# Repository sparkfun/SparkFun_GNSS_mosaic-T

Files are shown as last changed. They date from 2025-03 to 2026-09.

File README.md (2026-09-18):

SparkFun Timing GNSS Breakout - mosaic-T
========================================

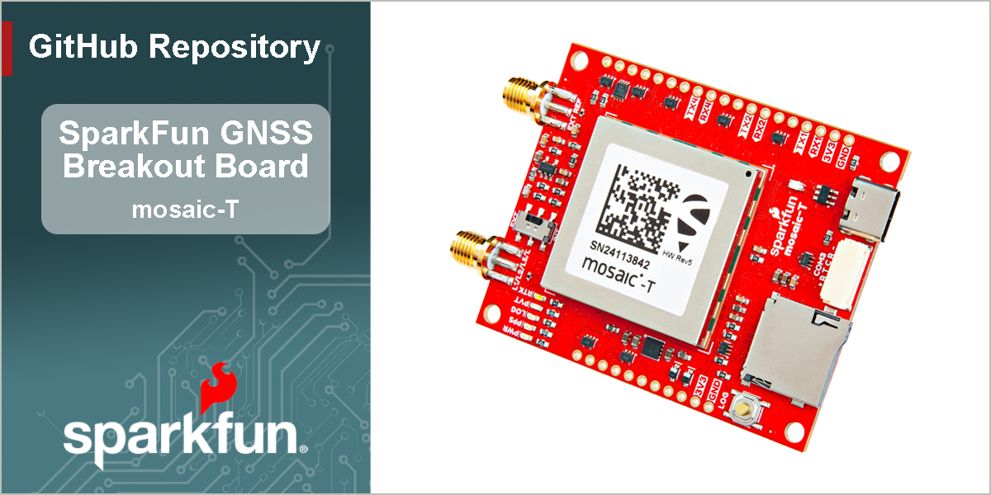
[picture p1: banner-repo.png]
SparkFun Timing GNSS Breakout - mosaic-T


[*SparkFun Timing GNSS Breakout - mosaic-T (GPS-28731)*](https://www.sparkfun.com/sparkfun-timing-gnss-breakout-mosaic-t.html)

At the heart of our Timing GNSS Breakout is [Septentrio](https://www.septentrio.com/en)'s mosaic-T, a compact, ultra-low power, multi-band, multi-constellation, high-precision GNSS timing receiver. It can acheive a timing precision of 5ns (5 billionths of a second), or better than 1ns with an optional subscription to the Fugro AtomiChron® L-band timing service. Event accuracy is better than 20ns. It also features Septentrio's unique [AIM+ technology](https://www.septentrio.com/en/learn-more/advanced-positioning-technology/aim-jamming-protection) for interference mitigation and anti-spoofing, ensuring best-in-class reliability and accuracy.

This board provides easy access to the mosaic-T's reference clock. Want to create your own disciplined oscillator? With this board you can. You can use the `RxClkBias` from the mosaic-T `PVTCartesian` or `PVTGeodetic` SBF messages to discipline your own 10MHz oscillator. The *EXT REF* connector accepts 50 Ohm 10MHz signals in the range -14dBm (min) to +14dBm (max). The *INT EXT* slide switch selects the internal or external oscillator.

The mosaic-T is a sophisticated timing receiver running an internal web server that can be accessed through the USB interface with a standard browser using a Linux/Windows computer. Septentrio also provides dozens of [video tutorials](https://www.youtube.com/@SeptentrioGNSS/videos) to guide users through the configuration settings of their GNSS receivers utilizing the web interface.

Beyond the capabilities of the mosaic-T module, this board is seamless to operate with no programming skills required. Gone are the times when a microcontroller was required to interface with the GNSS receiver and log data to an SD card and when users had to carry around an SD card reader to extract the data from the SD card. The Timing GNSS Breakout - mosaic-T  can start/stop logging data or mount/unmount the SD card, without a single line of code, just utilizing a simple button. For the users who prefer a command-line interface, Septentrio has you covered. Users can still control and configure the mosaic-T module through a CLI, which is useful for scenarios such as production line testing *(in fact, that is how we tested this board)*.

This breakout board is a perfect middle ground for users who would like to integrate the mosaic-T module into a project/enclosure with access to a majority of the module's available pins, similar to Septentrio's developer kit, but in the smaller form factor of their evaluation kit. Or maybe... you just needed a very accurate PPS output at a 3.3V logic level. *Please, check out our [hookup guide](https://docs.sparkfun.com/SparkFun_GNSS_mosaic-T) for more details on the capabilities of this board (that we couldn't fit in this product description).*

> [!CAUTION]
>
> RTK Not Supported
> --------------
> The mosaic-T is a superb GNSS module designed for highly accurate timing applications. **But it does not support RTK. It can not be configured as a RTK Rover or Base. RTCM output is not supported.**

Documentation
-------------

- **[Hookup Guide (mkdocs)](http://docs.sparkfun.com/SparkFun_GNSS_mosaic-T/)** - A hookup guide for the SparkFun mosaic-T Timing GNSS breakout board hosted by GitHub pages.<br>
   

Repository Contents
-------------------

- **[/docs](/docs/)** - Online documentation files
  - [/assets](/docs/assets/) - Assets files
    - [/3d_model](/docs/assets/3d_model/) - 3D models for the board
    - [/board_files](/docs/assets/board_files/) - Design files for the board
      - [KiCad Design Files](/docs/assets/board_files/kicad_files.zip) (.zip)
      - [Schematic](/docs/assets/board_files/schematic.pdf) (.pdf)
      - [Dimensions](/docs/assets/board_files/dimensions.pdf) (.pdf)
    - [/component_documentation](/docs/assets/component_documentation/) - Datasheets for hardware components
    - [/img/hookup_guide](/docs/assets/img/hookup_guide/) - Images for hookup guide documentation - Hookup guide images for the board
    - /Hardware - Hardware design files (.brd, .sch)
      - /Production - Production files

Product Variants
----------------

- mosaic-T:
  - [GPS-28731](https://www.sparkfun.com/sparkfun-timing-gnss-breakout-mosaic-t.html) - mosaic-T Timing GNSS Breakout
  - [SXT](https://www.sparkpnt.com/products/sxt-gnssdo) - GNSS Disciplined Oscillator
- mosaic-X5:
  - [GPS-23088](https://www.sparkfun.com/sparkfun-triband-gnss-rtk-breakout-mosaic-x5.html) - Triband GNSS RTK Breakout - mosaic-X5
  - [SXM-E](https://www.sparkpnt.com/products/sparkpnt-sxm-e-cors) - RTK mosaic-X5
  - [GPS-24903](https://www.sparkfun.com/sparkpnt-rtk-facet-mosaic-l-band.html) - SparkPNT RTK Facet mosaic L-Band
  - Flex Modules:
    - [GPS-28138](https://www.sparkfun.com/sparkpnt-gnss-flex-module-mosaic-x5.html) - GNSS Flex module - mosaic-X5
    - [GPS-29457](https://www.sparkfun.com/sparkpnt-gnss-flex-module-mosaic-x5-im19-imu.html) - GNSS Flex module - mosaic-X5 & IM19
    - [GPS-28766](https://www.sparkfun.com/sparkfun-gnss-flex-phat-mosaic-x5.html) - GNSS Flex pHAT w/ the mosaic-X5 GNSS Flex module
    - [GPS-29889](https://www.sparkfun.com/sparkfun-gnss-flex-phat-mosaic-x5-im19-imu.html) - GNSS Flex pHAT w/ the mosaic-X5 & IM19 GNSS Flex module
- mosaic-G5 P3:
  - [GPS-29208]( - GNSS RTK Breakout - mosaic-G5 P3
  - Flex Modules:
    - [GPS-29209](https://www.sparkfun.com/sparkpnt-gnss-flex-module-mosaic-g5-p3.html) - GNSS Flex module - mosaic-G5 P3
    - [GPS-29363](https://www.sparkfun.com/sparkpnt-gnss-flex-module-mosaic-g5-p3-im19-imu.html) - GNSS Flex module - mosaic-G5 P3 & IM19
    - [GPS-](https://www.sparkfun.com/sparkfun-gnss-flex-phat-mosaic-g5-p3.html) - GNSS Flex pHAT w/ the mosaic-G5 P3 GNSS Flex module
    - [GPS-](https://www.sparkfun.com/sparkfun-gnss-flex-phat-mosaic-g5-p3-im19-imu.html) - GNSS Flex pHAT w/ the mosaic-G5 P3 & IM19 GNSS Flex module

Version History
---------------

- [v10](https://github.com/sparkfun/SparkFun_GNSS_mosaic-T/releases/tag/v10) - Initial Release

License Information
-------------------

This product is ***open source***!

Please review the [`LICENSE.md`](./LICENSE.md) file for license information.

If you have any questions or concerns about licensing, please contact technical support on our [SparkFun forums](https://community.sparkfun.com/).

Distributed as-is; no warranty is given.

- Your friends at SparkFun.

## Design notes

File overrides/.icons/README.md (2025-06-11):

.icons directory
====================
This folder should contain branding logos for the product documentation

## General Images
- `sfe.svg` - SparkFun flame logo
- `kicad-primary.svg` - Full KiCad logo

## Directory
- `logo` - Other available logos

## SVG Optimizer
- [Remove meta data from svg](https://jakearchibald.github.io/svgomg/)

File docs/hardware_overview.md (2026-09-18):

!!! danger "Important: Read Before Use!"
	!!! warning "ESD Sensitivity"
		The mosaic-T module is sensitive to [ESD](https://en.wikipedia.org/wiki/Electrostatic_discharge "Electrostatic Discharge"). Use a proper grounding system to make sure that the working surface and the components are at the same electric potential.

		??? info "ESD Precaution"
			As recommended by the manufacturer, we highly recommend that users take the necessary ESD precautions to avoid damaging their module.

			<div class="grid cards" markdown>

			<div markdown>

			<article class="video-500px" style="text-align: center; margin: auto;" markdown>
			<iframe src="https://www.youtube.com/embed/hrL5J6Q5gX8?si=jOPBat8rzMnL7Uz4&amp;start=26;&amp;end=35;" title="Septentrio: Getting Started Video (playback starts at ESD warning)" frameborder="0" allow="accelerometer; autoplay; clipboard-write; encrypted-media; gyroscope; picture-in-picture" allowfullscreen></iframe>
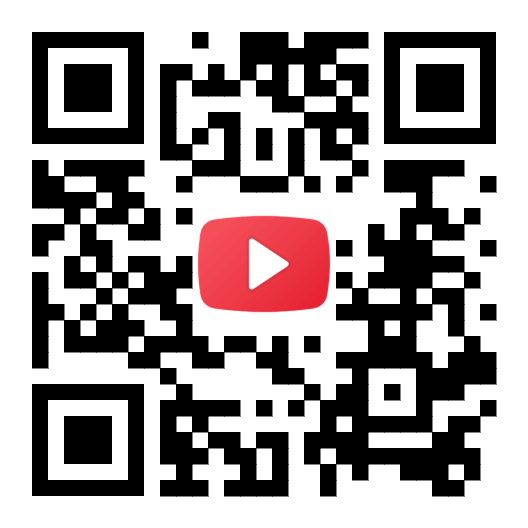
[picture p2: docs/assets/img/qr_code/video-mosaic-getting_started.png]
QR code to play video
			
			</article>

			</div>

			-   <a href="https://www.sparkfun.com/ifixit-anti-static-wrist-strap.html">
				<figure markdown>
				Product Thumbnail
				</figure>

				---

				**iFixit Anti-Static Wrist Strap**<br>
				TOL-25572</a>

			</div>

	!!! warning "Active Antenna"
		Never inject an external DC voltage into the SMA connector for the GNSS antenna, as it may damage the mosaic-T module. For instance, when using a splitter to distribute the antenna signal to several GNSS receivers, make sure that no more than one output of the splitter passes DC. Use [DC-blocks](https://en.wikipedia.org/wiki/DC_block) otherwise.

	!!! warning "External Reference Clock"
		If the switch for an external reference clock is enabled, users must provide a 10MHz input signal. Otherwise, the mosaic-T module will cease to operate, without a clock signal.

## :material-folder-cog: Design Files

<!-- Import the component -->
<script type="module" src="https://ajax.googleapis.com/ajax/libs/model-viewer/3.5.0/model-viewer.min.js"></script>

<div class="grid cards desc" markdown>

-   :kicad-primary:{ .enlarge-logo } Design Files

	---

	- :fontawesome-solid-file-pdf: [Schematic](./assets/board_files/schematic.pdf)
	- :material-folder-zip: [KiCad Files](./assets/board_files/kicad_files.zip)
	- :material-rotate-3d: [STEP File](./assets/3d_model/cad_model.step)
	- :fontawesome-solid-file-pdf: [Board Dimensions](./assets/board_files/dimensions.pdf):
		- 2.50" x 2.00" (635mm x 508mm)

-   <!-- Boxes in tabs -->

	=== "3D Model"
		<article style="text-align: center;" markdown>
		<model-viewer src="../assets/3d_model/web_model.glb" camera-controls poster="../assets/3d_model/poster.png" tone-mapping="neutral" shadow-intensity="2" shadow-softness="0.2" camera-orbit="0deg 75deg 0.103m" field-of-view="25.11deg" style="width: 100%; height: 450px;">
		</model-viewer>

		[Download the `*.step` File](./assets/3d_model/cad_model.step "Click download"){ .md-button .md-button--primary width="250px" }

		</article>

		???+ tip "Manipulate 3D Model"
			<article style="text-align: center;" markdown>

			| Controls       | Mouse                    | Touchscreen    |
			| :------------- | :----------------------: | :------------: |
			| Zoom           | Scroll Wheel             | 2-Finger Pinch |
			| Rotate         | ++"Left-Click"++ & Drag  | 1-Finger Drag  |
			| Move/Translate | ++"Right-Click"++ & Drag | 2-Finger Drag  |

			</article>

	=== "Dimensions"
		<article style="text-align: center;" markdown>
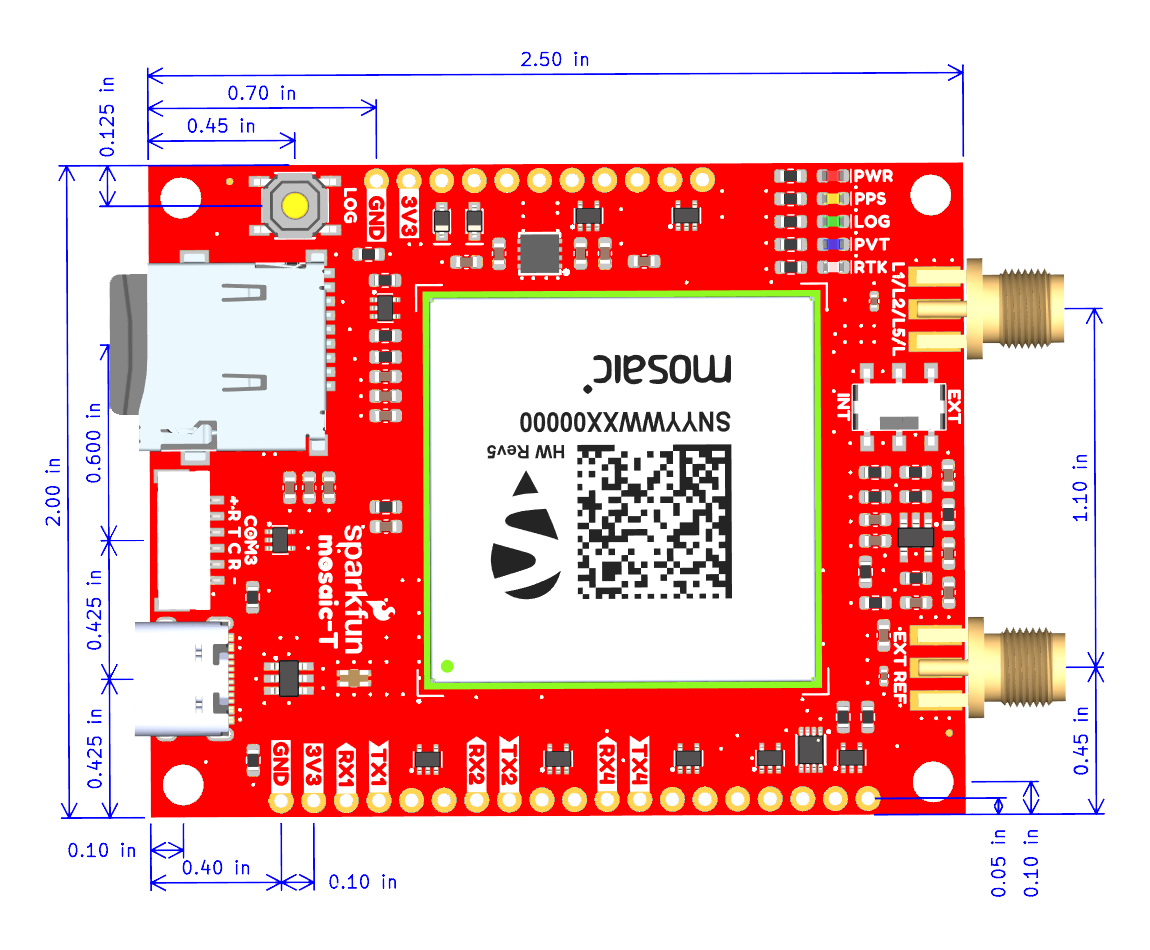
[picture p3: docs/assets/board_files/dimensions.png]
Board Dimensions
		
		<figcaption markdown>Dimensions of the mosaic-T Timing GNSS breakout board.</figcaption>
		</article>

		???+ tip "Need more measurements?"
			For more information about the board's dimensions, users can download the [KiCad files](./assets/board_files/kicad_files.zip) for this board. These files can be opened in KiCad and additional measurements can be made with the measuring tool.

			!!! info ":octicons-download-16:{ .heart } KiCad - Free Download!"
				KiCad is free, open-source [CAD]("computer-aided design") program for electronics. Click on the button below to download their software. *(\*Users can find out more information about KiCad from their [website](https://www.kicad.org/).)*

				<article style="text-align: center;" markdown>
				[Download :kicad-primary:{ .enlarge-logo }](https://www.kicad.org/download/ "Go to downloads page"){ .md-button .md-button--primary width="250px" }
				</article>

			???+ info ":straight_ruler: Measuring Tool"
				This video demonstrates how to utilize the dimensions tool in KiCad, to include additional measurements:

				<article class="video-500px" style="text-align: center; margin: auto;" markdown>
				<iframe src="https://www.youtube.com/embed/-eXuD8pkCYw" title="KiCad Dimension Tool" frameborder="0" allow="accelerometer; autoplay; clipboard-write; encrypted-media; gyroscope; picture-in-picture" allowfullscreen></iframe>
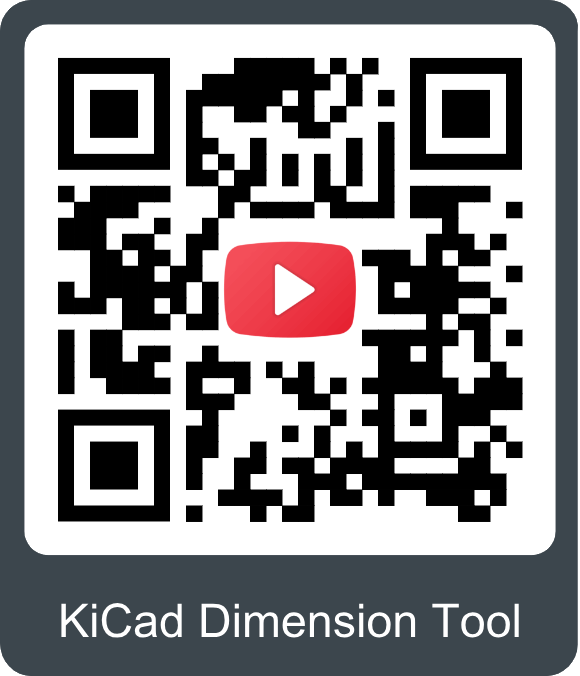
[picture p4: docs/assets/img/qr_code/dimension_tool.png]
QR code to play video
				
				</article>

</div>

## Board Layout
The SparkFun Timing GNSS Breakout - mosaic-T features the following:

<div class="grid" markdown>

<div markdown>

<figure markdown>
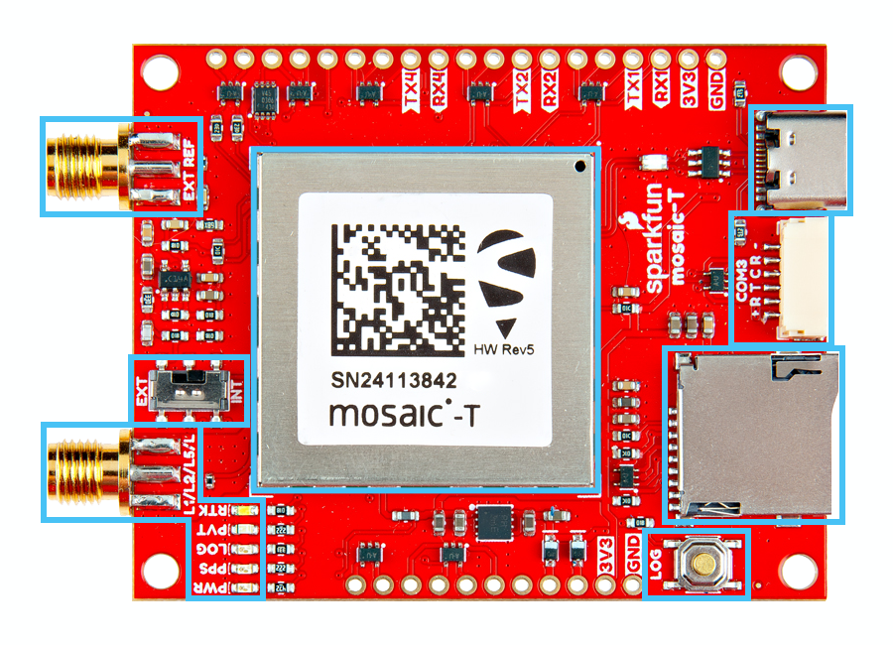
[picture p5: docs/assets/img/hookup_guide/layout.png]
Layout

<figcaption markdown>Layout of the major components on the breakout board.</figcaption>
</figure>

</div>

<div markdown>

1. **USB-C Connector**
:   The primary inteface for powering and interacting with the board
1. **6-Pin JST Connector**
:   A UART interface for the mosaic-T GNSS module
1. **&micro;SD Card Slot**
:   An SD card slot for data logging
1. **`LOG` Button**
:   A button to mount the SD card and intialize the data logging stream
1. **mosaic-T GNSS Module**
:	The Septentrio mosaic-T GNSS module
1. **Status LEDs**
:   LED status indicators for the mosaic-T GNSS module
1. **SMA Connectors**
	- `L1/L2/L5/L`: The input for a GNSS antenna
	- `EXT REF`: The input for an external reference clock signal
1. **`INT`/`EXT` Switch**
:   Used to switch between an internal or external refernce clock signal for the mosaic-T GNSS module. If switched to `EXT`, an external 10MHz signal must be provided for the GNSS module to function

</div>

</div>

## USB-C Connector
A USB connector is provided to power and interface with the mosaic-T GNSS receiver. For most users, it will be the primary method for communicating with the mosaic-T module.

<figure markdown>
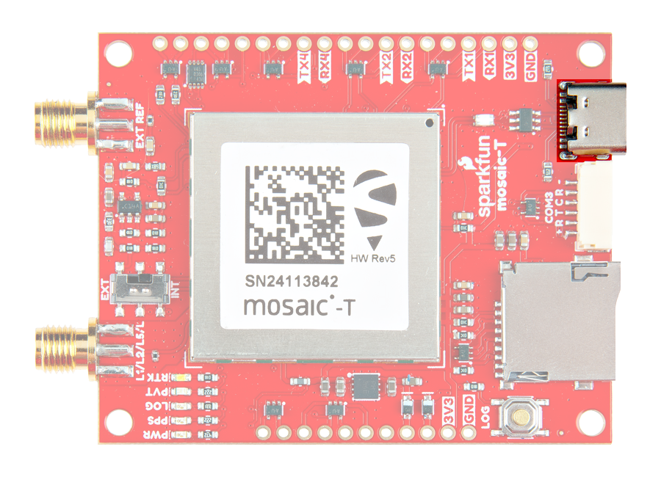
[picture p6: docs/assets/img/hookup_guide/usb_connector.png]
USB-C Connector

<figcaption markdown>USB-C connector on the mosaic-T Timing GNSS breakout board.</figcaption>
</figure>

!!! serial "Windows OS"
	For Windows computers, users will need to [install the USB driver](software_overview.md#usb-driver) before they can interact with the mosaic-T GNNS module.

!!! info
	For more details about this interface, please refer to the [**USB-C Connector** section](#usb-c-connector_1) below.

## Power
The simplest method to power the board is through the USB-C connector. However, the mosaic-T Timing GNSS breakout board only requires **3.3V** to power most of its components(1), which can be supplied though JST connector or [PTH](https://en.wikipedia.org/wiki/Through-hole_technology "Plated Through Holes") pins.
{ .annotate }

1. 5V is only required to utilize the USB interface; and when enabled, it can also power the JST connector.

<figure markdown>
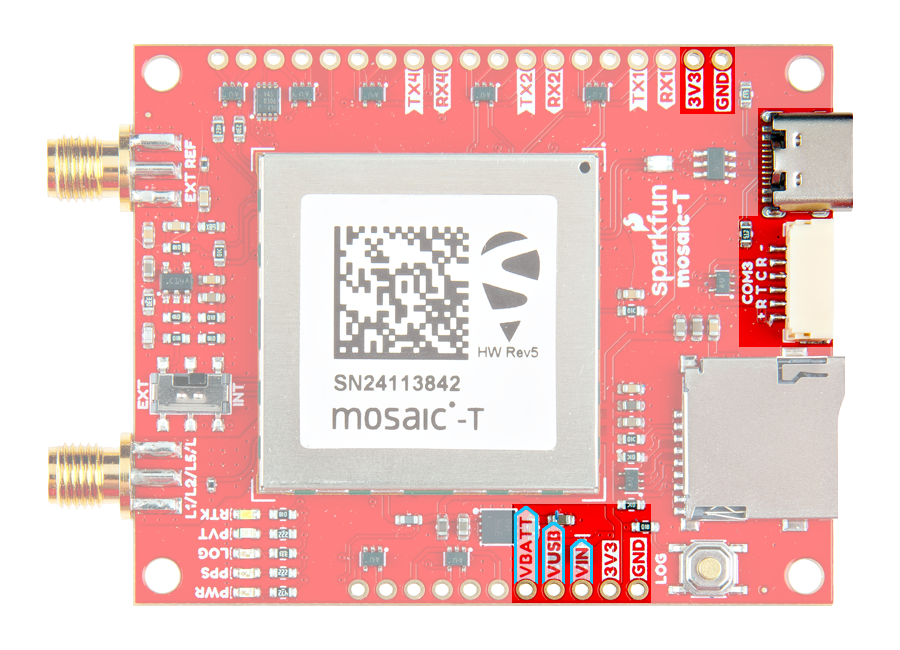
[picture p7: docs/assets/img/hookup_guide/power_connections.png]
Power connections

<figcaption markdown>mosaic-T Timing GNSS breakout board's power connections.</figcaption>
</figure>

Below, is a general summary of the power circuitry on the board, broken out as [PTH](https://en.wikipedia.org/wiki/Through-hole_technology "Plated Through Holes") pins:

<div class="annotate" markdown>

- **`VUSB`** - The voltage from the USB-C connector, usually **5V**.
	- Input Voltage Range: 2.2 - 5.5 V
	- Power source for the entire board.
		- Powers the 3.3V voltage regulator (AP7361C) and when enabled, it can also power the JST connector. (1)
		- This pin powers the integrated PHY of the mosaic-T module's USB interface.
- **`VIN`** - Alternate input supply voltage for the board.
	- Input Voltage Range: 2.2 - 6 V
	- Alternative power supply input for the board, excluding the integrated PHY of the USB interface.
		- Powers the 3.3V voltage regulator (AP7361C) and when enabled, it can also power the JST connector. (2)
- **`3V3`** - Provides a regulated 3.3V from [AP7361C](./assets/component_documentation/AP7361C.pdf) using the power from the `VIN` or `VUSB` (5V) inputs.
	- Input Voltage Range: 3.135 - 3.465 V
	- The **3.3V** AP7361C LDO regulator can source up to 1A.
		- Used to power the mosaic-T module, SD card slot, power LED, and the active antenna preamplifier for the mosaic-T module.
- **`VBATT`** - *Always-on* power supply
	- Input Voltage Range: 3.135 - 3.465 V
	- Tied to `3.3V` *(see the **[Jumpers](#jumpers)** section)*.
		- Used to power the module in **Standby** mode.
- **`GND`** - The common ground or the 0V reference for the voltage supplies.

</div>

1. While the [AP7361C](./assets/component_documentation/AP7361C.pdf) LDO regulator has an input voltage range of 2.2 - 6V, users should supply:
	- A minimum of **3.5V** for a 3.3V output from the regulator
	- A maximum of **5.5V** as not to exceed the electrical limitations of the mosaic-T module
1. While the [AP7361C](./assets/component_documentation/AP7361C.pdf) LDO regulator has an input voltage range of 2.2 - 6V, a minimum supply voltage of **3.5V** is recommended for a 3.3V output.

!!! tip "JST Connector"
	The `V` pin of the JST connector is designed to operate as a voltage output. However, an input voltage can be supplied through the connector, but users should be mindful of any voltage contention issues.

!!! info
	For more details, users can reference the [schematic](./assets/board_files/schematic.pdf) and the datasheets of the individual components on the board.

### Power Modes
The mosaic-T module operates in three different power states:

<div class="grid" markdown>

<div markdown>

<figure markdown>
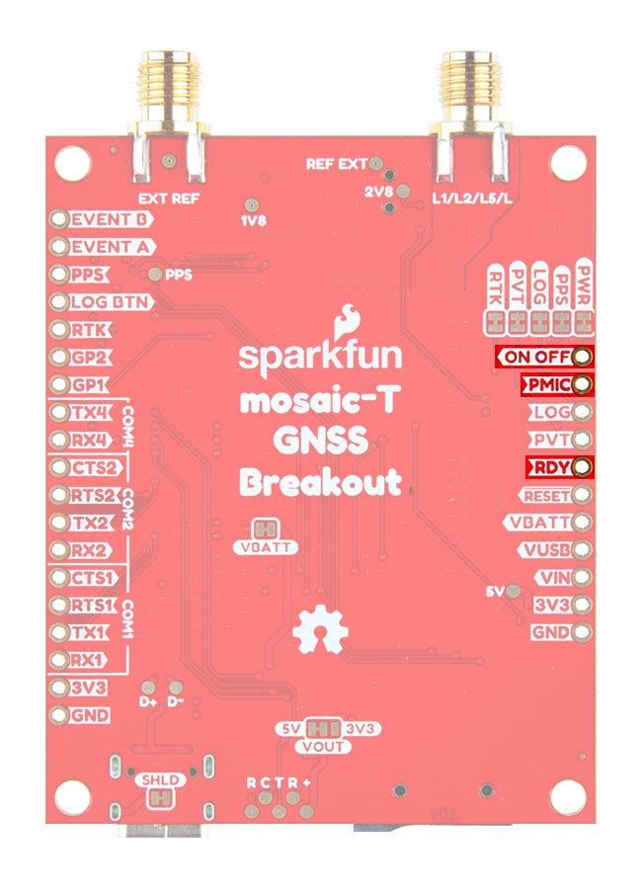
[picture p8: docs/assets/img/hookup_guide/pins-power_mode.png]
Power management pins

<figcaption markdown>The power management pins of the mosaic-T Timing GNSS breakout board.</figcaption>
</figure>

</div>

<div class="annotate" markdown>

- **Off** - The module is completely turned off
	- When transitioning to the **Off** state from **Active**, recent data may not be lost and not logged to the external SD card
- **Standby** - The module is in a low-power consumption mode (1)
	- The module power consumption in standby is <5mW
	- The `PMIC` pin is driven `LOW`
	- The `RDY` pin is in a `LOW`
	- When the `ON OFF` pin is driven `LOW` for at least 50ms, the module toggles between its **Standby** and **Active** states
- **Active** - The module is operating with all functions active
	- On power up, the module restarts in the configuration stored in the boot configuration file
	- The `PMIC` pin is driven `HIGH`
	- The `RDY` pin is in a `HIGH` (2)

</div>

1. Essentially, the same state as **Off**; except in the transition to the **Standby** mode, before the module shuts down:
	- All logging tasks are terminated
	- The SD card is unmounted
	- The `PMIC` pin is driven `LOW`
1. Level becomes `HIGH` about 300ms after powering up, reset, or waking up from standby

</div>

!!! info
	For more information on the power management of the mosaic-T module, please refer to sections **3.4**, **3.5**, **4.1**, and **4.13** of the [hardware manual](./assets/component_documentation/mosaic_hardware_manual_v1.11.0.pdf).

??? tip "Drive Current"
	The drive current on the `PMIC`, `RDY`, and `ON OFF` pins is minimal. Enough to be read by a digital pin on a microcontroller, but not high enough to drive an LED.

### Power Consumption
The power consumption of the mosaic-T module depends on the GNSS signals enabled and the positioning mode. The table below, lists the average power consumption for common configurations. The current listed, is based on a supply voltage of 3.3V.

<article style="text-align: center;" markdown>

| GNSS Signals | Positioning Mode | Power (mW) | Current (mA) |
| :--- | :--- | :---: | :---: |
| GPS L1 C/A | Stand-Alone (1Hz) | 550 | 167 |
| GPS L1/L2 | RTK (1Hz) | 670 | 203 |
| GPS/GLONASS L1/L2 | RTK (1Hz) | 695 | 211 |
| GPS/GLONASS L1/L2+GALILEO L1/E5a +BeiDou B1C/B2a | RTK (1Hz) | 850 | 258 |
| GPS/GLONASS L1/L2+GALILEO L1/E5a +BeiDou B1C/B2a | RTK (100 Hz) | 930 | 282 |
| GPS/GLONASS L1/L2 + L-band | PPP (1Hz) | 760 | 230 |
| All signals from all GNSS constellations | Static (1Hz) | 910 | 276 |
| All signals from all GNSS constellations +L-band | Static(1Hz) | 980 | 297 |
| All signals from all GNSS constellations +L-band | Static (100Hz) | 1080 | 327 |

*Source: [mosaic-T Hardware Manual](./assets/component_documentation/mosaic_hardware_manual_v1.11.0.pdf)*
</article>

## :fontawesome-solid-microchip:&nbsp; mosaic-T
The centerpiece of the mosaic-T Timing GNSS breakout board, is the [mosaic-T module](./assets/component_documentation/mosaic_hardware_manual_v1.11.0.pdf) from [Septentrio](https://www.septentrio.com/en). Their mosaic modules are low-power, multi-band, multi-constellation GNSS receivers capable of delivering centimeter-level precision at high update rates. The modules also feature Septentrio's unique [AIM+ technology](https://www.septentrio.com/en/learn-more/advanced-positioning-technology/aim-resilient-and-secure-gnss/gps-receivers) for interference mitigation and anti-spoofing, which ensures their best-in-class reliability and scalable position accuracy.

<div class="grid" markdown>

<div markdown>

<article class="video-500px" style="text-align: center; margin: auto;" markdown>
<iframe src="https://www.youtube.com/embed/Co8hrVeklAA" title="Septentrio: Mosaic - GNSS / GPS module receiver range" frameborder="0" allow="accelerometer; autoplay; clipboard-write; encrypted-media; gyroscope; picture-in-picture" allowfullscreen></iframe>
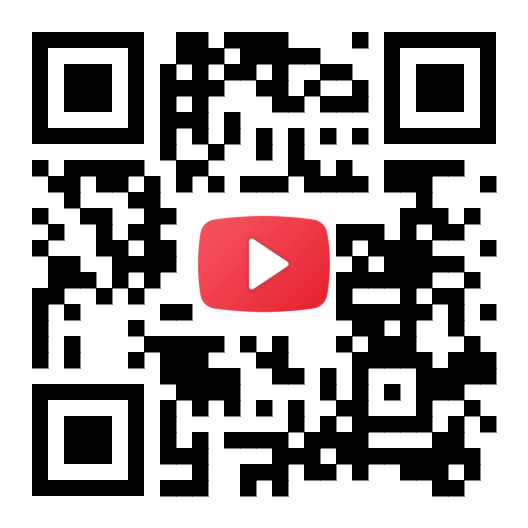
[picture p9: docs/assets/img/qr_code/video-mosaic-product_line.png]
QR code to play video

</article>

!!! warning "RTK Not Supported"
	The mosaic-T is a superb GNSS module designed for highly accurate timing applications. **But it does not support RTK. It can not be configured as a RTK Rover or Base. RTCM output is not supported.**

</div>

<div markdown>

<figure markdown>
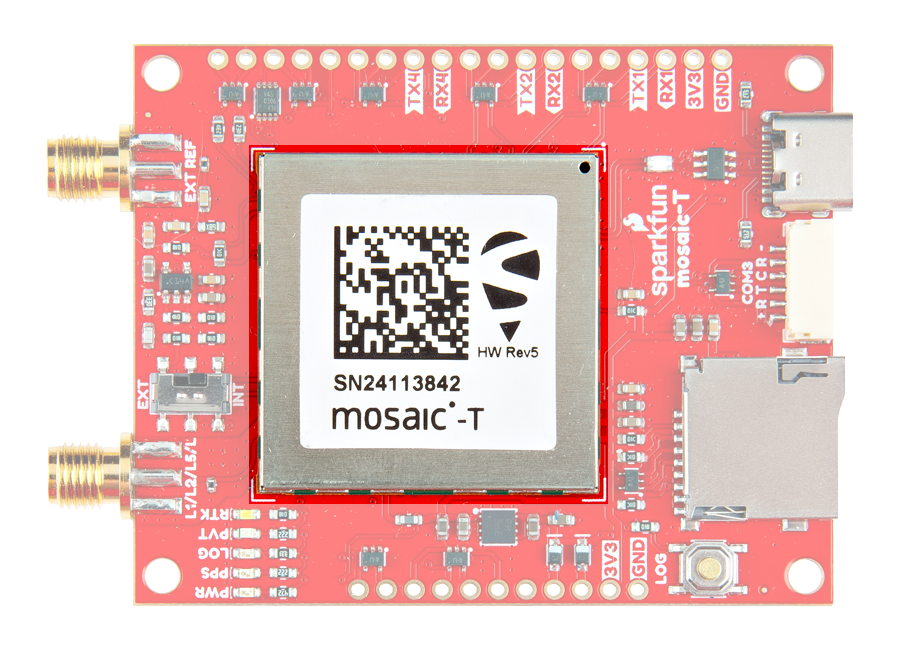
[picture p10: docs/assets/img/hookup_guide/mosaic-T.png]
mosaic-T module

<figcaption markdown>The mosaic-T module on the mosaic-T Timing GNSS breakout board.</figcaption>
</figure>

</div>

</div>

<div class="grid" markdown>

<div markdown>

**Features:**

- Operating Voltage: **3.135 - 3.465V**
- Operating Temperature: -40 - 85&deg;C
- GNSS Support
	- GPS: L1C/A, L1PY, L2C, L2P, L5
	- GLONASS: L1CA, L2CA, L2P, L3 CDMA
	- Beidou: B1I, B1C, B2a, B2b, B2I, B3
	- Galileo: E1, E5a, E5b, E5 AltBoc, E6
	- QZSS: L1C/A, L1 C/B, L2C, L5
	- Navic: L5
	- SBAS: Egnos, WA
- Antenna Specifications
	- Preamplification Range: 15-50dB
	- Bias Voltage: 3.0 - 5.5V
	- 448 Hardware Channels
- Update Rate: 100Hz
- Latency: < 10ms

</div>

<div markdown>

<br>

- Time to Fix
	- Cold Start: < 45s
	- Warm: < 20s
	- Reacquisition: 1s
- Timing Precision: 5ns
- Position Accuracy

	<article style="text-align: center;" markdown>

	| Correction | Horizontal                             | Vertical                     |
	| :--------- | :------------------------------------: | :--------------------------: |
	| DGNSS      | 40cm<br>~1.3'                          | 70cm<br>~2.3'                |
	| SBAS       | 60cm<br>~2'                            | 80cm<br>~2.6'                |
	| Standalone | 1.2m<br>~4'                            | 1.9m<br>~6.2'                |

	</article>

</div>

</div>

!!! info
	The mosaic-T has three power modes: **Active**, **Standby**, and **Off** *(see the **[Power Modes](#power-modes)** section)*.

### Frequency Bands
The mosaic modules are multi-band, multi-constellation GNSS receivers. Below, are charts illustrating the frequency bands utilized by all the global navigation satellite systems and the ones supported by the mosaic-T module.

<figure markdown>
Supported frequency bands
<figcaption markdown>The frequency bands supported by the mosaic-T GNSS receiver.</figcaption>
</figure>

<figure markdown>
GNSS frequency bands (https://www.tallysman.com/app/uploads/2021/07/Tallysman-GNSS-Frequencies-v8.0_Chart-1-1024x425.png "Click to enlarge")
<figcaption markdown>Frequency bands of the global navigation satellite systems. (Source: [Tallysman](https://www.tallysman.com/gnss-constellations-radio-frequencies-and-signals/))</figcaption>
</figure>

!!! info
	For a comparison of the frequency bands supported by the mosaic modules, refer to section **3.1** of the [hardware manual](./assets/component_documentation/mosaic_hardware_manual_v1.11.0.pdf).

	??? info "What are Frequency Bands?"
		A [frequency band](https://en.wikipedia.org/wiki/Frequency_band) is a section of the [electromagnetic spectrum](https://en.wikipedia.org/wiki/Electromagnetic_spectrum), usually denoted by the range of its upper and lower limits. In the [radio spectrum](https://en.wikipedia.org/wiki/Radio_spectrum), these frequency bands are usually regulated by region, often through a government entity. This regulation prevents the interference of RF communication; and often includes major penalties for any interference with critical infrastructure systems and emergency services.

		<figure markdown>
		GNSS frequency bands (https://gssc.esa.int/navipedia/images/c/cf/GNSS_All_Signals.png "Click to enlarge")
		<figcaption markdown>Frequency bands of the global navigation satellite systems. (Source: [ESA](https://gssc.esa.int/navipedia/index.php?title=File:GNSS_All_Signals.png "European Space Agency"))</figcaption>
		</figure>

		However, if the various GNSS constellations share similar frequency bands, then how do they avoid interfering with one another? Without going too far into detail, the image above illustrates the frequency bands of each system with a few characteristics specific to their signals. Wit these characteristics in mind, along with other factors, the chart can help users to visualize how multiple GNSS constellations might co-exist with each other.

		For more information, users may find these articles of interest:

		- [GNSS signal](https://gssc.esa.int/navipedia/index.php/GNSS_signal)
		- [GPS Signal Plan](https://gssc.esa.int/navipedia/index.php?title=GPS_Signal_Plan)
		- [GLONASS Signal Plan](https://gssc.esa.int/navipedia/index.php?title=GLONASS_Signal_Plan)
		- [GALILEO Signal Plan](https://gssc.esa.int/navipedia/index.php?title=GALILEO_Signal_Plan)

### Position Accuracy

!!! warning "RTK Not Supported"
	The mosaic-T is a superb GNSS module designed for highly accurate timing applications. **But it does not support RTK. It can not be configured as a RTK Rover or Base. RTCM output is not supported.**

<div class="grid" markdown>

<div markdown>

<article style="text-align: center;" markdown>

| Correction | Horizontal | Vertical |
| :--- | :---: | :---: |
| [DGNSS](https://en.wikipedia.org/wiki/Differential_GPS "Differential GNSS") | 40cm<br>~1.3' | 70cm<br>~2.3' |
| [SBAS](https://en.wikipedia.org/wiki/GNSS_augmentation "Satellite-Based Augmentation System") | 60cm<br>~2' | 80cm<br>~2.6' |
| Standalone | 1.2m<br>~4' | 1.9m<br>~6.2' |

</article>

</div>

</div>

!!! tip
	For the best performance, we highly recommend that users select a compatible L1/L2/L5 (tri-band) GNSS antenna and utilize a low-loss cable.

## Peripherals and I/O Pins
The mosaic-T features several peripherals and I/O pins. Some of these are broken out as pins on the mosaic-T Timing GNSS breakout board; whereas, others are broken out to their specific interface *(i.e. &micro;SD Card slot, USB connector, etc.)*. Additionally, some of the pin connections are shared with other components or interfaces.

<div class="grid cards" markdown>

<div markdown>

<figure markdown>
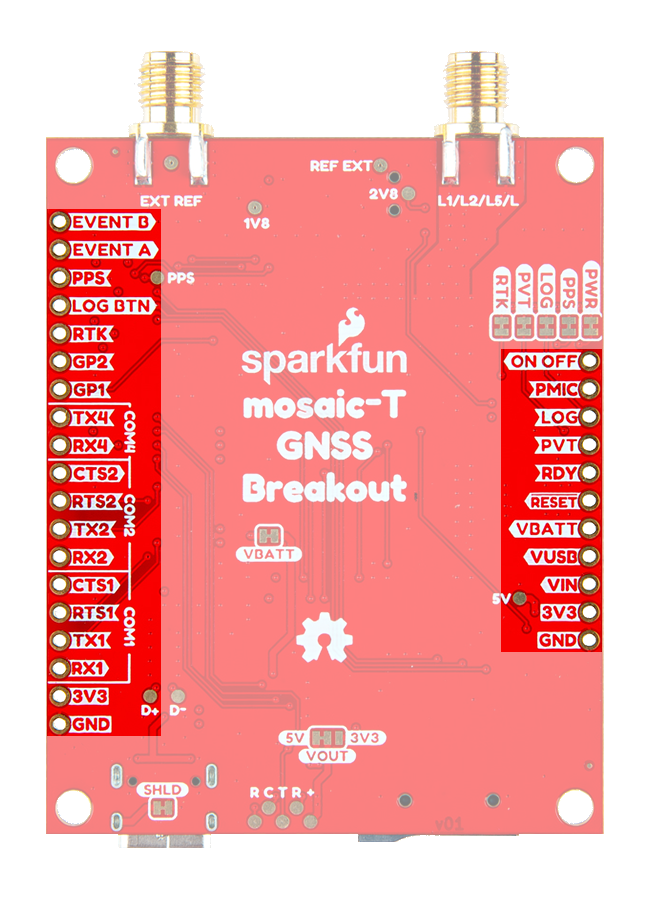
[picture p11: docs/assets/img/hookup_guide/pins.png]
I/O pins

<figcaption markdown>The I/O pins on the mosaic-T Timing GNSS breakout board.</figcaption>
</figure>

</div>

<div markdown>

<figure markdown>
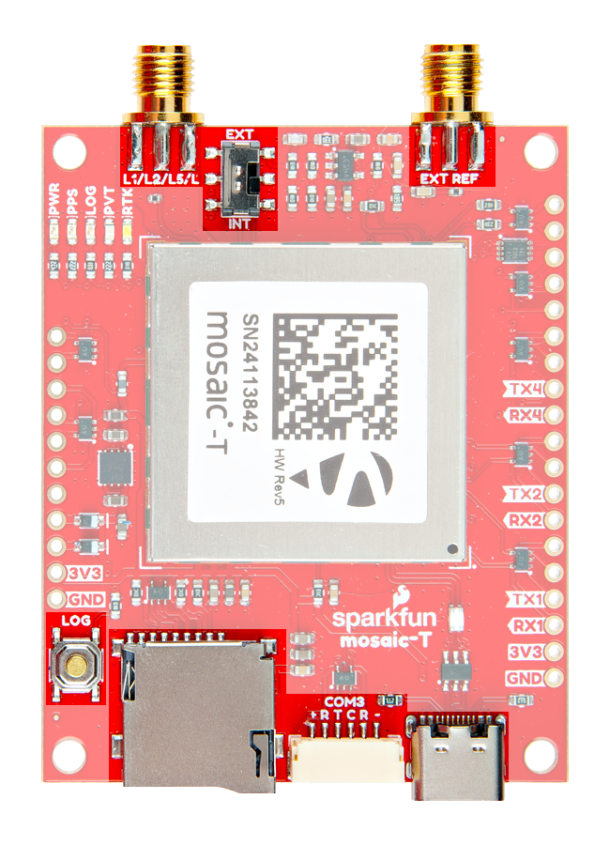
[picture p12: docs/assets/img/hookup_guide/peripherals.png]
Peripherals

<figcaption markdown>The peripheral interfaces of the mosaic-T Timing GNSS breakout board.</figcaption>
</figure>

</div>

<div markdown>

<article class="annotate" markdown>
**Interfaces:**

- 4x UART (LVTTL, up to 4 Mbps)
- ~~Ethernet (RMII/MDIO), 10/100 Mbps~~(1)
- USB device (2.0, HS)
- SDIO (mass storage)
- 2x GPIO user programmable
- 2x Event markers
- 1x Configurable PPS out

</article>

1. Not available on the mosaic-T Timing GNSS breakout board.

</div>

</div>

### I/O Pins
There are thirty I/O pins on the mosaic-T Timing GNSS breakout board, most of which are connected to other interfaces and components of the board. The tabulated section below, details the aspects of each pin based on their function.

=== "UARTs"

	<div class="grid" markdown>

	<div markdown>

	<figure markdown>
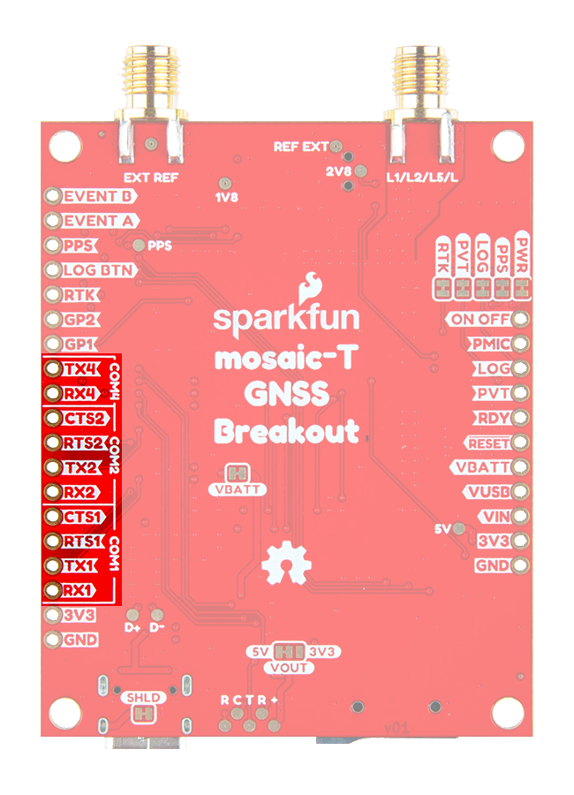
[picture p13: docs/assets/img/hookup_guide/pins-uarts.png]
UART I/O pins
	
	<figcaption markdown>The `COM` pins on the mosaic-T Timing GNSS breakout board.</figcaption>
	</figure>

	</div>

	<div markdown>

	The mosaic-T has four UARTs that are organized into separate `COM` ports, three of which are available through [PTH](https://en.wikipedia.org/wiki/Through-hole_technology "Plated Through Holes") pins. The operation for each of these ports can be configured separately.

	- `COM` ports 1-3 feature flow control pins, which are disabled by default.
	- These ports also support a point-to-point protocol server, by which it can accept TCP/IP connections over a serial link.

	!!! info
		By default, the `COM` ports will be configured with the following settings:

		- Baudrate: 115200bps
		- Data Bits: 8
		- Parity: No
		- Stop Bits: 1
		- Flow Control: None

	???+ tip "Where is `COM3`?"
		`COM3` is available through the [JST connector](#jst-connector), but the pins can also be accessed from the pads on the bottom of the board.

	??? tip "Pin Connections"
		When connecting to the board's UART pins, the pins should be connected based upon the flow of their data. For example, when utilizing the [Telemetry Radio](https://www.sparkfun.com/sik-telemetry-radio-v3-915mhz-100mw.html) or the [LoRaSerial Kit](https://www.sparkfun.com/sparkfun-loraserial-kit-915mhz-enclosed.html):

		<figure markdown>
		Flow Control (https://docs.sparkfun.com/SparkFun_LoRaSerial/img/SAMD21%20Flow%20control.png "Click to enlarge")
		<figcaption markdown>Connection of the UART pins from the [LoRaSerial radio](https://www.sparkfun.com/sparkfun-loraserial-kit-915mhz-enclosed.html) to a host system, like the mosaic-T Timing GNSS breakout board.</figcaption>
		</figure>

	</div>

	</div>

=== "PPS Output"

	<div class="grid" markdown>

	<div markdown>

	<figure markdown>
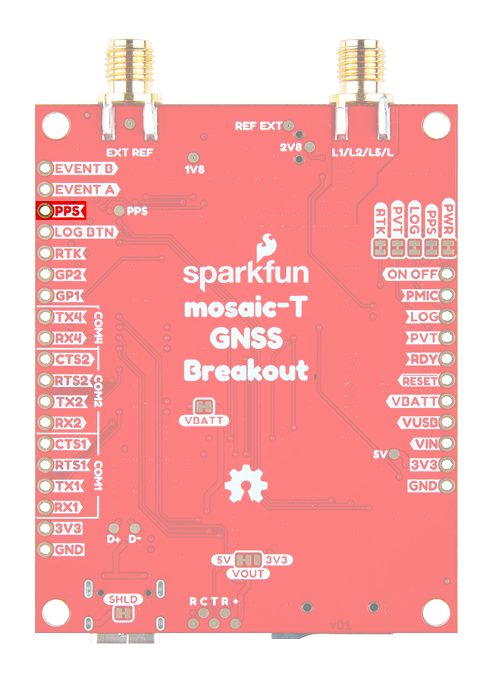
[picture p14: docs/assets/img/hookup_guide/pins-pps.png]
PPS signal I/O pin
	
	<figcaption markdown>The `PPS` output signal on the mosaic-T Timing GNSS breakout board.</figcaption>
	</figure>

	</div>

	<div markdown>

	From the module, the [PPS](https://en.wikipedia.org/wiki/Pulse-per-second_signal "Pulse Per Second") output signal's logic-level is 1.8V. However, for the convenience of users, we have added a buffer and bumped up the signal's logic-level to 3.3V on the mosaic-T Timing GNSS breakout board. This 3.3V signal output can be access through the `PPS` pin. The signal is also connected to the [`PPS` LED](#status-leds), to be used as a visual indicator.

	??? tip "Disable LED"
		There is a [jumper](#jumpers) attached to the `PPS` LED. For low power applications, users can cut the jumper to disable the `PPS` LED.

	???+ example "Use Case"
		- Users could use this signal in conjunction with the event pins to synchronize two mosaic-T modules with each other.
		- Users could use this signal to create their own **Stratum 0** source for the [NTP](https://en.wikipedia.org/wiki/Network_Time_Protocol "Network Time Protocol") on a primary time server.

	</div>

	</div>

=== "Data Logging"

	<div class="grid" markdown>

	<div markdown>
	
	<figure markdown>
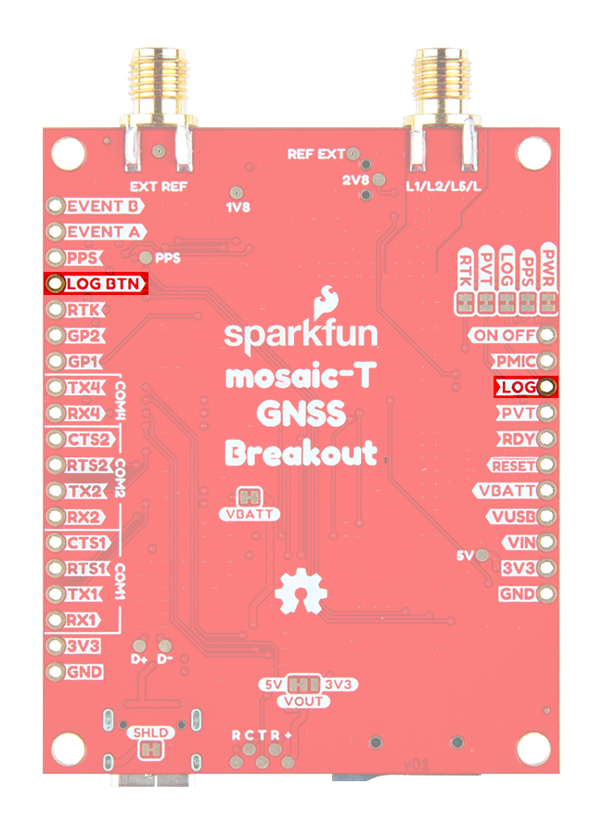
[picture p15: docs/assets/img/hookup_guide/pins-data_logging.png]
Data logging I/O pins
	
	<figcaption markdown>The data logging pins on the mosaic-T Timing GNSS breakout board.</figcaption>
	</figure>

	</div>

	<div markdown>

	The data logging functionality of the board can be configured through the software/web interfaces and operated through the use of the [++"LOG"++ button](#log-button) or `LOG BTN` pin. Data logging activity will be indicated by the [`LOG` LED](#status-leds).

	- `LOG BTN` - Connected to the ++"LOG"++ button and tied to the same active-high, input of the mosaic-T
	- `LOG` - Connected to the `LOG` LED

	!!! success "Initial Configuration"
		Before data logging can occur, it is necessary to create a *logging stream* from the **Logging** tab of the web interface or using the **RxTools** software suite. Streams can contain NMEA or SBF (Septentrio Binary Format) data; SBF can contain RTCM and/or RINEX. *(see the [Data Logging](web_interface.md#data-logging) section)*

	!!! info "Operation"
		The data logging feature can be controlled on the board through either the [++"LOG"++ button](#log-button) or `LOG BTN` pin.

		- Pressing the button or pin `LOW` *(< 5s)* toggles data logging to the SD card on and off.
		- Holding the button or pin `LOW` for more than 5 seconds *(> 5s)* and then releasing it, will force the board to:
			- Unmount the SD card if it was mounted
			- Mount the SD card if it was unmounted

	??? question "Status"
		The status of the SD card and data stream are indicated on the `LOG` LED and pin.

		<article style="text-align: center;" markdown>

		| Pin    | LED      | Status                           |
		| :----: |:-------: | :------------------------------- |
		| Low    | Off      | SD card not present or unmounted |
		| High   | On       | SD card present and mounted      |
		| Pulses | Blinking | Data logging activity            |

		</article>

	</div>

	</div>

=== "LED Pins"

	<div class="grid" markdown>

	<div markdown>
	
	<figure markdown>
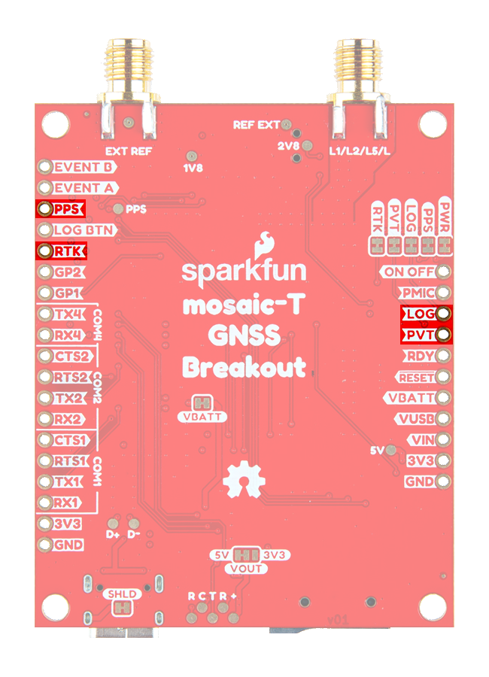
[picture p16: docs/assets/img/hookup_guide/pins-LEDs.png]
LED I/O pins
	
	<figcaption markdown>The LED pins on the mosaic-T Timing GNSS breakout board.</figcaption>
	</figure>

	</div>

	<div markdown>

	The mosaic-T module features two general purpose, output LED pins. These pins have a maximum output current of 10 mA and output impedance of 20&ohm;. In addition, to these pins, there are other [status LEDs](#status-leds) connected to other signals on the board.

	- The general purpose LED signals are connected to the `RTK` and `PVT` pins; and respectively, the `RTK` and `PVT` LEDs.
	- The [PPS](https://en.wikipedia.org/wiki/Pulse-per-second_signal "Pulse Per Second") output signal is connected to the `PPS` pin and `PPS` LED.
	- The `LOG` pin is connected to the `LOG` LED.

	!!! info
		For more details, please refer to the [**Status LEDs**](#status-leds) section.

	</div>

	</div>

=== "GPx Pins"
	The mosaic-T module features two general purpose, output pins. These pins can drive a maximum current of 10mA.

	<figure markdown>
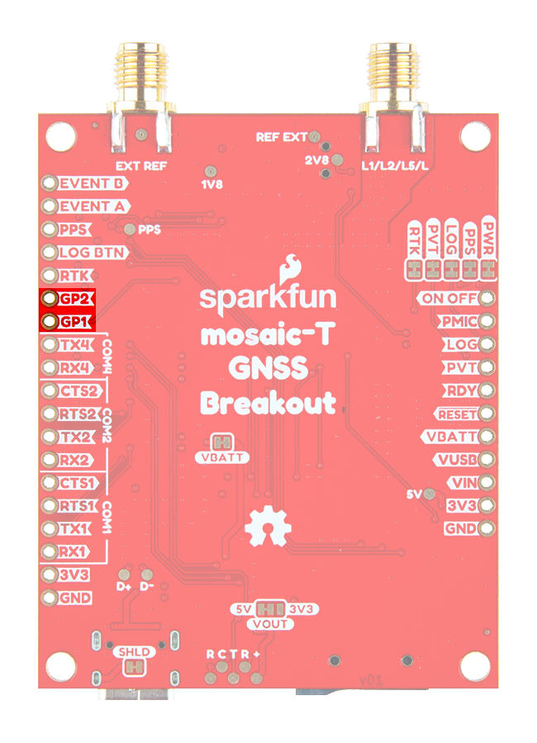
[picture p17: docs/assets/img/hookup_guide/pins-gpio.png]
General purpose I/O pins
	
	<figcaption markdown>The `GPx` pins on the mosaic-T Timing GNSS breakout board.</figcaption>
	</figure>

=== "Event Pins"
	The mosaic-T module features two general purpose, event input pins. These pins can be used to time tag external events with a time resolution of 20ns.

	<figure markdown>
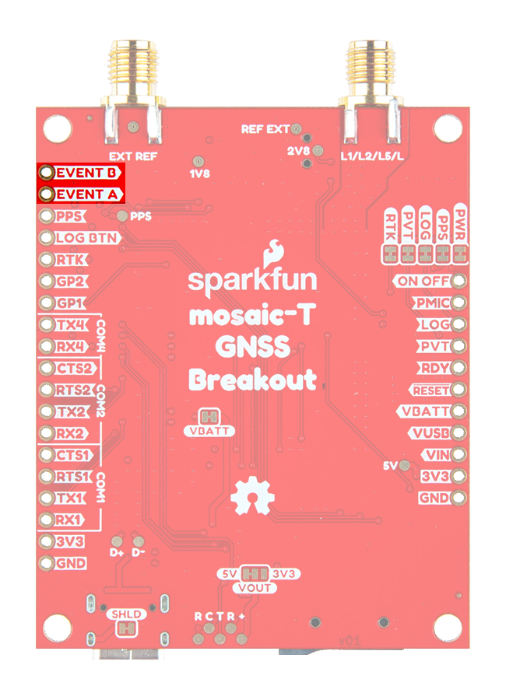
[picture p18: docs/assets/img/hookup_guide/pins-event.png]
Event trigger I/O pins
	
	<figcaption markdown>The event pins on the mosaic-T Timing GNSS breakout board.</figcaption>
	</figure>

	??? example
		For example, these pins can be used in conjunction with the PPS output signal for time syncing.

=== "Power Management Pins"

	<div class="grid" markdown>

	<div markdown>

	<figure markdown>
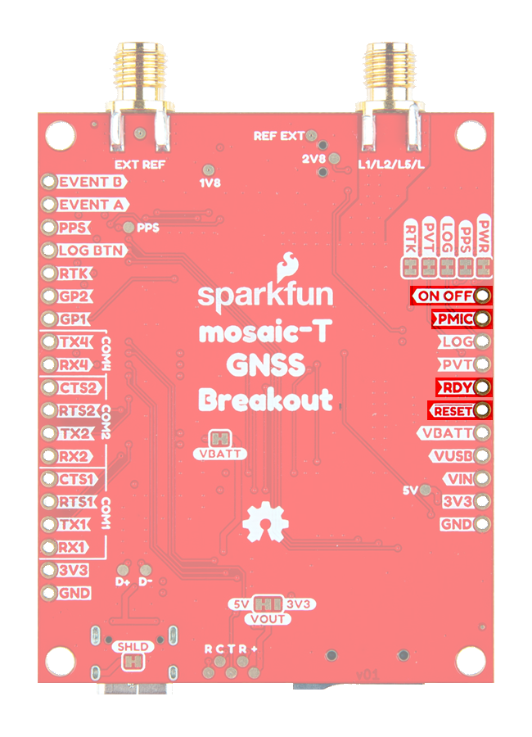
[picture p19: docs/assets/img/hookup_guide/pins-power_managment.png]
Power management I/O pins
	
	<figcaption markdown>The power managment pins on the mosaic-T Timing GNSS breakout board.</figcaption>
	</figure>

	</div>

	<div markdown>

	**Reset**

	- `Reset` Pin
	:	Used to reset the mosaic-T module.

	**Power Mode**

	!!! info
		For more details, please refer to the [**Power Modes** section](#power-modes).

	- `RDY` Pin
	:	The `RDY` pin indicates the operational mode of the mosaic-T module. The level is high when module is operating, and low when in standby or reset.
	- `PMIC` Pin
	:	The `PMIC` pin is typically connected to a power switch or the control pin for the primary power supply, which is used to transition the module between its **Active** and **Standby** states.
	- `ON OFF` Pin
	:	When the `ONOFF` pin is driven `LOW` *(>50ms)*, the module toggles between its **Active** and **Standby** states.

	</div>

	</div>

=== "Power Supply Pins"

	<div class="grid" markdown>

	<div markdown>

	<figure markdown>
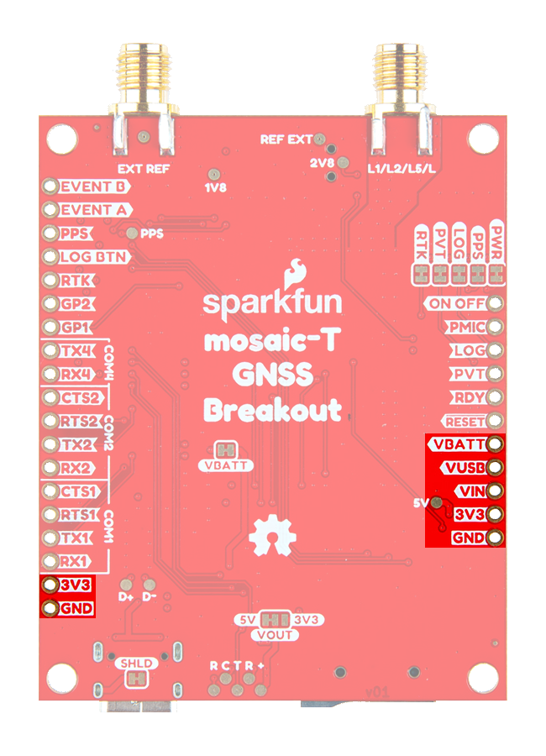
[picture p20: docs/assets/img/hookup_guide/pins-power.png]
Power supply I/O pins
	
	<figcaption markdown>The ppower supply pins on the mosaic-T Timing GNSS breakout board.</figcaption>
	</figure>

	</div>

	<div markdown>

	!!! info
		For more details, please refer to the [**Power** section](#power).

	- `VBATT` Pin
	:	Always-on power supply, which must remain available when 3V3 is disable, by the `PMIC` pin
	- `VUSB` Pin
	:	The voltage from the USB-C connector, usually 5V
	- `VIN` Pin
	:	Alternate input supply voltage for the board
	- `3V3` Pin
	:	Main power supply input, controlled by the external power switch
	- `GND` Pin
	:	The common ground or the 0V reference for the voltage supplies

	</div>

	</div>

### USB-C Connector
For most users, this will be the primary interface for the mosaic-T module.

<div class="grid" markdown>

<div markdown>

<figure markdown>
USB interface
<figcaption markdown>USB-C connector on the mosaic-T Timing GNSS breakout board.</figcaption>
</figure>

</div>

<div markdown>

1. When the board is initially connected to a computer, the module will initialize as a USB mass storage device.
	- For Windows PCs, the [USB driver](software_overview.md#usb-driver) can be installed from the mass storage device or the [RxTools software suite](software_overview.md#rxtools-software-suite).
	- When the SD card is mounted, this drive will contain the contents of the SD card that is inserted on the board.
1. Once the USB driver is installed:
	- Two virtual `COM` ports are emulated, which can be used as standard serial interfaces to access the receiver.
	- This interface will support Ethernet-over-USB.
		- By default, the receiver is not allowed to access the Internet over USB.
		- The IP address allocated to the Ethernet-over-USB interface is `192.168.3.1`.
			- The IP address cannot be changed; therefore, only single receiver should be connected to your computer at a time.

</div>

</div>

### SMA Connectors
There are two SMA connectors on the mosaic-T Timing GNSS breakout board.

<div class="grid" markdown>

<div markdown>

**`L1/L2/L5/L`**

---

The `L1/L2/L5/L` SMA connector provides an input for a compatible GNSS antenna. The type of antenna used with the mosaic-T module will affect the overall performance of the GNSS receiver.

<figure markdown>
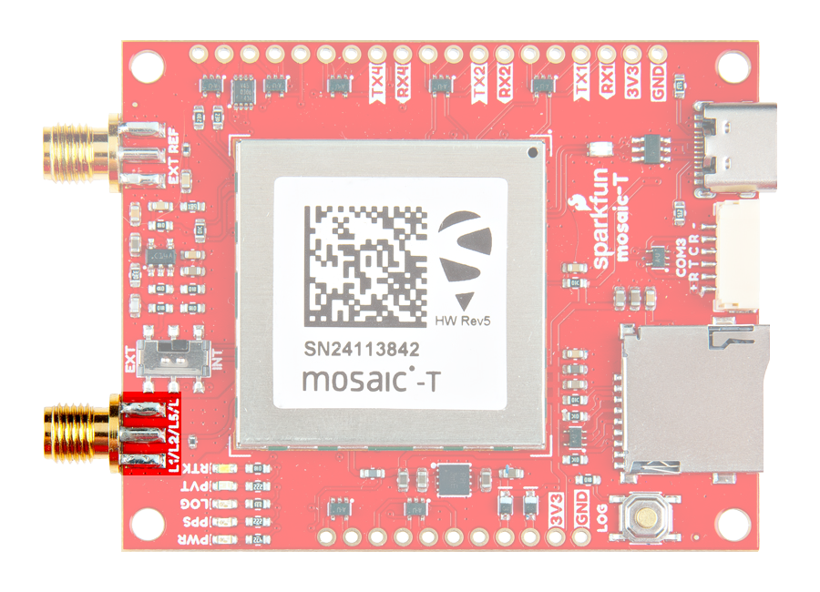
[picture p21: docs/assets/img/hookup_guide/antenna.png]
GNSS antenna input

<figcaption markdown>The SMA connector to attach a GNSS antenna to the mosaic-T Timing GNSS breakout board.</figcaption>
</figure>

There are some key parameters related to an antenna that can make or break the signal reception from the satellites. These include the operation frequency, gain, polarization, efficiency, and overall loss.

- An active antenna often features a [LNA](https://en.wikipedia.org/wiki/Low-noise_amplifier "low-noise amplifier"). This allows the module to boost the signal received by the GNSS module without degrading the [SNR](https://en.wikipedia.org/wiki/Signal-to-noise_ratio Signal-to-noise ratio).
	- The connector already provides active power at **3.3V**.

	!!! danger
		Never inject an external DC voltage into the SMA connector for the GNSS antenna, as it may damage the mosaic-T module. For instance, when using a splitter to distribute the antenna signal to several GNSS receivers, make sure that no more than one output of the splitter passes DC. Use [DC-blocks](https://en.wikipedia.org/wiki/DC_block) otherwise.

- The more frequency bands an antenna supports, often equates to a gain in the performance.
	- Faster acquisition time.
	- Access and support for the `L5` GPS band can potentially mitigate multi-path errors.
	- Less susceptible to jamming and spoofing.

!!! tip
	For the best performance, we recommend users choose a compatible L1/L2/L5/L-band GNSS antenna and utilize a low-loss cable. Also, don't forget that GNSS signals are fairly weak and can't penetrate buildings or dense vegetation. The GNSS antenna should have an unobstructed view of the sky.

</div>

<div markdown>

**`EXT REF`**

---

The primary feature of the mosaic-T is that it can be utilized to create a [GNSS disciplined oscillator](https://en.wikipedia.org/wiki/GPS_disciplined_oscillator) and calibrate an external reference clock to an accuracy of 20ns.

<figure markdown>
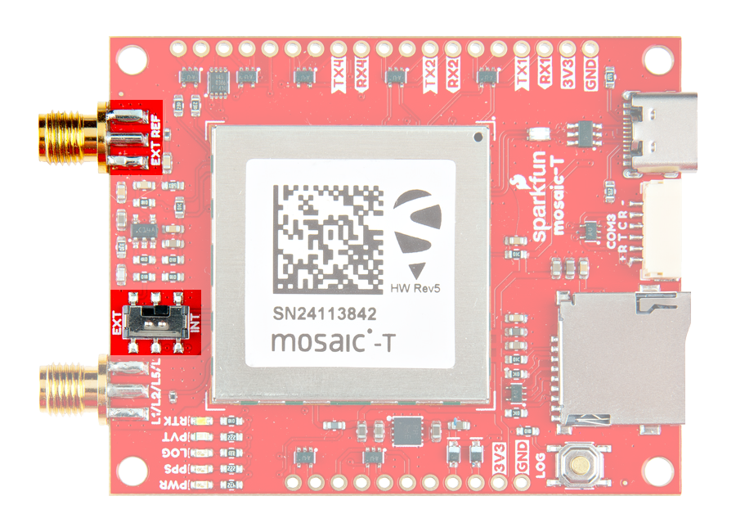
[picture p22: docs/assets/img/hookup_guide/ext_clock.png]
External reference clock input

<figcaption markdown>The JST connector on the mosaic-T Timing GNSS breakout board.</figcaption>
</figure>

- The `INT/EXT` slide switch selects a reference clock source from either:
	- The internal TCXO of the mosaic-T module
	- An external clock signal from the `EXT REF` SMA connector

	!!! warning
		If the reference clock switch is set to `EXT`, users must provide a 10MHz input signal. Otherwise, the mosaic-T module will cease to operate, without a clock signal. Additionally, switching between external and internal frequency reference must occur when the module is powered off, or the module must be reset after switching.

- The `EXT REF` SMA connector accepts a 50&ohm;, 10MHz signal with the following requirements:
	- Preferably a sine wave or a band-limited square wave
	- Power: -14dBm *(min)*; +14dBm *(max)*
	- Frequency tolerance: +/-2.5ppm
	- Allan variance: better than 1ppb (for &tau;=1s)
	- Phase noise: better than -90dBc/Hz at an offset of 10Hz

	!!! tip
		If a CMOS or LVTTL signal is used with long traces from the source, it is recommended to filter them at the source with an RC filter with a pole near 100 MHz.

</div>

</div>

### JST Connector
The mosaic-T Timing GNSS breakout board features a 6-pin [JST GH connector](./assets/component_documentation/JST-GH_datasheet.pdf), which is polarized and locking. Users can access the `COM3` port of the mosaic-T module through the JST connector with our [breadboard cable](https://www.sparkfun.com/breadboard-to-jst-ghr-06v-cable-6-pin-x-1-25mm-pitch.html).

<div class="grid" markdown>

<figure markdown>
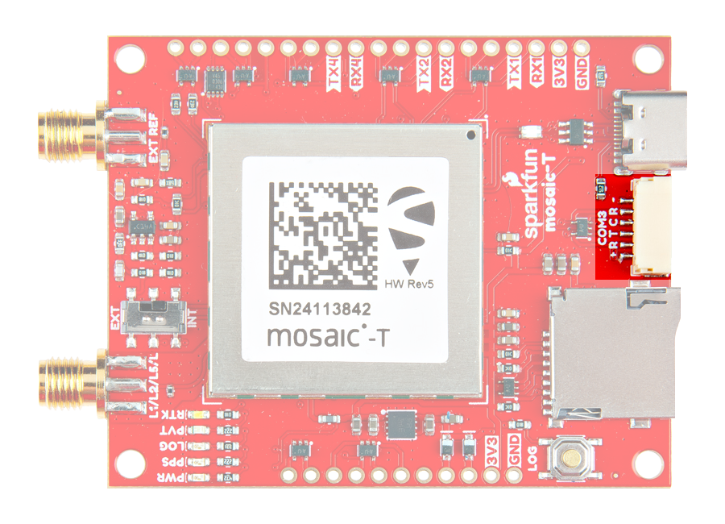
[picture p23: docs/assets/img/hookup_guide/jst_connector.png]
JST Connector

<figcaption markdown>The JST connector on the mosaic-T Timing GNSS breakout board.</figcaption>
</figure>

<figure markdown>
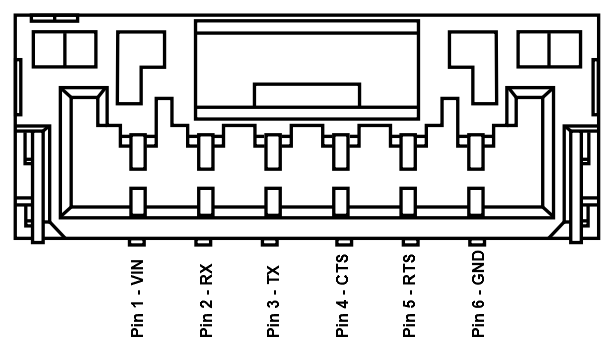
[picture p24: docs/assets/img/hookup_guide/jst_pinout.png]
JST pins

<figcaption markdown>The pin connections of the JST connector on the mosaic-T Timing GNSS breakout board.</figcaption>
</figure>

</div>

??? tip "Pin Connections"
	When connecting to the board's UART pins, the pins should be connected based upon the flow of their data. For example, when utilizing the [Telemetry Radio](https://www.sparkfun.com/sik-telemetry-radio-v3-915mhz-100mw.html) or the [LoRaSerial Kit](https://www.sparkfun.com/sparkfun-loraserial-kit-915mhz-enclosed.html):

	<figure markdown>
	Flow Control (https://docs.sparkfun.com/SparkFun_LoRaSerial/img/SAMD21%20Flow%20control.png "Click to enlarge")
	<figcaption markdown>Connection of the UART pins from the [LoRaSerial radio](https://www.sparkfun.com/sparkfun-loraserial-kit-915mhz-enclosed.html) to a host system, like the mosaic-T Timing GNSS breakout board.</figcaption>
	</figure>

!!! warning "`V` Pin"
	By default, the power pin *(i.e. `V` or Pin 1)* of the JST connector is connected to `VIN` and configured as a power input. The board can be modified to configure that pin as a power output; however, the modification would bypass some of the safety features of the board *(see the [**Power**](#power) section)*.

### SD Card Slot
The &micro;SD card slot allows users easily record and store data on the board.

<div class="grid" markdown>

<div markdown>

<figure markdown>
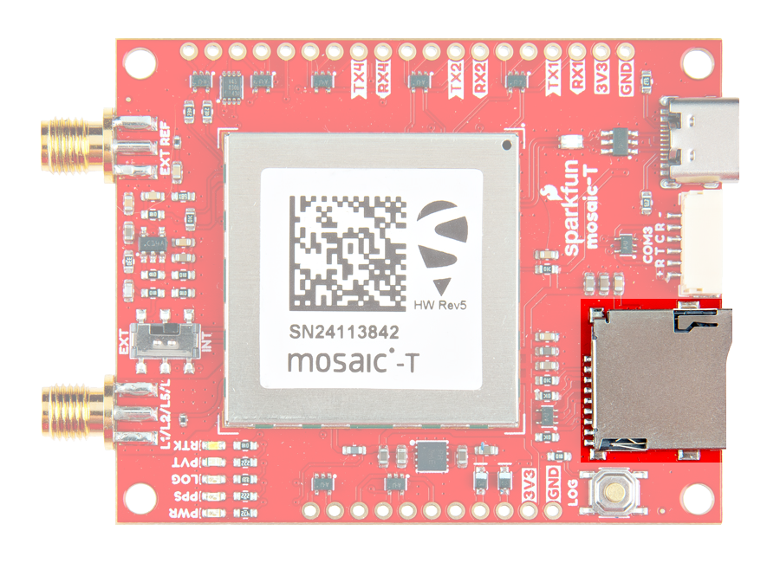
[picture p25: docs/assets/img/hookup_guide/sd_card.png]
SD card slot

<figcaption markdown>The &micro;SD card slot on the mosaic-T Timing GNSS breakout board.</figcaption>
</figure>

</div>

<div markdown>

!!! info "SD Card Specifications"
	The mosaic-T module is only compatible with SD cards of up to 32GB, formatted with a `FAT32` file system.

!!! success "Initial Configuration"
	Before data logging can occur, it is necessary to create a *logging stream* from the **Logging** tab of the web interface or using the **RxTools** software suite. Streams can contain NMEA or SBF (Septentrio Binary Format) data; SBF can contain RTCM and/or RINEX. *(see the [Data Logging](web_interface.md#data-logging) section)*

!!! warning "Standby Mode"
	When Standby mode is initialized, the module terminates all running processes and unmounts the external SD card to avoid any log file corruption *(see the **[Power Modes](#power-modes)** section)*.

</div>

</div>

!!! info "Operation"
	Data logging can be controlled on the board through either the [++"LOG"++ button](#log-button) or [`LOG BTN` pin](#data-logging).

	- Pressing the button or pin `LOW` *(< 5s)* toggles data logging to the SD card on and off.
	- Holding the button or pin `LOW` for more than 5 seconds *(> 5s)* and then releasing it, will force the board to:
		- Unmount the SD card if it was mounted
		- Mount the SD card if it was unmounted

	!!! question "Status"
		The status of the SD card and data stream are indicated on the `LOG` LED and pin.

		<article style="text-align: center;" markdown>

		| LED      | Pin    | Status                           |
		|:-------: | :----: | :------------------------------- |
		| Off      | Low    | SD card not present or unmounted |
		| On       | High   | SD card present and mounted      |
		| Blinking | Pulses | Data logging activity            |

		</article>

## Status LEDs
There are five status LEDs on the TMC6300 motor driver:

- `PWR` - Power *(Red)*
	- Turns on once power is supplied through the USB-C connector or `VIN` connections
- `PPS` - Pulse-Per-Second *(Yellow)*
	- Indicates when there is a pulse-per-second signal *(see the **[PPS Output](#pps-output)** section)*
- `LOG` - Data Logging *(Green)*
	- Indicates data logging activity *(see the **[SD Card Slot](#sd-card-slot)** section)*
		- Off - SD card not present or unmounted
		- On - SD card present and mounted
		- Blinking - Data logging activity
- `PVT` - Position/Velocity/Time Solution *(Blue)*
	- Turns on when a [PVT]("Position, Velocity, and Time") solution is available
- `RTK` - [RTK](https://en.wikipedia.org/wiki/Real-time_kinematic_positioning "Real-Time Kinematic") Mode *(White)*
	- Controlled through `GPIO 02`

<figure markdown>
Status LEDs
<figcaption markdown>The status indicator LEDs on the mosaic-T Timing GNSS breakout board.</figcaption>
</figure>

## Log Button
The ++"LOG"++ button allows users easily control the data logging feature and the &micro;SD card, once the data stream has been initially configured for the module.

<div class="grid" markdown>

<div markdown>

<figure markdown>
Buttons
<figcaption markdown>The `LOG` button on the mosaic-T Timing GNSS breakout board.</figcaption>
</figure>

Data logging can be controlled on the board through either the ++"LOG"++ button or [`LOG BTN` pin](#data-logging).

- Pressing the ++"LOG"++ button *(< 5s)* toggles data logging to the SD card on and off.
- Holding the ++"LOG"++ button for more than 5 seconds *(> 5s)* and then releasing it, will force the board to:
	- Unmount the SD card if it was mounted
	- Mount the SD card if it was unmounted

</div>

<div markdown>

!!! success "Initial Configuration"
	Before data logging can occur, it is necessary to create a *logging stream* from the **Logging** tab of the web interface or using the **RxTools** software suite. Streams can contain NMEA or SBF (Septentrio Binary Format) data; SBF can contain RTCM and/or RINEX. *(see the [Data Logging](web_interface.md#data-logging) section)*

!!! warning "Standby Mode"
	When Standby mode is initialized, the module terminates all running processes and unmounts the external SD card to avoid any log file corruption *(see the **[Power Modes](#power-modes)** section)*.

!!! question "Status"
	The status of the SD card and data stream are indicated on the `LOG` LED and pin.

	<article style="text-align: center;" markdown>

	| LED      | Pin    | Status                           |
	|:-------: | :----: | :------------------------------- |
	| Off      | Low    | SD card not present or unmounted |
	| On       | High   | SD card present and mounted      |
	| Blinking | Pulses | Data logging activity            |

	</article>

</div>

</div>

## Jumpers

??? note "Never modified a jumper before?"
	Check out our <a href="https://learn.sparkfun.com/tutorials/664">Jumper Pads and PCB Traces tutorial</a> for a quick introduction!

	<div class="grid cards" markdown align="center">

	-   <a href="https://learn.sparkfun.com/tutorials/664">
		<figure markdown>
		Tutorial thumbnail
		</figure>

		---
		
		**How to Work with Jumper Pads and PCB Traces**</a>

	</div>

There are eight jumpers on the back of the board that can be used to easily modify the hardware connections on the board.

<figure markdown>
Jumpers
<figcaption markdown>The jumpers on the back of the mosaic-T Timing GNSS breakout board.</figcaption>
</figure>

LED Jumpers
:   Five of the jumpers control power to the status LEDs on the board.

	!!! info
		By default, all the jumpers are connected, to power the status LEDs. For low power applications, users can cut the jumpers to disconnect power from each of the LEDs.

	- **`PWR_LED`** - This jumper can be cut to remove power from the red, power LED.
	- **`PPS_LED`** - This jumper can be cut to remove power from the yellow LED, which is connected to the [PPS](https://en.wikipedia.org/wiki/Pulse-per-second_signal "Pulse Per Second") signal.
	- **`LOG_LED`** - This jumper can be cut to remove power from the green LED, which indicates if data is being logged to the SD card.
	- **`GP_LED`** - This jumper can be cut to remove power from the blue LED that is connected to the general purpose pins.
	- **`RTK_LED`** - This jumper can be cut to remove power from the white LED.

**`VBATT`**
:   This jumper can be cut to disconnect the `VBATT` pin from the 3.3V output of the AP7361C LDO regulator.

	!!! info
		The `VBATT` pin is the always-on power input for the mosaic-T module, which is necessary for the module to enter **Standby** mode.

		- By default, the `VBATT` pin connected to the 3.3V output of the AP7361C LDO regulator. Therefore, the mosaic-T module will shutdown, if power is disconnected from the `VUSB` and `VIN` inputs.
		- If cut, an external power source must be connected to the `VBATT` pin to keep the module powerd in **Standby** mode.

**`VOUT`**
:   This jumper can be modified to change the output voltage on the [JST connector](#jst-connector) to **3.3V**.

	!!! info
		By default, the jumper is configured to provide a **5V** output when available from the [`VUSB` or `VIN` power sources](#power).

**`SHLD`**
:   This jumper can be cut to disconnect the shield of the USB-C connector from the board's ground plane.

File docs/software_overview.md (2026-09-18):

!!! note
	The mosaic-T module has numerous capabilities and a multitude of ways to configure and interface with them. Without regurgitating all the information that is documented in Septentrio's user manuals and videos, we have tried to highlight a good majority of the module's aspects.

	With that said, please feel free to [file an issue](github/file_issue.md#discrepancies-in-the-documentation) if you feel we have missed something that may benefit other users. *(Don't forget to provide us with a link to the documentation and what section the information is located.)*

## RxTools Software Suite

!!! tip
	Even if you aren't necessarily interested it, we highly recommend that users install the [RXTools software suite](https://www.septentrio.com/en/products/gps-gnss-receiver-software/rxtools) before plugging in their board. For Windows PCs, it also includes the USB driver for the module that enables the Ethernet-over-USB support and virtual `COM` ports.

Users should install the [RXTools software suite](https://www.septentrio.com/en/products/gps-gnss-receiver-software/rxtools) on their computer to interact with the mosaic-T module through the USB interface. The software package includes the USB-IP driver[^1] necessary to recognize the board as an ethernet device on Windows PCs (1).
{ .annotate }

1. On Linux, the standard Linux CDC-ACM driver is suitable.

[^1]: On Linux, the standard Linux CDC-ACM driver is suitable.

<article style="text-align: center;" markdown>
[:octicons-download-16:{ .heart } Download the RxTools Software from Septentrio](https://www.septentrio.com/en/products/gps-gnss-receiver-software/rxtools){ .md-button .md-button--primary target="blank" }
</article>

??? info "System Requirements[^2]"

	=== "Operating Systems"
	
		- Windows 7
		- Windows 8
		- Windows 10
		- Fedora 23 *(or later)* using Qt technology.
			- The standalone tools (except `bin2asc`) will run on older distributions.

	=== "Hardware Requirements"
		The minimal hardware requirements *(1Hz update[^3])*:
	
		- CPU: 1 GHz processor
		- RAM: 1 GB RAM
		- Screen Resolution: 1024×768 or higher resolution

	[^2]: The system requirements and installation instructions are from the RxTools *v22.1.0* user manual. This information may change in later iterations of the software suite. Please refer to the user manual *(of the version you are utilizing)* for the most accurate information.
	[^3]: Higher data rates will require higher CPU speed and more memory capacity.

??? info "Installation Instructions[^2]"

	=== "Windows"
		Users can install RxTools software suite by running the installation executable[^4](1), located in the `RxTools\windows` directory of the downloaded `*.zip` file[^5]. During the installation process, users will be notified if a previous version of RxTools is already installed then that the previous version will be uninstalled. Next, users will need to provide an installation directory for the RxTools software suite. Users will then select which of the following applications[^6] are installed:
		{ .annotate }

		1. For RxTools v22.1.0, the installation filename is `RxTools_22_1_0_Installer.exe` for Windows PCs.

		<!-- Create Break from Annotation (list won't render without comment)-->

		<div class="grid" markdown>

		<div markdown>

		- RxControl
		- SBF Converter
		- SBF Analyzer
		- RxLogger

		</div>

		<div markdown>

		- RxUpgrade
		- RxDownload
		- RxPlanner

		</div>

		<div markdown>

		- Data Link
		- RxAssistant
		- RxLauncher

		</div>

		</div>

	=== "Linux[^1]"
		!!! warning
			It is recommended that users **<span style="color:red">NOT</span>** install RxControl as `root`, for security reasons and to avoid installation overwrites of other system settings. To make RxTools available to more than one user, provide a shared installation directory.

		Users can install RxTools software suite by running the installation binary[^4](1), located in the `RxTools/linux-i386/` directory of the downloaded `*.zip` file[^5]. During the installation, users will be prompted for an installation directory. If there are any previous installations of RxControl, please use a different directory to avoid conflicts.
		{ .annotate }

		1. For RxTools v22.1.0, the installation filename is `RxTools_22_1_0_Installer.bin` for Linux.

		??? info "Permission Settings"
			Once installed, users may need to reconfigure their permission settings:

			<div class="annotate" markdown>

			- RxTools will need rights to access the `/dev/ttyS*` serial ports.

				- To access the serial ports, users must be part of the `uucp` and `lock` groups (1). This can be configured by editing the `/etc/group`[^7] file and adding the username to the lines defining the `uucp` group and the `lock` group.

					For example, when adding the user `jsmith` to the `uucp` group, users would modify the `/etc/group` file as shown below:

					```bash
					{--uucp:x:14:uucp--} # (2)!
					{++uucp:x:14:uucp,jsmith++} # (3)!
					```

				- On Linux machine administered centrally on a local network, ask your system administrator to be included in the `uucp` and `lock` groups.
			- RxTools also needs read/write (`rw`) access(4) to the `/dev/ttyS*` serial ports.

				- Users can change the permissions with the `chmod`[^8] command:

					```bash
					chmod 660 /dev/ttyS<add port> # (5)!>
					```

			</div>

			1. On most Linux operating systems, the `/dev/ttyS*` devices are owned by `root` and belong to the `uucp` group with read/write (`rw`) access. Additionally, the devices are normally locked by writing a file in the `/var/lock/` directory, with the same permissions.
			1. Remove
			1. Replace with this line
			1. By default, users will normally have read/write (`rw`) access to the `/dev/ttyS*` serial ports.
			1. where users must specify the port number<br>*e.g. `/dev/ttyS0` might be port `COM1`*

			!!! note
				In order for these changes to take effect, users must update their environment by logging out and back in.

				Be aware that the X-session has to be restarted as well. On most systems, this can be done by pressing the key combination ++ctrl++ + ++alt++ + ++backspace++

		??? info "64-bit OS"
			In order to run the RxTools on a 64-bit Linux operating system, users might to install the 32-bit version of the `C` standard library.

			- For Fedora installations, this is the `glibc.i686` package.
			- The equivalent for Debian(/Ubuntu) installations is the `ia32-libs` package.

	[^4]: Users will need administrative privileges to install the RxTools software.
	[^5]: Users may need to extract the RxTools installation files from the downloaded, compressed file.
	[^6]: Please see the release notes for the issues and limitations of the RxTools applications.
	[^7]: Requires c privileges.
	[^8]: Changing these permissions also requires `root` privileges.

## USB Driver

=== "Windows"
	If users haven't already installed the [RxTools software suite](https://www.septentrio.com/en/products/gps-gnss-receiver-software/rxtools) on their Windows PC, they will need to install the USB driver[^1] necessary to recognize and interact with the mosaic-T module through the USB interface.

	A Windows USB driver for the mosaic-T can be installed through two methods:

	<div class="annotate" markdown>

	- RxTools Software Suite (1)
	- mosaic-T GNSS Receiver Module (2)

	</div>

	1. The driver is installed during the installation process.
	1. The installation file for the Windows USB driver will be available from the mass-storage device when the board is initially connected to the computer.

	Once installed, the driver emulates two virtual serial ports, which can be accessed as standard `COM` ports to the receiver.

	??? tip "Terminal Emulators"
		Most [terminal emulation programs](https://learn.sparkfun.com/tutorials/112) will not make a distinction between virtual or native COM ports. However, for virtual serial ports, the port settings *(i.e. baudrate, etc.)* are not relevant and the default configuration be used in the terminal emulation program. However, for the physical/native `COM` ports will have the following default setting:

		- Baudrate: 115200bps
		- Data Bits: 8
		- Parity: No
		- Stop Bits: 1
		- Flow Control: None

	??? tip "Having Trouble?"
		For users who are having trouble installing the USB driver, we have an archived version *(v3.0.2[^9])* of the installation file. Users can download [**version 3.0.2**](./assets/component_documentation/driver/USB_driver_3_0_2_Installer.exe) of the driver, by clicking on the button below.

		[^9]:
			For the latest USB driver from Septentrio, please install their driver through the [RxTools software suite](rxtools.md).<br>
			*This is driver version, was archived at the time that this guide was written. Please do not request for the file to be updated.*

		<article style="text-align: center;" markdown>
		[:octicons-download-16:{ .heart } Download USB Driver *(v3.0.2)*](./assets/component_documentation/driver/USB_driver_3_0_2_Installer.exe){ .md-button .md-button--primary target="blank" }
		</article>

=== "Linux"
	On Linux, the standard Linux CDC-ACM driver is suitable.

## Web Interface
With the USB driver installed, the mosaic-T module supports Ethernet-over-USB. The default IP address allocated for the Ethernet-over-USB interface is `192.168.3.1`. This IP can be entered in any browser to open a connection to the receiver's Web Interface as shown below.

<div class="grid" markdown>

<div markdown>

<figure markdown>
navigation tabs in the web interface
<figcaption markdown>All the drop-down navigation tabs in the web interface.</figcaption>
</figure>

</div>

<div markdown>

<article class="video-500px" style="text-align: center; margin: auto;" markdown>
<iframe src="https://www.youtube.com/embed/hrL5J6Q5gX8" title="Septentrio: Getting started with the Septentrio mosaic receiver module" frameborder="0" allow="accelerometer; autoplay; clipboard-write; encrypted-media; gyroscope; picture-in-picture" allowfullscreen></iframe>
QR code to play video
</article>

</div>

</div>

!!! info
	The default IP address cannot be changed; this feature is only to be used when a single receiver is connected to your computer.

??? failure "Invalid IP Address *(WiFi Only)*"
	[One of the documentation pages on Septentrio's website](https://customersupport.septentrio.com/s/article/What-is-the-default-IP-address-to-connect-via-WiFi), specifies a default IP address of `192.168.20.1` for the web interface. However, that address is for a WiFi enabled product and cannot be used with this product.

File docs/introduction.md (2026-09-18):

<figure markdown>
Hookup Guide - Thumbnail
</figure>

---

# Introduction

<div class="grid cards desc" markdown>

-   <a href="https://www.sparkfun.com/sparkfun-timing-gnss-breakout-mosaic-t.html">
	**GNSS Timing Breakout - mosaic-T**<br>
	**SKU:** GPS-28731

	---

	<figure markdown>
	Product Thumbnail
	</figure></a>

	<article style="text-align: center;" markdown>
	QR code to product page[Purchase from SparkFun :fontawesome-solid-cart-plus:{ .heart }](https://www.sparkfun.com/sparkfun-timing-gnss-breakout-mosaic-t.html){ .md-button .md-button--primary }
	</article>

-   At the heart of our Timing GNSS Breakout is [Septentrio](https://www.septentrio.com/en)'s mosaic-T, a compact, ultra-low power, multi-band, multi-constellation, high-precision GNSS timing receiver. It can acheive a timing precision of 5ns (5 billionths of a second), or better than 1ns with an optional subscription to the Fugro AtomiChron® L-band timing service. Event accuracy is better than 20ns. It also features Septentrio's unique [AIM+ technology](https://www.septentrio.com/en/learn-more/advanced-positioning-technology/aim-jamming-protection) for interference mitigation and anti-spoofing, ensuring best-in-class reliability and accuracy.

	This board provides easy access to the mosaic-T's reference clock to create your own [GNSS disciplined oscillator](https://en.wikipedia.org/wiki/GPS_disciplined_oscillator). You can use the computed `RxClkBias` from the `PVTCartesian` or `PVTGeodetic` SBF blocks of the mosaic-T to discipline your own 10MHz oscillator. The **EXT REF** SMA connector accepts **50&ohm;**, **10MHz** signals within a range of **-14dBm** *(min)* to **+14dBm** *(max)*. The `INT`/`EXT` slide switch selects the internal or external oscillator.

	The mosaic-T is a sophisticated timing receiver running an internal web server that can be accessed through the USB interface with a standard browser using a Linux/Windows computer. Septentrio also provides dozens of [video tutorials](https://www.youtube.com/@SeptentrioGNSS/videos) to guide users through the configuration settings of their GNSS receivers utilizing the web interface.

	Beyond the capabilities of the mosaic-T module, this board is seamless to operate with no programming skills required. Gone are the times when a microcontroller was required to interface with the GNSS receiver and log data to an SD card and when users had to carry around an SD card reader to extract the data from the SD card. The Timing GNSS Breakout - mosaic-T  can start/stop logging data or mount/unmount the SD card, without a single line of code, just utilizing a simple button. For the users who prefer a command-line interface, Septentrio has you covered. Users can still control and configure the mosaic-T module through a CLI, which is useful for scenarios such as production line testing *(in fact, that is how we tested this board)*.

	This breakout board is a perfect middle ground for users who would like to integrate the mosaic-T module into a project/enclosure with access to a majority of the module's available pins, similar to Septentrio's developer kit, but in the smaller form factor of their evaluation kit. Or maybe... you just needed a very accurate PPS output at a 3.3V logic level. *Please, check out the rest of our [hookup guide](hardware_overview.md) for more details on the capabilities of this board (that we couldn't fit in this product description).*

	!!! warning "RTK Not Supported"
		The mosaic-T is a superb GNSS module designed for highly accurate timing applications. **But it does not support RTK. It can not be configured as a RTK Rover or Base. RTCM output is not supported.**

</div>

!!! danger "Important: Read Before Use!"
	!!! warning "ESD Sensitivity"
		The mosaic-T module is sensitive to [ESD](https://en.wikipedia.org/wiki/Electrostatic_discharge "Electrostatic Discharge"). Use a proper grounding system to make sure that the working surface and the components are at the same electric potential.

		??? info "ESD Precautions"
			As recommended by the manufacturer, we highly recommend that users take the necessary ESD precautions to avoid damaging their module.

			<div class="grid cards" markdown>

			<div markdown>

			<article class="video-500px" style="text-align: center; margin: auto;" markdown>
			<iframe src="https://www.youtube.com/embed/hrL5J6Q5gX8?si=jOPBat8rzMnL7Uz4&amp;start=26;&amp;end=35;" title="Septentrio: Getting Started Video (playback starts at ESD warning)" frameborder="0" allow="accelerometer; autoplay; clipboard-write; encrypted-media; gyroscope; picture-in-picture" allowfullscreen></iframe>
			QR code to play video
			</article>

			</div>

			-   <a href="https://www.sparkfun.com/ifixit-anti-static-wrist-strap.html">
				<figure markdown>
				Product Thumbnail
				</figure>

				---

				**iFixit Anti-Static Wrist Strap**<br>
				TOL-25572</a>

			</div>

	!!! warning "Active Antenna"
		Never inject an external DC voltage into the SMA connector for the GNSS antenna, as it may damage the mosaic-T module. For instance, when using a splitter to distribute the antenna signal to several GNSS receivers, make sure that no more than one output of the splitter passes DC. Use [DC-blocks](https://en.wikipedia.org/wiki/DC_block) otherwise.

??? question "Product Comparison"
	Below is a simple comparison table between our breakout board and Septentrio's development and evaluation kits:

	<div class="annotate" markdown align="center">
	<table markdown>
	<tr markdown>
	<td></td>
	<th markdown style="text-align:center">
		mosaic-T Development Kit<br>
		<hr>
		<figure markdown>
		Product Thumbnail
		</figure>
	</th>
	<th markdown style="text-align:center">
		mosaic-T GNSS Breakout<br>
		<hr>
		<figure markdown>
		Product Thumbnail
		</figure>
	</th>
	<th markdown style="text-align:center">
		GNSS Disciplined Oscillator<br>
		<hr>
		<figure markdown>
		Product Thumbnail
		</figure>
	</th>
	</tr>
	<tr>
		<td style="vertical-align:middle;">GNSS Antenna</td>
		<td style="text-align:center; vertical-align:middle;">Dual</td>
		<td style="text-align:center; vertical-align:middle;">Single</td>
		<td style="text-align:center; vertical-align:middle;">Single</td>
	</tr>
	<tr>
		<td>USB Connector</td>
		<td style="text-align:center">micro-B</td>
		<td style="text-align:center">Type-C</td>
		<td style="text-align:center">Type-C</td>
	</tr>
	<tr>
		<td style="vertical-align:middle;">Ethernet</td>
		<td style="text-align:center; vertical-align:middle;">
			Yes<br>
			<i>10/100 Base-T</i>
		</td>
		<td style="text-align:center; vertical-align:middle;">No</td>
		<td style="text-align:center">
			Yes<br>
			<i>10/100 Base-T</i>
		</td>
	</tr>
	<tr>
		<td style="vertical-align:middle;">WiFi</td>
		<td style="text-align:center; vertical-align:middle;">No</td>
		<td style="text-align:center; vertical-align:middle;">No</td>
		<td style="text-align:center">
			Yes - Network Bridge<br>
			<i>10 Base-T</i>
		</td>
	</tr>
	<tr>
		<td style="vertical-align:middle;">COM Ports</td>
		<td style="text-align:center">4</td>
		<td style="text-align:center">4</td>
		<td style="text-align:center">
			1 - mosaic-T<br>
			1 - ESP32
		</td>
	</tr>
	<tr>
		<td>&micro;SD Card Slot</td>
		<td style="text-align:center">Yes</td>
		<td style="text-align:center">Yes</td>
		<td style="text-align:center">Yes</td>
	</tr>
	<tr>
		<td style="vertical-align:middle;">Reset/Log Buttons</td>
		<td style="text-align:center; vertical-align:middle;">Yes</td>
		<td style="text-align:center; vertical-align:middle;">Yes</td>
		<td style="text-align:center; vertical-align:middle;">Yes</td>
	</tr>
	<tr>
		<td style="vertical-align:middle;">Logic-Level</td>
		<td style="text-align:center">
			1.8V<br>
			3.3V
		</td>
		<td style="text-align:center; vertical-align:middle;">3.3V</td>
		<td style="text-align:center">
			3.3V<br>
			5V
		</td>
	</tr>
	<tr>
		<td>PPS Signal</td>
		<td style="text-align:center">Header Pin</td>
		<td style="text-align:center">PTH Pad</td>
		<td style="text-align:center">SMA Connector</td>
	</tr>
	<tr>
		<td>External Ref. Signal</td>
		<td style="text-align:center">SMA Connector</td>
		<td style="text-align:center">SMA Connector</td>
		<td style="text-align:center">SMA Connector</td>
	</tr>
	<tr>
		<td>Enclosure Material</td>
		<td style="text-align:center; vertical-align:middle;">N/A</td>
		<td style="text-align:center; vertical-align:middle;">N/A</td>
		<td style="text-align:center; vertical-align:middle;">Aluminum</td>
	</tr>
	<tr>
		<td style="vertical-align:middle;">Dimensions</td>
		<td style="text-align:center; vertical-align:middle;">N/A</td>
		<td style="text-align:center; vertical-align:middle;">63.5 x 50.8 x 0.8cm</td>
		<td style="text-align:center">
			180.6 x 101.8 x 4.1cm<br>
			<i>Enclosure Only</i>
		</td>
	</tr>
	<tr>
		<td style="vertical-align:middle;">Weight</td>
		<td style="text-align:center; vertical-align:middle;">N/A</td>
		<td style="text-align:center; vertical-align:middle;">23g</td>
		<td style="text-align:center">
			415g<br>
			<i>Enclosure Only</i>
		</td>
	</tr>
	
	</table>
	
	</div>

---

In this guide we'll cover how to setup the mosaic-T Timing GNSS breakout board. Additionally, we also provide some guidelines for creating a [GNSS disciplined oscillator](https://en.wikipedia.org/wiki/GPS_disciplined_oscillator), based upon our work with the [SparkPNT GNSSDO](https://www.sparkpnt.com/products/sxt-gnssdo). To follow along with this tutorial, at a minimum, users will need the following items:

<div class="annotate" markdown>

- Computer with an operating system (OS) that is compatible with all the software installation requirements (1)

	!!! warning "Software Compatibility"
		The [RxTools software suite](https://www.septentrio.com/en/products/gps-gnss-receiver-software/rxtools) from Septentrio, automatically installs the required USB-over-Ethernet driver and provides users with an interface for the receiver configuration, monitoring, data logging, and analysis. However, it only appears to be available for Windows and Linux operating systems.

- [USB 3.1 Cable A to C - 3 Foot](https://www.sparkfun.com/usb-3-1-cable-a-to-c-3-foot.html) - Used to interface with the mosaic-T GNSS Breakout (2)
- [SparkFun GNSS Timing Breakout - mosaic-T](https://www.sparkfun.com/sparkfun-timing-gnss-breakout-mosaic-t.html) (3)
- [GNSS Multi-Band L1/L2/L5 Surveying Antenna](https://www.sparkfun.com/gnss-multi-band-l1-l2-l5-surveying-antenna-tnc-spk6618h.html)
	- [SMA Male to TNC Male Cable](https://www.sparkfun.com/reinforced-interface-cable-sma-male-to-tnc-male-10m.html)
	- [Antenna Mount](https://www.sparkfun.com/gnss-magnetic-antenna-mount-5-8-11-tpi.html)

</div>

1. A list of the compatible GNSS receiver software, is provided on the [Septentrio website](https://www.septentrio.com/en/products/gps-gnss-receiver-software).
1. If your computer doesn't have a USB-A slot, then choose an appropriate cable or adapter.
1. For the best performance, use a compatible L1/L2/L5/L-Band GNSS antenna.

<div class="grid cards" markdown>

-   <a href="https://www.sparkfun.com/usb-3-1-cable-a-to-c-3-foot.html">
	<figure markdown>
	USB 3.1 Cable A to C - 3 Foot
	</figure>

	---

	**USB 3.1 Cable A to C - 3 Foot**<br>
	CAB-14743</a>

-   <a href="https://www.sparkfun.com/sparkfun-timing-gnss-breakout-mosaic-t.html">
	<figure markdown>
	Product Thumbnail
	</figure>

	---

	**GNSS Timing Breakout - mosaic-T**<br>
	GPS-28731</a>

-   <a href="https://www.sparkfun.com/gnss-multi-band-l1-l2-l5-surveying-antenna-tnc-spk6618h.html">
	<figure markdown>
	Product Thumbnail
	</figure>

	---

	**GNSS Multi-Band L1/L2/L5 Surveying Antenna - TNC (SPK6618H)**<br>
	GPS-21801</a>

-   <a href="https://www.sparkfun.com/reinforced-interface-cable-sma-male-to-tnc-male-10m.html">
	<figure markdown>
	Product Thumbnail
	</figure>

	---

	**Reinforced Interface Cable - SMA Male to TNC Male (10m)**<br>
	CAB-21740</a>

-   <a href="https://www.sparkfun.com/gnss-magnetic-antenna-mount-5-8-11-tpi.html">
	<figure markdown>
	Product Thumbnail
	</figure>

	---

	**GNSS Magnetic Antenna Mount - 5/8" 11-TPI**<br>
	PRT-21257</a>

-   <a href="https://www.sparkfun.com/ifixit-anti-static-wrist-strap.html">
	<figure markdown>
	Product Thumbnail
	</figure>

	---

	**iFixit Anti-Static Wrist Strap**<br>
	TOL-25572</a>

	??? warning "ESD Protection"
		The Septentrio mosaic-T module is sensitive to [ESD](https://en.wikipedia.org/wiki/Electrostatic_discharge "Electrostatic Discharge"). As recommended by the manufacturer, we highly recommend that users take the necessary precautions to avoid damaging their module. Use a proper grounding system to make sure that the working surface and the components are at the same electric potential.

</div>

## Section Topics
This guide is divided into three sections:

- The **Hardware** section has two sub-sections that provide:
	- An overview of the board's design, major components, and interfaces. Refer to this page for information on the connectors, breakout pins, and jumpers.
	- Assembly instructions for this product's interfaces.
- The **Software** section has several sub-sections. The mosaic-T module has numerous capabilities and a multitude of ways to configure and interface with them. Without regurgitating all the information that is documented in Septentrio's user manuals and videos, we have tried to highlight a good majority of the module's aspects.
- In the **Resources** and **Support** sections, users can find the design files (KiCad files & schematic), relevant documentation (datasheets, white papers, etc.) and other helpful links on the Resources page. Lastly, the **Troubleshooting Tips** page includes helpful tips and instructions for how to receive technical support from SparkFun.

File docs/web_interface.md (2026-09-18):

---
icon: material/web
---

!!! note
	The mosaic-T module has numerous capabilities and a multitude of ways to configure and interface with them. Without regurgitating all the information that is documented in Septentrio's user manuals and videos, we have tried to highlight a good majority of the module's aspects.

	With that said, please feel free to [file an issue](github/file_issue.md#discrepancies-in-the-documentation) if you feel we have missed something that may benefit other users. *(Don't forget to provide us with a link to the documentation and what section the information is located.)*

## USB Driver
=== "Windows"
	If users haven't already installed the [RxTools software suite](https://www.septentrio.com/en/products/gps-gnss-receiver-software/rxtools) on their Windows PC, they will need to install the USB driver[^1] necessary to recognize and interact with the mosaic-T module through the USB interface.

	[^1]: On Linux, the standard Linux CDC-ACM driver is suitable.

	A Windows USB driver for the mosaic-T can be installed through two methods:

	<div class="annotate" markdown>

	- RxTools Software Suite (1)
	- mosaic-T GNSS Receiver Module (2)

	</div>

	1. The driver is installed during the installation process.
	1. The installation file for the Windows USB driver will be available from the mass-storage device when the board is initially connected to the computer.

	Once installed, the driver emulates two virtual serial ports, which can be accessed as standard `COM` ports to the receiver.

	??? tip "Terminal Emulators"
		Most [terminal emulation programs](https://learn.sparkfun.com/tutorials/112) will not make a distinction between virtual or native COM ports. However, for virtual serial ports, the port settings *(i.e. baudrate, etc.)* are not relevant and the default configuration be used in the terminal emulation program. However, for the physical/native `COM` ports will have the following default setting:

		- Baudrate: 115200bps
		- Data Bits: 8
		- Parity: No
		- Stop Bits: 1
		- Flow Control: None

	??? tip "Having Trouble?"
		For users who are having trouble installing the USB driver, we have an archived version *(v3.0.2[^2])* of the installation file. Users can download [**version 3.0.2**](./assets/component_documentation/driver/USB_driver_3_0_2_Installer.exe) of the driver, by clicking on the button below.

		[^2]:
			For the latest USB driver from Septentrio, please install their driver through the [RxTools software suite](rxtools.md).<br>
			*This is driver version, was archived at the time that this guide was written. Please do not request for the file to be updated.*

		<article style="text-align: center;" markdown>
		[:octicons-download-16:{ .heart } Download USB Driver *(v3.0.2)*](./assets/component_documentation/driver/USB_driver_3_0_2_Installer.exe){ .md-button .md-button--primary target="blank" }
		</article>

=== "Linux"
	On Linux, the standard Linux CDC-ACM driver is suitable.

## Web Interface
With the USB driver installed, the mosaic-T module supports Ethernet-over-USB. The default IP address allocated for the Ethernet-over-USB interface is `192.168.3.1`. This IP can be entered in any browser to open a connection to the receiver's Web Interface as shown below.

<div class="grid" markdown>

<div markdown>

<figure markdown>
navigation tabs in the web interface
<figcaption markdown>All the drop-down navigation tabs in the web interface.</figcaption>
</figure>

</div>

<div markdown>

<article class="video-500px" style="text-align: center; margin: auto;" markdown>
<iframe src="https://www.youtube.com/embed/hrL5J6Q5gX8" title="Septentrio: Getting started with the Septentrio mosaic receiver module" frameborder="0" allow="accelerometer; autoplay; clipboard-write; encrypted-media; gyroscope; picture-in-picture" allowfullscreen></iframe>
</article>

</div>

</div>

!!! info
	The default IP address cannot be changed; this feature is only to be used when a single receiver is connected to your computer.

??? failure "Invalid IP Address *(WiFi Only)*"
	[One of the documentation pages on Septentrio's website](https://customersupport.septentrio.com/s/article/What-is-the-default-IP-address-to-connect-via-WiFi), specifies a default IP address of `192.168.20.1` for the web interface. However, that address is for a WiFi enabled product and cannot be used with this product.

### Update the Module's Firmware

!!! info "Latest Firmware"
	For the latest firmware released by Septentrio, please visit their [product page](https://www.septentrio.com/en/products/gps/gnss-receiver-modules/mosaic-T#resources) for the mosaic-T module.

<div class="grid cards" markdown>

-   To check for the latest firmware published by Septentrio, please visit their [product page](https://www.septentrio.com/en/products/gps/gnss-receiver-modules/mosaic-T#resources) for the mosaic-T module. Users can click on the button below, to be redirected to the latest firmware for the mosaic-T.

	<article style="text-align: center;" markdown>
	[Find the Latest Firmware](https://www.septentrio.com/en/products/gps/gnss-receiver-modules/mosaic-T#resources){ .md-button .md-button--primary target="blank" }
	</article>

-   Currently, at the time that this board was released, the firmware for the mosaic-T module was *v4.15.0*[^4]. Users can download [**version 4.15.0**](./assets/component_documentation/firmware/mosaic-T_fwp_4.15.0.zip) of the firmware, by clicking on the button below.

	[^4]:
		For the latest firmware published by Septentrio, please visit their [product page](https://www.septentrio.com/en/products/gps/gnss-receiver-modules/mosaic-T#resources).<br>
		*This is firmware version, was archived at the time that this guide was written. Please do not request for the file to be updated; instead visit the product page to download the latest firmware.*

	<article style="text-align: center;" markdown>
	[:octicons-download-16:{ .heart } Download Firmware *(v4.15.0)*](./assets/component_documentation/firmware/mosaic-T_fwp_4.15.0.zip){ .md-button .md-button--primary target="blank" }
	</article>

</div>

<div class="grid" markdown>

<div markdown>

<article class="video-500px" style="text-align: center; margin: auto;" markdown>
<iframe src="https://www.youtube.com/embed/bp8kNbzMl_c" title="Septentrio: How to upgrade the firmware of a Septentrio receiver" frameborder="0" allow="accelerometer; autoplay; clipboard-write; encrypted-media; gyroscope; picture-in-picture" allowfullscreen></iframe>
</article>

</div>

</div>

### GNSS Data
Besides logging data with just the ++"LOG"++ button, users can configure/enable the output of data streams through the `COM` ports and data logging to the SD card through the web interface or RxTools software suite. The videos below illustrate how these features can be operated through the web interface.

<div class="grid" markdown>

<div markdown>

#### Data Logging

This video illustrates how users can configure the settings for data logging to the SD card.

<article class="video-500px" style="text-align: center; margin: auto;" markdown>
<iframe src="https://www.youtube.com/embed/Y9tvOebnoxk" title="Septentrio: How to log data to the SD card of the Septentrio mosaic receiver module" frameborder="0" allow="accelerometer; autoplay; clipboard-write; encrypted-media; gyroscope; picture-in-picture" allowfullscreen></iframe>
</article>

</div>

<div markdown>

#### Stream Data

This video illustrates how users can configure and enable a data stream through a TCP/IP connection.

<article class="video-500px" style="text-align: center; margin: auto;" markdown>
<iframe src="https://www.youtube.com/embed/ArtePkC58-o" title="Septentrio: How to output NMEA data on the Septentrio mosaic receiver module" frameborder="0" allow="accelerometer; autoplay; clipboard-write; encrypted-media; gyroscope; picture-in-picture" allowfullscreen></iframe>
</article>

</div>

</div>

??? info "Related Video"
	While this instructional video is for a different product line, the information, for the most part, is still relevant.

	<article class="video-500px" style="text-align: center; margin: auto;" markdown>
	<iframe src="https://www.youtube.com/embed/vU6iwJ-ac6A" title="Septentrio: How to log and stream data in NMEA OR SBF format for GNSS/INS receivers" frameborder="0" allow="accelerometer; autoplay; clipboard-write; encrypted-media; gyroscope; picture-in-picture" allowfullscreen></iframe>
	</article>

#### Sharing Internet Access
By default, the mosaic-T GNSS receiver is not configured to access the internet through the USB interface. Users will need to enable this capability as needed.

- Users will need to use the web interface or RxTool software suite to enable the `Outgoing Internet Access Over USB` from the **Communication** > **USB** drop-down menu of the navigation tabs.
- This also requires users to allow Internet sharing through their computer as well. The procedure to do so depends on your operating system.
	- On a Windows PC, users must enable `Allow other network users to connect through this computer's Internet connection`, through the properties option of the network adapter with internet access.
	- On a Linux computer, users will likely need to configure a [network bridge](https://en.wikipedia.org/wiki/Network_bridge).

		!!! rpi "Connecting to a Raspberry Pi"
			1. On the mosaic-T, users will need to have already enabled the `Outgoing Internet Access Over USB` through the web interface or RxTool software suite *(described above)*.
			1. Then, users will need to configure the network connection on their Raspberry Pi.
				1. Open the network connections menu by opening the network manager (i.e. &uarr;&darr; or :fontawesome-solid-wifi: icon on taskbar) and selecting **Advanced Options** > **Edit Connections**.
				1. Check wired connections under ethernet, one of them should read 'Device: usb0 ....', double click -> IP v4 settings -> method: shared to other computers -> save.
					<figure markdown>
					Network Manager
					<figcaption markdown>Editing the connections through the Raspberry Pi's **Network Manager**.</figcaption>
					</figure>
			1. Determine the IP address assigned to the mosaic-T
				1. click on network manager - advanced options - connection information to get the ip of the same wired connection, 10.42.0.1 in my case
				1. Users will need to install a tool called nmap
					```bash
					sudo apt install nmap -y
					```
				1. In a terminal enter the following command to determine IP of mosaic
					```bash
					nmap <IP Address>/24
					```
					- Using `*/24` program to scan all class C subnet addresses (i.e. from `A.B.C.x` through `A.B.C.255`)
			1. ion
				1. use it to access the web interface, add NTRIP client (using rtk2go.com, must input an email, no password, select a mountpoint near you(http://monitor.use-snip.com/map)), now you should get RTK. If the mosaic is still not connecting, try to reboot it using the RST button on the breakout. The assigned IP will probably not change next time. Good luck.

			This web interface makes setting up really easy and you only need a usb cable to connect the breakout to a computer with internet.

<div class="grid" markdown>

<div markdown>

<article class="video-500px" style="text-align: center; margin: auto;" markdown>
<iframe src="https://www.youtube.com/embed/bUt8cL9Ue1Y" title="Septentrio: Share internet connection with your GNSS / GPS receiver over USB" frameborder="0" allow="accelerometer; autoplay; clipboard-write; encrypted-media; gyroscope; picture-in-picture" allowfullscreen></iframe>
</article>

</div>

</div>

!!! info "New IP Address"
	Once a network bridge is enabled, the receiver will receive its IP address from the computer's DHCP server. Depending on the routing table, the module may no longer be reachable at its default IP address *(`192.168.3.1`)*.

### More Videos
Users can find other instructional videos on [Septentrio's YouTube Channel](https://www.youtube.com/channel/UCrA9wMw1y1f-KeOnnhq4lrA/). Feel free to check out their playlists as well:

- [Getting Started](https://www.youtube.com/playlist?list=PLUxLg2_PvvdE0e2i2std6XyPnF6UdecAD)
- [How to *(Videos)* ](https://www.youtube.com/playlist?list=PLUxLg2_PvvdHZ73CnfhS7ZePIIIUR7bON)

??? note "Other Videos"

	<div class="grid" align="center" markdown>

	<div markdown>

	<article class="video-300px">
	<iframe src="https://www.youtube.com/embed/j_zHbl99FsI" title="Septentrio: How to reset a receiver" frameborder="0" allow="accelerometer; autoplay; clipboard-write; encrypted-media; gyroscope; picture-in-picture" allowfullscreen></iframe>
	</article>

	</div>

	<div markdown>

	<article class="video-300px">
	<iframe src="https://www.youtube.com/embed/D-iqzQnDbWw" title="Septentrio: How to copy the configuration from one to another receiver" frameborder="0" allow="accelerometer; autoplay; clipboard-write; encrypted-media; gyroscope; picture-in-picture" allowfullscreen></iframe>
	</article>

	</div>

	<div markdown>

	<article class="video-300px">
	<iframe src="https://www.youtube.com/embed/2XizOW3Dzzk" title="Septentrio: How to monitor the CPU of a Septentrio receiver" frameborder="0" allow="accelerometer; autoplay; clipboard-write; encrypted-media; gyroscope; picture-in-picture" allowfullscreen></iframe>
	</article>

	</div>

	<div markdown>

	<article class="video-300px">
	<iframe src="https://www.youtube.com/embed/9qN6b1JC3uE" title="Septentrio: How to generate and save a diagnostic report of a Septentrio receiver" frameborder="0" allow="accelerometer; autoplay; clipboard-write; encrypted-media; gyroscope; picture-in-picture" allowfullscreen></iframe>
	</article>

	</div>

	<div markdown>

	<article class="video-300px">
	<iframe src="https://www.youtube.com/embed/WU8MYrDALsE" title="Septentrio: How to log SBF data for support for Septentrio's GNSS/ GPS receivers" frameborder="0" allow="accelerometer; autoplay; clipboard-write; encrypted-media; gyroscope; picture-in-picture" allowfullscreen></iframe>
	</article>

	</div>

	<div markdown>

	<article class="video-300px">
	<iframe src="https://www.youtube.com/embed/lAP3TXz0ZL8" title="Septentrio: How to set up the PX4 Pixhawk and the Septentrio mosaic-go GNSS receiver Instruction video" frameborder="0" allow="accelerometer; autoplay; clipboard-write; encrypted-media; gyroscope; picture-in-picture" allowfullscreen></iframe>
	</article>

	</div>

	<div markdown>

	<article class="video-300px">
	<iframe src="https://www.youtube.com/embed/OdGE7bXgJck" title="Septentrio: How to set up ArduPilot with Septentrio AsteRx GNSS receiver + RIB and Pixhawk" frameborder="0" allow="accelerometer; autoplay; clipboard-write; encrypted-media; gyroscope; picture-in-picture" allowfullscreen></iframe>
	</article>

	</div>

	<div markdown>

	<article class="video-300px">
	<iframe src="https://www.youtube.com/embed/SzI0skGHKEw" title="Septentrio: Anti-jamming feature test-run" frameborder="0" allow="accelerometer; autoplay; clipboard-write; encrypted-media; gyroscope; picture-in-picture" allowfullscreen></iframe>
	</article>

	</div>

	<div markdown>

	<article class="video-300px">
	<iframe src="https://www.youtube.com/embed/H6uVVEJ5U5w" title="Septentrio: How to activate Wideband Interference Mitigation" frameborder="0" allow="accelerometer; autoplay; clipboard-write; encrypted-media; gyroscope; picture-in-picture" allowfullscreen></iframe>
	</article>

	</div>

	<div markdown>

	<article class="video-300px">
	<iframe src="https://www.youtube.com/embed/Ib_B_KcfmPs" title="Septentrio: How to use the spectrum plot" frameborder="0" allow="accelerometer; autoplay; clipboard-write; encrypted-media; gyroscope; picture-in-picture" allowfullscreen></iframe>
	</article>

	</div>

	</div>

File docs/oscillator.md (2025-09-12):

---
icon: material/sine-wave
---

!!! info
	This section describes a possible setup for a 10 MHz disciplined clock using the mosaic-T as a precision time source, which is particularly suitable in combination with Fugro AtomiChron^&reg;^ service. For more details, please refer to **Appendix D** of the [hardware manual](./assets/component_documentation/mosaic_hardware_manual_v1.11.0.pdf) and [firmware manual](./assets/component_documentation/firmware/mosaic-T_Firmware_v4.15.0_Reference_Guide.pdf).

!!! warning
	If the reference clock switch is set to `EXT`, users must provide a 10MHz input signal. Otherwise, the mosaic-T module will cease to operate, without a clock signal. Additionally, switching between external and internal frequency references must occur when the module is powered off, or the module must be reset after switching.

## Hardware Setup
The mosaic-T utilizes the 10-MHz signal from the steered oscillator as frequency reference, instead of its own internal crystal oscillator. An external controller, then reads the clock bias reported from the mosaic-T module in its SBF messages and steers it to zero by adjusting the frequency of the oscillator. When the clock bias is zero, the receiver time scale is aligned with GNSS time. Unlike traditional approaches, this architecture does not require any hardware to measure time delays.

<figure markdown>
Disciplined clock setup
<figcaption markdown>The setup for a disciplined clock with a mosaic-T module, controller, and a tunable oscillator.</figcaption>
</figure>

## Software Configuration

### mosaic-T
Users will configure the mosaic-T module to disable the PPS pulses and perform an initial synchronization to GNSS time on boot. These configurations are set by entering the SBF commands below. The commands only have to be entered once, as the last `exeCopyConfigFile` command makes them persistent in the boot configuration.

!!! serial
	These configurations are set by entering the following SBF commands:

	```bash
	setPPSParameters, off
	setClockSyncThreshold, usec500, on
	```

	To save the configurations to the module, enter the following SBF command:

	```bash
	exeCopyConfigFile, Current, Boot
	```

!!! info
	Refer to the [firmware manual](./assets/component_documentation/firmware/mosaic-T_Firmware_v4.15.0_Reference_Guide.pdf) for a more detailed description of these commands.

### Controller
At each subsequent (re)start of the system, the controller will need to execute the following algorithm:

1. Enable the output of the `PVTCartesian` (or `PVTGeodetic`) and of the `ReceiverTime` SBF blocks to the controller at a desired rate *(1Hz, in the example below)*.

	!!! serial
		These configurations are set by entering the following SBF commands:

		```bash
		setSBFGroups, Group1, PVTGeodetic+ReceiverTime
		setSBFOutput, Stream1, COM1, Group1, sec1
		```

		To save the configurations to the module, enter the following SBF command:

		```bash
		exeCopyConfigFile, Current, Boot
		```

1. Wait until the `FINETIME` bit is set in the `SyncLevel` field of the `ReceiverTime` SBF block. This indicates that the receiver's time initialization is complete.
1. Each time the `PVTCartesian` block is received by the controller, read the clock bias from its `RxClkBias` field.
1. The initial clock bias should be small (typically <200ns)
	- If the value is positive, adjust the tuning level to slightly decrease the oscillator frequency.
	- If the value is negative, adjust the tuning level to slightly increase the oscillator frequency.
1. Continue this process above, until the clock bias has converged to zero.
	- While steering the oscillator frequency, it is recommended to keep the rate of frequency change smaller than 3 ppb per second *(i.e. not to change the 10-MHz frequency by more than 0.03 Hz per second)*.
1. Once a lock is achieved, the receiver time will be synchronized with the GNSS time.
	- Users can then, enable the PPS signal from the mosaic-T in **RxClock** mode using the `setPPSParameters` command.

		!!! serial
			These configurations are set by entering the following SBF command:

			```bash
			setPPSParameters, <Interval>, <Polarity>, <Delay>, <TimeScale>, <MaxSyncAge>, <PulseWidth>
			```

			To save the configurations to the module, enter the following SBF command:

			```bash
			exeCopyConfigFile, Current, Boot
			```

		!!! info
			In RxClock mode, the PPS pulses will be aligned with the receiver's time and locked to the 10-MHz reference signal from the oscillator. *(i.e. Assuming a 1Hz PPS rate, the pulses will be generated exactly every 10 million cycles of the oscillator, in a constant phase with respect to the oscillator cycles.)*

1. Continue steering the clock bias to zero to keep the oscillator and the PPS aligned with the GNSS time.
	- During GNSS signal outages, the PPS pulses from the module will remain phase locked to the oscillator. The stability of the hold-over period, will depend on the quality of the oscillator.

!!! tip
	When using [Fugro's AtomiChron^&reg;^ service](atomichron.md), the reported clock will initially refer to the GNSS time scale during the first two to three minutes after start up, before switching to the AtomiChron^&reg;^ time scale. The change between reference time scales, may lead to a clock bias shift by a couple of nanoseconds. The reference time scale is reported in the `TimeSystem` field of the `PVTCartesian` SBF block and the jump can be avoided by waiting until that field is set to *Fugro AtomiChron* (`100`).

!!! note "Timing Delay"
	The PPS aligned signal, as described above, will typically be late by a few tens of nanoseconds. This is due to delays from the antenna, cables and RF frontend of the receiver.
		- In the mosaic modules, the frontend RF delay is about 10 ns.
		- Typical values for the antenna delay range from 10 to 20 ns, and coax cable delay amounts to about 5 ns per meter.
		- If the total delay is known, it can be compensated with the `setCalibCommonDelay` SBF command.

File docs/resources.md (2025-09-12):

## Product Resources

- :sfe: [Product Page](https://www.sparkfun.com/sparkfun-timing-gnss-breakout-mosaic-t.html)
- :material-folder-cog: Design Files:
	- :fontawesome-solid-file-pdf: [Board Dimensions](./assets/board_files/dimensions.pdf)
	- :fontawesome-solid-file-pdf: [Schematic](./assets/board_files/schematic.pdf)
	- :material-folder-zip: [KiCad Files](./assets/board_files/kicad_files.zip)
- Component Documentation
	- :fontawesome-solid-file-pdf: [mosaic-T Datasheet](./assets/component_documentation/mosaic_hardware_manual_v1.11.0.pdf)
		- :fontawesome-solid-file-pdf: [mosaic-T Brochure](./assets/component_documentation/Septentrio_mosaic-T_LR.pdf)
		- :fontawesome-solid-file-pdf: [Firmware Manual *(v4.15.0)*](./assets/component_documentation/firmware/mosaic-T_Firmware_v4.15.0_Reference_Guide.pdf)
	- :fontawesome-solid-file-pdf: [JST-GH Connector Datasheet](./assets/component_documentation/JST-GH_datasheet.pdf)
	- :fontawesome-solid-file-pdf: [AP7361C Datasheet](./assets/component_documentation/AP7361C.pdf)
	- :fontawesome-solid-file-pdf: [74LVC2T45 Datasheet](./assets/component_documentation/74LVC_LVCH2T45.pdf)
	- :fontawesome-solid-file-pdf: [LMV7219 Datasheet](./assets/component_documentation/lmv7219.pdf)
- :material-github: [Hardware Repo](https://github.com/sparkfun/SparkFun_GNSS_mosaic-T)

### Additional Resources

- :material-account-supervisor: [SparkFun Technical Assistance](https://www.sparkfun.com/technical_assistance)

## 🏭&nbsp;Manufacturer's Resources
Septentrio also provides great resources for the mossaic-T GNSS receiver module:

- [mosaic-T Product Page](https://www.septentrio.com/en/products/gps/gnss-receiver-modules/mosaic-T)
- :material-youtube: [Septentrio YouTube Channel](https://www.youtube.com/channel/UCrA9wMw1y1f-KeOnnhq4lrA/feed)
- [Support Page](https://www.septentrio.com/en/support)
	- :material-head-question: [Technical Support Portal](https://customersupport.septentrio.com/s/)
		- :material-head-lightbulb: [Knowledge Base](https://customersupport.septentrio.com/s/topiccatalog)
	- [Learn More](https://www.septentrio.com/en/learn-more)
		- [Webinars](https://www.septentrio.com/en/learn-more/webinars)
		- [Technical Papers](https://www.septentrio.com/en/learn-more/technical-papers)
		- [Insights](https://www.septentrio.com/en/learn-more/insights) *(Case Studies and Technical Articles)*
		- [Community](https://www.septentrio.com/en/learn-more/community)
		- [Agnostic Corrections Program](https://www.septentrio.com/en/products/correction-services/precise-point-positioning-services-land/agnostic-corrections-program-gnss-correction-services)
- [JammerTest 2023 - Anti-Jamming and Anti-Spoofing Performance](https://www.septentrio.com/en/learn-more/insights/most-resilient-gnss-receiver-results-jammertest-norway)

<article style="text-align: center;" markdown>
QR code to the hookup guide
</article>

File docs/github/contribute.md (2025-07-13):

## Make an Augmentation!
Spot an improvement opportunity? Feel free to contribute to our open-source design and documentation. 

## :material-file-document-multiple:&nbsp;Improve our Documentation
All of this documentation can be modified by you! Please help us make it better.

- These pages are contained in the [`docs` folder](https://github.com/sparkfun/SparkFun_GNSS_mosaic-T/tree/main/docs) of the [SparkFun GNSS Flex System repository](https://github.com/sparkfun/SparkFun_GNSS_mosaic-T).

<!-- ### :material-source-pull:&nbsp;Submit a Correction -->
### Submit a Correction

1. With a GitHub account, [fork this repository](https://github.com/sparkfun/SparkFun_GNSS_mosaic-T/fork).
1. Add your corrections or improvements to the markdown file.
1. File a pull request with your changes, and enjoy making the ~~words~~ ~~worlds~~ world a better place.
	- Once received, the documentation specialist will automatically be notified.
	- We will review your suggested improvements to make sure they are correct and fit within our documentation standards.

## :material-cog:&nbsp;Improve our Hardware Design
All of our designs are open-source! Please help us make it better.

- Our board design files are contained in the `/Hardware` directories of the [SparkFun GNSS Flex System repository](https://github.com/sparkfun/SparkFun_GNSS_mosaic-T).

<!-- ### :material-source-pull:&nbsp;Submit a Design Enhancement -->
### Submit a Design Enhancement

1. With a GitHub account, [fork this repository](https://github.com/sparkfun/SparkFun_GNSS_mosaic-T/fork).
1. Add your design augmentation(s)
1. File a pull request with your changes, and enjoy making the ~~words~~ ~~worlds~~ world a better place.
	1. Once received, the engineer in charge of the original design will automatically be notified.
	1. We will review your suggested improvement(s) to verify that they are within our board design standards and meet our product design requirements.
	1. If approved, we will flag these changes for our next board revision. Congrats! 🍻

		!!! info
			Even if your suggestion is accepted, these changes may not be immediately available for purchase. We may have to cycle through our current product inventory first.

## Contributors&nbsp;:clap:
Let's provide some recognition to the contributors for this project!

GitHub Contributors Image
<br>


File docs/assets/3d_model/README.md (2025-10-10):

3d_model directory
====================
This folder should contain the 3D model of the product

## Solder Mask - Color Correction Values
Hex: #E0311D
RGB: 224, 49, 29

## File Optimizer
https://glb.babylonpress.org/

- Enable these options
    - `Simplify | MeshoptSimplifier`
    - `Quantize | KHR_mesh_quantization`
    - `Use UASTC Zstandard Supercompression`
- Set these options, to the following values:
    - `ETC1S Quality Level (255 = best)`: 73
    - `ETC1S Compression Level (0 = fastest)`: 5

### VS Code Extension
To reorder the materials for the rendering, use the [GlTF Tools extension](https://marketplace.visualstudio.com/items?itemName=cesium.gltf-vscode) in VS Code

- https://marketplace.visualstudio.com/items?itemName=cesium.gltf-vscode
- https://github.com/AnalyticalGraphicsInc/gltf-vscode

## Model Editor
https://modelviewer.dev/editor/

## Old Methods

### File Converter - `*.wrl` to `*.glb`
https://imagetostl.com/convert/file/wrl/to/glb#convert

### Solder Mask - Color Correction
Open `*.glb` file and locate the `baseColorFactor` parameter with the following values:
```
          0.7027450799942017,
          0.1537254899740219,
          0.0909803956747055,
          0.8313725590705872
```
Replace those values with the following values: `[,,,1]`
```
          0.7418950796127319,
          0.0302486829459667,
          0.0122311776503920,
          1
```

### Solder Mask - Color Correction
https://3deditoronline.com/

### 1st File Optimizer *(Deprecated)*
https://www.loci-labs.com/optimizer

### 2nd File Optimizer *(Deprecated)*
https://xiehangyun.github.io/gltf-optimization/

- Max Texture Size: 512
- Create Unified Palette Texture for Solid Colors and Merge: *(Unselect)*

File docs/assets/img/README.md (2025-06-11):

img directory
====================
This folder should contain the images for the product documentation

## General Images
- `sfe-logo.png` - SparkFun flame logo (favicon)

## Directory
- `graphical_datasheet` - Files for graphical datasheet
- `hookup_guide` - Images for the hookup guide pages
- `qr_code` - QR code images
- `qwiic` - Images for Qwiic Banner

## Highlights
- Highlight: #00C8FF

## QR Codes
- [QR code generator](https://qrgenerator.org/)
	- Flame Color: #E0311D
	- Frame Color: #3C464D
- [Remove meta data from svg](https://jakearchibald.github.io/svgomg/)

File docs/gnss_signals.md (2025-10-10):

---
icon: fontawesome/solid/satellite
---

## Supported GNSS Signals
The mosaic-T module is capable of receiving most of the GNSS signals from the various frequency bands of each constellation. By default, the module is only configured to utilize signals (<span style="background-color:green;color:white;">marked in green</span>, in the table below) from specific satellites and frequency bands. Whereas, the <span style="background-color:var(--md-default-fg-color--lighter);">signals marked in grey</span> are also supported by the module, but each signal needs to be enabled before they can be integrated into the computed Position-Velocity-Time (PVT) solution. Meanwhile, any <span style="color:red;">~~signals colored in red and struck out~~</span> are not supported by the mosaic-T module; likely due to their proprietary nature, existence outside the module's frequency range, or are experimental/recently implemented.

<article style="text-align: center;" markdown>

<table border="1">

<tr>
	<th align="center" rowspan="2" colspan="2" style="min-width: 3rem;"></th>
	<th align="center" colspan="14">Frequency Band</th>
</tr>

<tr>
	<th align="center">L5/E5</th>
	<th align="center" colspan="6">L2</th>
	<th align="center" colspan="2">L6/E6</th>
	<th align="center" colspan="4">L1/E1</th>
	<th align="center">S</th>
</tr>

<tr>
	<th rowspan="7" class="rotate-cell" style="min-width: 3rem;">
		<div class="rotate-text">GNSS Constellation</div>
	</th>
	<th align="center">GPS</th>
	<td align="center" style="background-color:var(--md-default-fg-color--lighter);">L5</td>
	<td align="center" style="background-color:green;color:white;" colspan="2">L2PY</td>
	<td align="center" style="background-color:green;color:white;" colspan="2">L2C</td>
	<td align="center" style="color:red;" colspan="2"><s>L2M</s></td>
	<td align="center" colspan="2"></td>
	<td align="center" style="background-color:green;color:white;">L1CA</td>
	<td align="center" style="background-color:green;color:white;">L1PY</td>
	<td align="center" style="color:red;"><s>L1M</s></td>
	<td align="center" style="color:red;"><s>L1C</s></td>
	<td align="center"></td>
</tr>

<tr>
	<th align="center">GLONASS</th>
	<td align="center"></td>
	<td align="center" style="background-color:var(--md-default-fg-color--lighter);" colspan="2">L3</td>
	<td align="center" style="background-color:green;color:white;" colspan="2">L2P</td>
	<td align="center" style="background-color:green;color:white;" colspan="2">L2CA</td>
	<td align="center" colspan="2"></td>
	<td align="center" style="background-color:green;color:white;" colspan="2">L1CA</td>
	<td align="center" style="color:red;" colspan="2"><s>L1P</s></td>
	<td align="center"></td>
</tr>

<tr>
	<th align="center">Galileo</th>
	<td align="center" style="background-color:green;color:white;">E5a</td>
	<td align="center" style="background-color:green;color:white;" colspan="6">E5b</td>
	<td align="center" style="background-color:var(--md-default-fg-color--lighter);">E6BC</td>
	<td align="center" style="color:red;"><s>E6PRS</s></td>
	<td align="center" style="background-color:green;color:white;" colspan="2">E1BC</td>
	<td align="center" style="color:red;" colspan="2"><s>E1PRS</s></td>
	<td align="center"></td>
</tr>
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

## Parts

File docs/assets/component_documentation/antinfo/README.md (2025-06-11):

antinfo directory
====================

A copy of the latest antenna information package; at the time of the repository's latest release.

- [Antenna Information Package](antinfo-25.1.0-mosaic-T.suf) (SUF)
- [Release Notes](mosaic-T_AntInfo_25.1.0_Release_Notes.pdf) (PDF)

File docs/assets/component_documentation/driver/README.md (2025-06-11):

driver directory
====================

A copy of the USB driver from the module.

- [USB Driver](USB_driver_3_0_2_Installer.exe) (EXE)

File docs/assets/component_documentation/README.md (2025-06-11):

SparkFun Documentation
=======================

This directory should include any necessary datasheets, example number crunching, etc.

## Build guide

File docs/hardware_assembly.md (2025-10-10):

!!! danger "Important: Read Before Use!"
	!!! warning "ESD Sensitivity"
		The mosaic-T module is sensitive to [ESD](https://en.wikipedia.org/wiki/Electrostatic_discharge "Electrostatic Discharge"). Use a proper grounding system to make sure that the working surface and the components are at the same electric potential.

		??? info "ESD Precaution"
			As recommended by the manufacturer, we highly recommend that users take the necessary ESD precautions to avoid damaging their module.

			<div class="grid cards" markdown>

			<div markdown>

			<article class="video-500px" style="text-align: center; margin: auto;" markdown>
			<iframe src="https://www.youtube.com/embed/hrL5J6Q5gX8?si=jOPBat8rzMnL7Uz4&amp;start=26;&amp;end=35;" title="Septentrio: Getting Started Video (playback starts at ESD warning)" frameborder="0" allow="accelerometer; autoplay; clipboard-write; encrypted-media; gyroscope; picture-in-picture" allowfullscreen></iframe>
			QR code to play video
			</article>

			</div>

			-   <a href="https://www.sparkfun.com/ifixit-anti-static-wrist-strap.html">
				<figure markdown>
				Product Thumbnail
				</figure>

				---

				**iFixit Anti-Static Wrist Strap**<br>
				TOL-25572</a>

			</div>

	!!! warning "Active Antenna"
		Never inject an external DC voltage into the SMA connector for the GNSS antenna, as it may damage the mosaic-T module. For instance, when using a splitter to distribute the antenna signal to several GNSS receivers, make sure that no more than one output of the splitter passes DC. Use [DC-blocks](https://en.wikipedia.org/wiki/DC_block) otherwise.

	!!! warning "External Reference Clock"
		If the switch for an external reference clock is enabled, users must provide a 10MHz input signal. Otherwise, the mosaic-T module will cease to operate, without a clock signal.

## USB Programming
The USB connection is utilized for configuration and serial communication. Users only need to plug their mosaic-T Timing GNSS breakout board into a computer using a USB-C cable.

<div class="grid" markdown>

<div markdown>

<figure markdown>
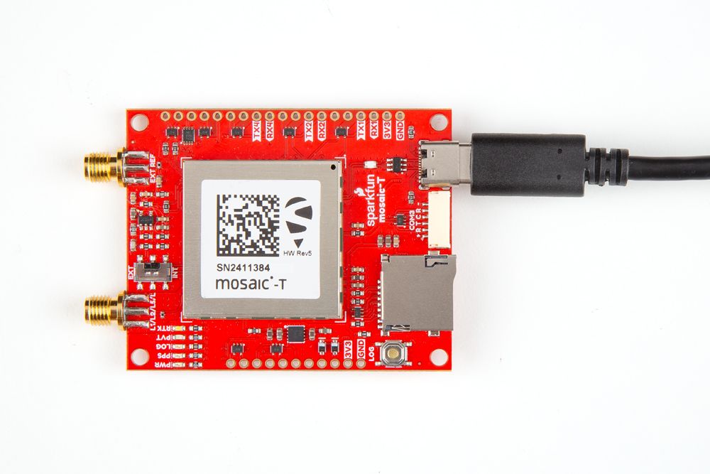
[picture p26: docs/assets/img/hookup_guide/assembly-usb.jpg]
USB connection

<figcaption markdown>The mosaic-T Timing GNSS breakout board with a USB-C cable attached.</figcaption>
</figure>

</div>

<div markdown>

1. When the board is initially connected to a computer, the module will initialize as a USB mass storage device.
	- For Windows PCs, the [USB driver](software_overview.md#usb-driver) can be installed from the mass storage device or the [RxTools software suite](software_overview.md#rxtools-software-suite).
	- When the SD card is mounted, this drive will contain the contents of the SD card that is inserted on the board.
1. Once the USB driver is installed:
	- Two virtual `COM` ports are emulated, which can be used as standard serial interfaces to access the receiver.
	- This interface also supports Ethernet-over-USB and the internal web server can be accessed `192.168.3.1`.

</div>

</div>

## GNSS Antenna
In order to receive [GNSS](https://en.wikipedia.org/wiki/Satellite_navigation "Global Navigation Satellite System") signals, users will need to connect a compatible antenna.

<div class="grid" markdown>

<div markdown>

<figure markdown>
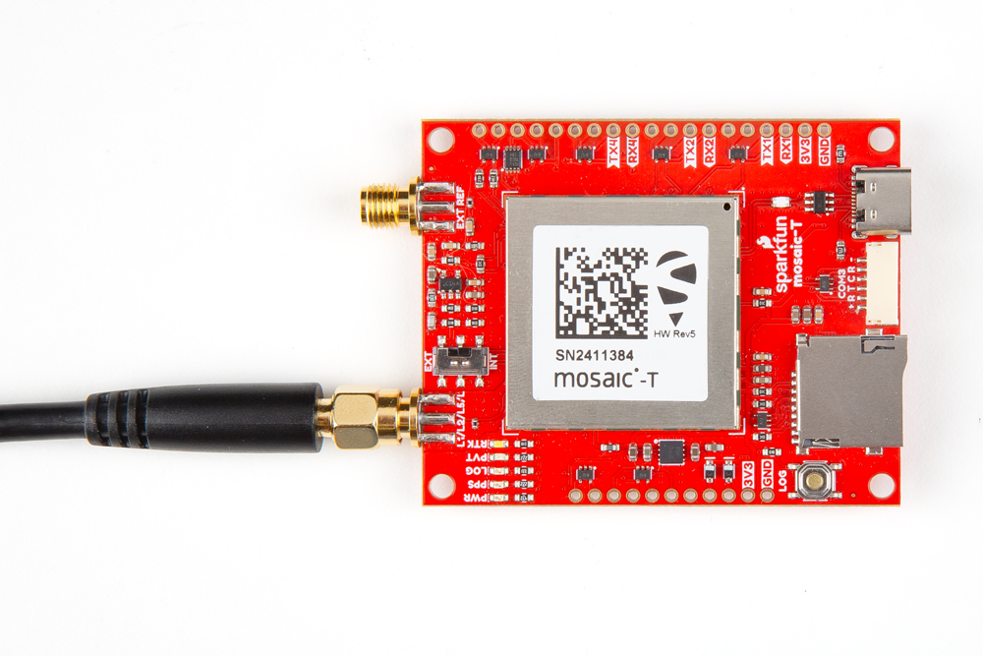
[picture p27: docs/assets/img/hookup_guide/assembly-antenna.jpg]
GNSS antenna connection

<figcaption markdown>Attaching a GNSS antenna to the SMA connector on the mosaic-T Timing GNSS breakout board.</figcaption>
</figure>

</div>

<div markdown>

!!! tip
	For the best performance, we recommend users choose a compatible L1/L2/L5/L-band GNSS antenna and utilize a low-loss cable. Also, don't forget that GNSS signals are fairly weak and can't penetrate buildings or dense vegetation. The GNSS antenna should have an unobstructed view of the sky.

!!! danger
	Never inject an external DC voltage into the SMA connector for the GNSS antenna, as it may damage the mosaic-T module. For instance, when using a splitter to distribute the antenna signal to several GNSS receivers, make sure that no more than one output of the splitter passes DC. Use [DC-blocks](https://en.wikipedia.org/wiki/DC_block) otherwise.

</div>

</div>

## SD Card
An &micro;SD card slot is available for users to log and store data, locally on the board. Users, will need to insert a compatible SD card and configure the mosaic-T module for data logging.

<div class="grid" markdown>

<div markdown>

<figure markdown>
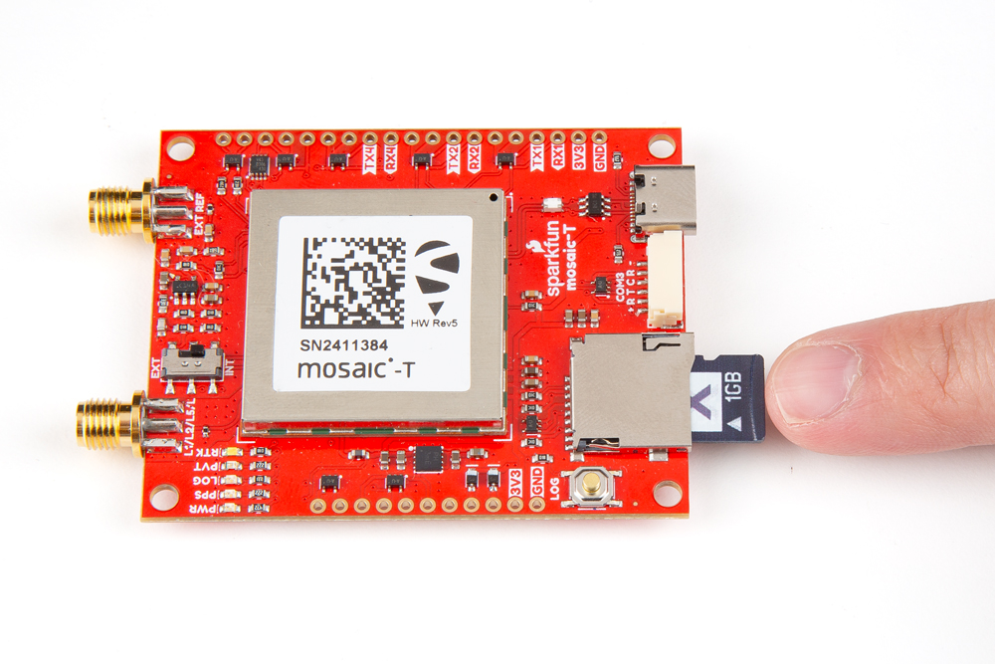
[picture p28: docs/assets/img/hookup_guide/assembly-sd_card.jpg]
SD card slot

<figcaption markdown>Inserting an SD card into the mosaic-T Timing GNSS breakout board.</figcaption>
</figure>

</div>

<div markdown>

!!! info "SD Card Specifications"
	The mosaic-T module is only compatible with SD cards of up to 32GB, formatted with a `FAT32` file system.

!!! success "Initial Configuration"
	Before data logging can occur, it is necessary to create a *logging stream* from the **Logging** tab of the web interface or using the **RxTools** software suite. Streams can contain NMEA or SBF (Septentrio Binary Format) data; SBF can contain RTCM and/or RINEX. *(see the [Data Logging](web_interface.md#data-logging) section)*

</div>

</div>

!!! info "Operation"
	Data logging can be controlled on the board through either the [++"LOG"++ button](hardware_overview.md#log-button) or [`LOG BTN` pin](hardware_overview.md#data-logging).

	- Pressing the button or pin `LOW` *(< 5s)* toggles data logging to the SD card on and off.
	- Holding the button or pin `LOW` for more than 5 seconds *(> 5s)* and then releasing it, will force the board to:
		- Unmount the SD card if it was mounted
		- Mount the SD card if it was unmounted

	!!! question "Status"
		The status of the SD card and data stream are indicated on the `LOG` LED and pin.

		<article style="text-align: center;" markdown>

		| LED      | Pin    | Status                           |
		|:-------: | :----: | :------------------------------- |
		| Off      | Low    | SD card not present or unmounted |
		| On       | High   | SD card present and mounted      |
		| Blinking | Pulses | Data logging activity            |

		</article>

!!! warning "Standby Mode"
	When Standby mode is initialized, the module terminates all running processes and unmounts the external SD card to avoid any log file corruption *(see the **[Power Modes](hardware_overview.md#power-modes)** section)*.

## JST Connector
The JST connector on the Timing GNSS board, breaks out the `COM3` UART port of the mosaic-T module.

<figure markdown>
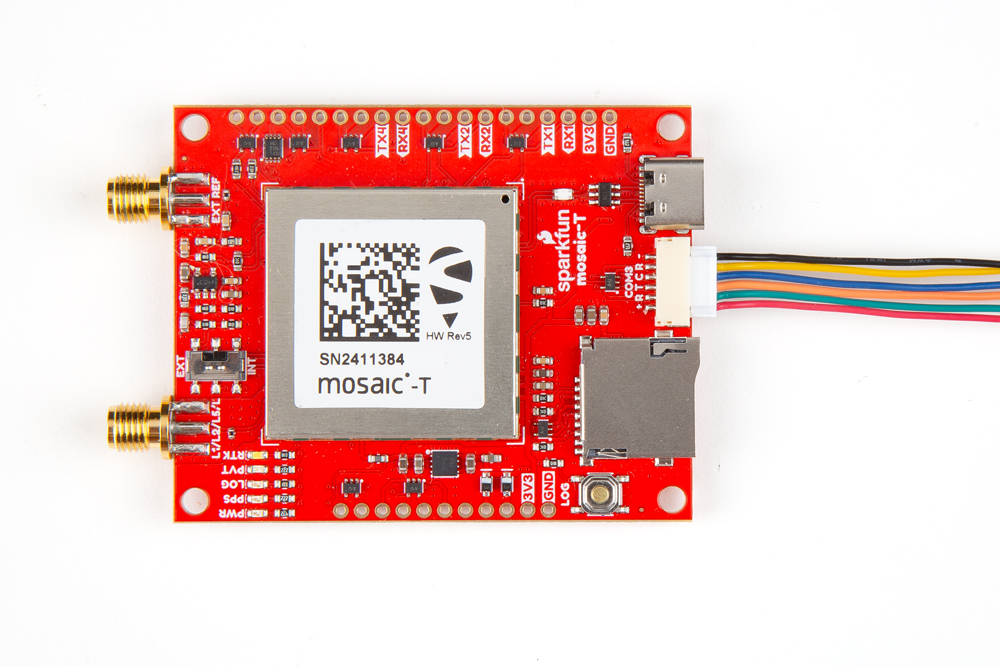
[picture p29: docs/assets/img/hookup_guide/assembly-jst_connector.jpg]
JST connector

<figcaption markdown>Connecting a cable to the JST connector of the mosaic-T Timing GNSS breakout board.</figcaption>
</figure>

!!! warning "Pin Connections"
	When connecting the mosaic-T Timing GNSS breakout board to another device through the JST connector, users need to be aware of the pin connections and voltage ranges of the products. Below, is a diagram of the pin connections for the 6-pin JST GH connector and a table of the connections for our radio transceivers that users can reference.

	<div class="grid cards desc" markdown>

	<div markdown>

	<figure markdown>
	JST pins
	<figcaption markdown>The pin connections of the JST connector on the mosaic-T Timing GNSS breakout board.</figcaption>
	</figure>

	</div>

	<article style="text-align: center;" markdown>

	<table border="1" markdown>
	<tr>
	<th style="vertical-align:middle;">Pin Number</th>
	<td align="center">
		**1**<br>
		*(Left Side)*
	</td>
	<td align="center">**2**</td>
	<td align="center">**3**</td>
	<td align="center">**4**</td>
	<td align="center">**5**</td>
	<td align="center">
		**6**<br>
		*(Right)*
	</td>
	</tr>
	<tr>
	<th style="vertical-align:middle;">Label</th>
	<td>
		V - Triband<br>
		5V - Radios
	</td>
	<td>
		RX - Triband/SiK<br>
		RXI - LoRaSerial
	</td>
	<td>
		TX - Triband/SiK<br>
		TXO - LoRaSerial
	</td>
	<td>
		C - Triband<br>
		CTS - Radios
	</td>
	<td>
		R - Triband<br>
		RTS - Radios
	</td>
	<td>
		G - Triband<br>
		GND - Radios
	</td>
	</tr>
	<tr>
	<th style="vertical-align:middle;">Function</th>
	<td>
		**Voltage Input**<br>
		- Triband: 3.5 to 5.5V<br>
		- SiK: 5V<br>
		- LoRaSerial: 3.3 to 5V
	</td>
	<td align="center" style="vertical-align:middle;">UART - Receive</td>
	<td align="center" style="vertical-align:middle;">UART - Transmit</td>
	<td align="center" style="vertical-align:middle;">
		Flow Control<br>
		*Clear-to-Send*
	</td>
	<td align="center" style="vertical-align:middle;">
		Flow Control<br>
		*Ready-to-Send*
	</td>
	<td align="center" style="vertical-align:middle;">Ground</td>
	</tr>
	</table>

	</article>

	</div>

## Breakout Pins
The [PTH](https://en.wikipedia.org/wiki/Through-hole_technology "Plated Through Holes") pins on the mosaic-T Timing GNSS board are broken out into 0.1"-spaced pins on the outer edges of the board.

??? note "New to soldering?"
	If you have never soldered before or need a quick refresher, check out our [How to Solder: Through-Hole Soldering](https://learn.sparkfun.com/tutorials/how-to-solder-through-hole-soldering) guide.

	<div class="grid cards" markdown align="center">

	-   <a href="https://learn.sparkfun.com/tutorials/5">
		<figure markdown>
		Tutorial thumbnail
		</figure>

		---
		
		**How to Solder: Through-Hole Soldering**</a>

	</div>

<div class="grid" markdown>

<div markdown>

**Headers**

---

When selecting headers, be sure you are aware of the functionality you require.

<figure markdown>
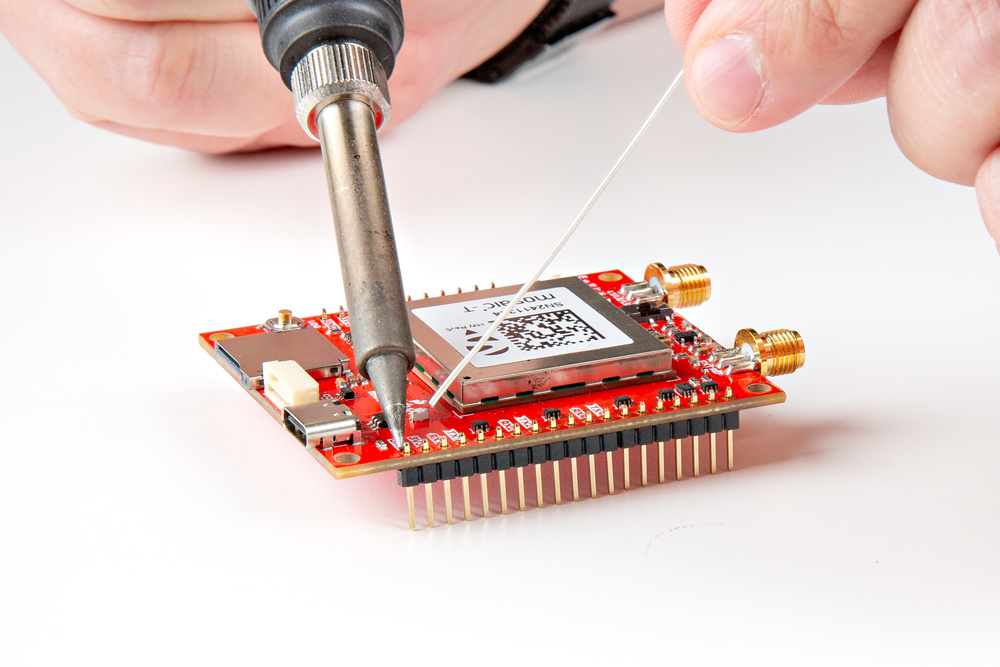
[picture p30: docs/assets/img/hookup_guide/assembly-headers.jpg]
Soldering headers

<figcaption markdown>Soldering headers to the mosaic-T Timing GNSS breakout board.</figcaption>
</figure>

</div>

<div markdown>

**Hookup Wires**

---

For a more permanent connection, users can solder wires directly to the board.

<figure markdown>
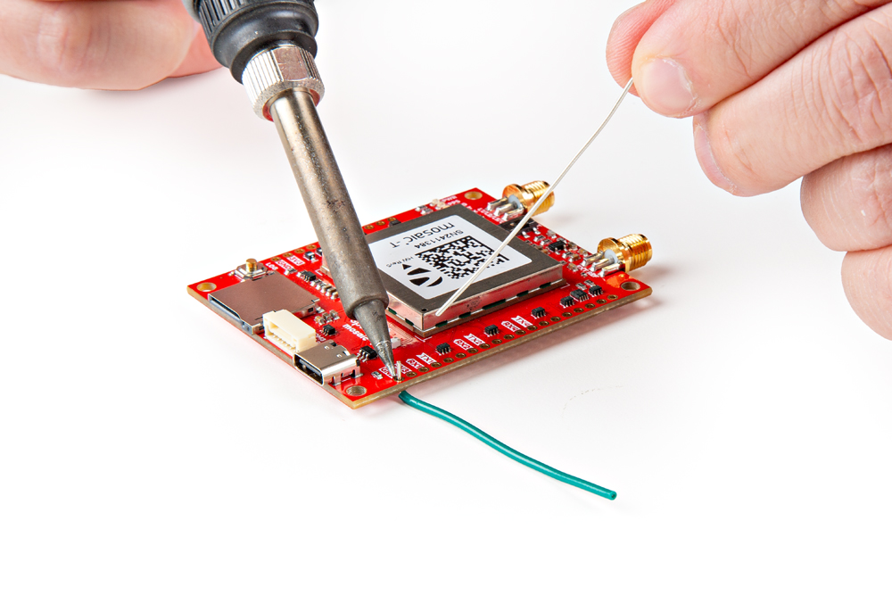
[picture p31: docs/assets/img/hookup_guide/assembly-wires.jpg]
Soldering wires

<figcaption markdown>Soldering wires to the mosaic-T Timing GNSS breakout board.</figcaption>
</figure>

</div>

</div>

## External Oscillator
In order to create a [GNSS disciplined oscillator](https://en.wikipedia.org/wiki/GPS_disciplined_oscillator), the mosaic-T module needs a 50&ohm;, 10MHz sinusoidal signal from tunable oscillator and a microcontroller to fine-tune the adjustments.

<div class="grid" markdown>

<div markdown>

!!! warning
	When the switch controlling the source of the reference clock is set to `EXT`, users must provide a 10MHz input signal. Otherwise, the mosaic-T module will cease to operate, without the clock signal. Additionally, the module should be powered off when switching between frequency reference sources; or the module will need to be reset after.

<figure markdown>
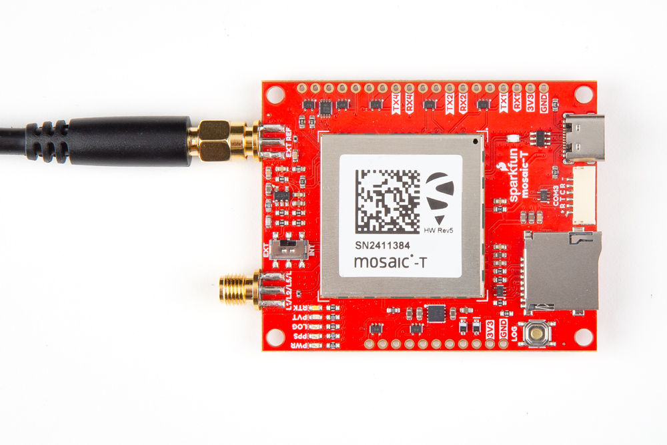
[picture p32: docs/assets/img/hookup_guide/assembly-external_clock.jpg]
External clock

<figcaption markdown>Connecting an external reference clock to the mosaic-T Timing GNSS breakout board.</figcaption>
</figure>

</div>

<div markdown>

!!! info
	To [convert the external reference clock into disciplined oscillator](oscillator.md), users will also need a controller to:

	- Read the clock bias from the mosaic-T module's SBF messages
	- Adjust the frequency of the external clock signal

	Unlike traditional approaches, this configuration does not require any external hardware to measure the time delay. Once the clock bias reaches zero, the oscillator's time scale will be aligned with the GNSS time. For time synchronization applications, users can also implement a [third-party synchronization service](atomichron.md) in the mosaic-T module's configuration. This will allow all systems to not only be aligned with the GNSS time, but also synchronized together.

	<figure markdown>
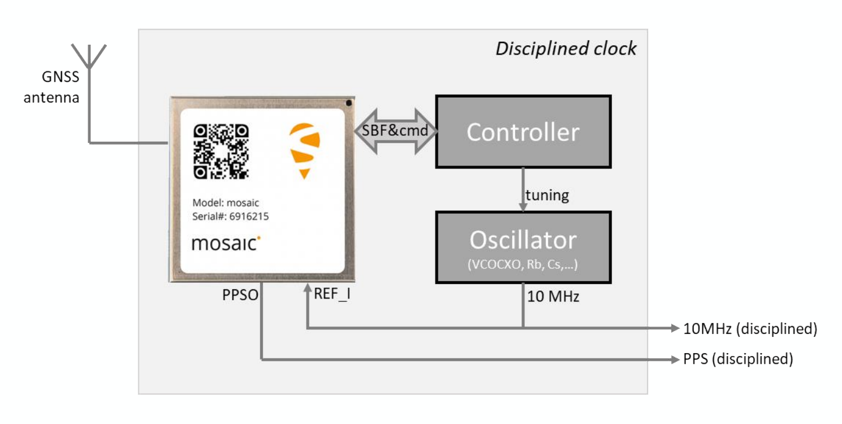
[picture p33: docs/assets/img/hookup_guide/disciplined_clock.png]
Disciplined clock setup
	
	<figcaption markdown>The setup for a disciplined clock with a mosaic-T module, controller, and a tunable oscillator.</figcaption>
	</figure>

</div>

</div>

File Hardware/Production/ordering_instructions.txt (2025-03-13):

Ordering Instructions:
Panel dimensions: 156.44 x 115.80 mm.
Controlled Impedance: JLC04161H-7628
Material: TG135
Solder Mask: Red
Silkscreen Color: White
Layers: 4
Finish: ENIG
Thickness: 1.6mm
Inner Copper Weight: 0.5oz
Outer Copper Weight: 1oz
Minimum track width: 0.18mm (7.00mil)
Minimum via drill: 0.30mm (12.00mil)
No Clean Process

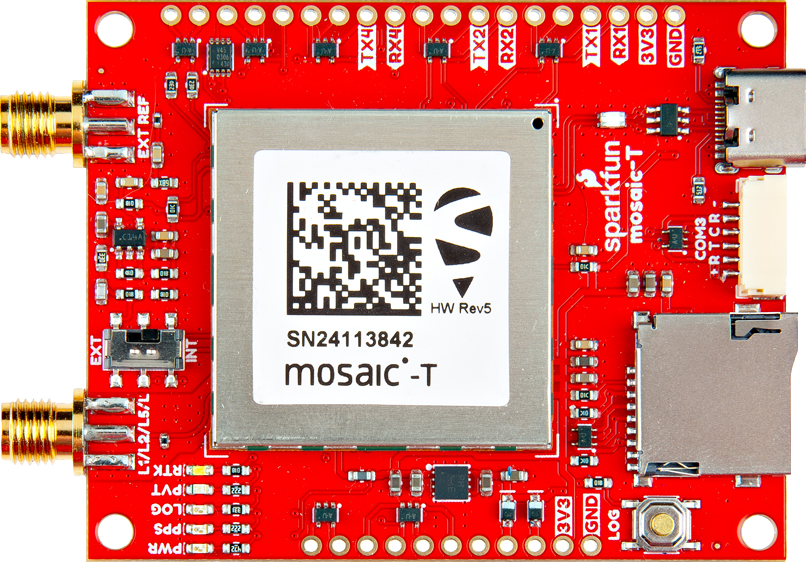
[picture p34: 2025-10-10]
docs/assets/img/hookup_guide/top.png

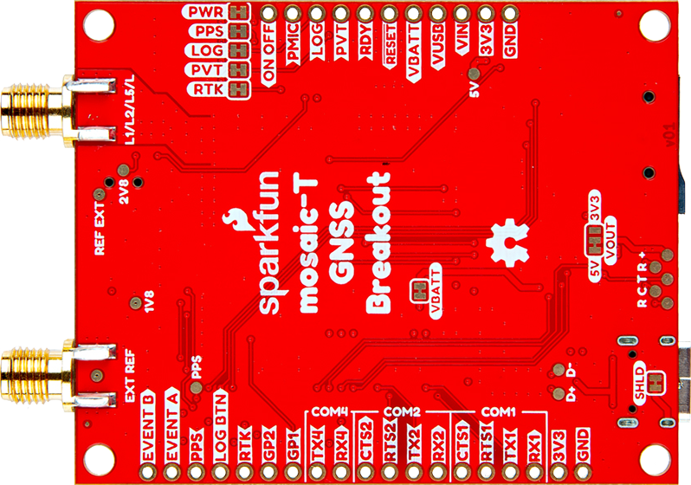
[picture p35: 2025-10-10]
docs/assets/img/hookup_guide/bottom.png

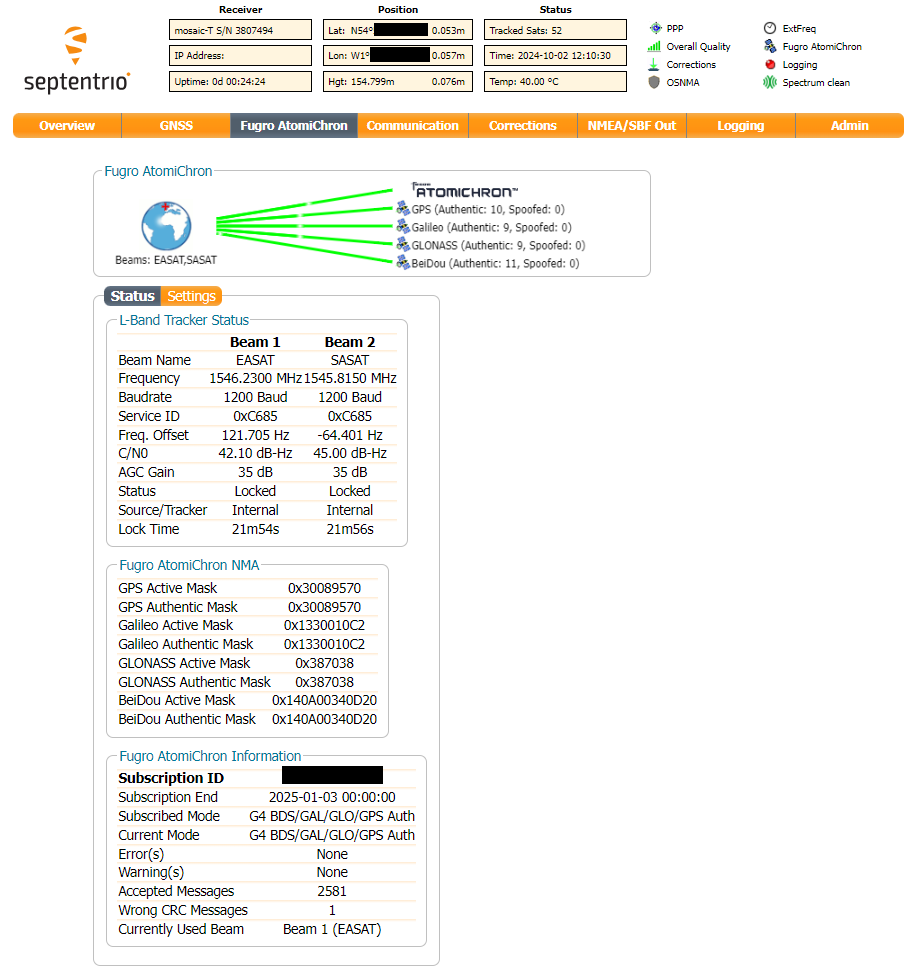
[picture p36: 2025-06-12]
docs/assets/img/hookup_guide/fugro/service-active.png

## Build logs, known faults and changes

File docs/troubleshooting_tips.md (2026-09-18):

---
icon: sfe
---

!!! warning "Need Help?"
	If you need technical assistance or more information on a product that is not working as you expected, we recommend heading on over to the [SparkFun Technical Assistance](https://www.sparkfun.com/technical_assistanc) page for some initial troubleshooting.

	<article style="text-align: center;" markdown>
	[SparkFun Technical Assistance Page](https://www.sparkfun.com/technical_assistance){ .md-button .md-button--primary }
	</article>
	
	If you can't find what you need there, the [SparkFun Forums](https://community.sparkfun.com/) is a great place to search product forums and ask questions.
	
	!!! info "Account Registration Required"
		If this is your first visit to our forum, you'll need to create a [Forum Account](https://community.sparkfun.com/signup) to post questions.

## Electrostatic Discharge
The mosaic-T module is sensitive to [ESD](https://en.wikipedia.org/wiki/Electrostatic_discharge "Electrostatic Discharge"). Use a proper grounding system to make sure that the working surface and the components are at the same electric potential.

!!! warning "ESD Precaution"
	As recommended by the manufacturer, we highly recommend that users take the necessary precautions to avoid damaging their module.

	<div class="video-500px" style="text-align: center; margin: auto;" markdown>
	<iframe src="https://www.youtube.com/embed/hrL5J6Q5gX8?si=jOPBat8rzMnL7Uz4&amp;start=26;&amp;end=35;" title="Septentrio: Getting Started Video (playback starts at ESD warning)" frameborder="0" allow="accelerometer; autoplay; clipboard-write; encrypted-media; gyroscope; picture-in-picture" allowfullscreen></iframe>
	QR code to play video
	</div>

## USB Driver
A USB driver is only required for Windows PCs *(see the [USB Driver](software_overview.md#usb-driver) section)*.

## GNSS Antenna

### Power Input
!!! danger "Active Antenna"
	Never inject an external DC voltage into the SMA connector for the GNSS antenna, as it may damage the mosaic-T module. For instance, when using a splitter to distribute the antenna signal to several GNSS receivers, make sure that no more than one output of the splitter passes DC. Use [DC-blocks](https://en.wikipedia.org/wiki/DC_block) otherwise.

### Supported Frequency Bands
For the best performance, we recommend users choose a compatible L1/L2/L5 (tri-band) GNSS antenna and utilize a low-loss cable. Utilizing an antenna that doesn't match all the supported frequency bands of the mosaic-T, will result in reduced performance and capabilities.

## Data Logging
For data logging issues, here are some simple troubleshooting tips:

- Make sure that your SD card is formatted to a `FAT32` file system.
	- The `FAT32` file system also limits the maximum capacity of the card to less than **32GB** *(i.e. a 256GB SD card will not work)*.
- Make sure that the mosaic-T module has a configured data stream output.
- Use the mosaic-T web page to verify that the SD card is mounted as a storage drive.

## External Reference Clock
If the switch for an external reference clock is enabled, users must provide a 10MHz input signal. Otherwise, the mosaic-T module will cease to operate, without a clock signal. Additionally, switching between external and internal frequency reference must occur when the module is powered off, or the module must be reset after switching.

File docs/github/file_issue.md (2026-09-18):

## Need Assistance?

<!-- Technical Assistance Box -->
!!! warning "Need Help?"
	If you need technical assistance or more information on a product that is not working as you expected, we recommend heading on over to the [SparkFun Technical Assistance](https://www.sparkfun.com/technical_assistance) page for some initial troubleshooting. This **Submit Issues** page is not where users should seek assistance.

	<article style="text-align: center;" markdown>
	[SparkFun Technical Assistance Page](https://www.sparkfun.com/technical_assistance){ .md-button .md-button--primary }
	</article>

	If you can't find what you need there, the [SparkFun Forums](https://community.sparkfun.com) is a great place to search the product forums and ask questions.

	!!! info "Account Registration Required"
		For your first visit to our forum, you'll need to create a [Forum Account](https://community.sparkfun.com/signup) to post questions.

## Did we make a mistake?
Spot something wrong? Please let us know. 

### Discrepancies in the Documentation
All of our documentation can be modified by you! Please help us make it better.

- The documentation files for these pages are contained in the [`docs` folder](https://github.com/sparkfun/SparkFun_GNSS_mosaic-T/tree/main/docs) of the [SparkFun GNSS Flex System repository](https://github.com/sparkfun/SparkFun_GNSS_mosaic-T).

#### 🔍 Spot something wrong?
If a section of the documentation is incorrect, please [open an issue](https://github.com/sparkfun/SparkFun_GNSS_mosaic-T/issues) and let us know.

#### Do you have a suggested correction?

1. With a GitHub account, [fork this repository](https://github.com/sparkfun/SparkFun_GNSS_mosaic-T/fork).
1. Add your correction(s) or improvement(s) to the markdown file(s)
1. File a pull request with your changes, and enjoy making the ~~words~~ ~~worlds~~ world a better place.
	- Once received, the documentation specialist will automatically be notified.
	- We will review your suggested improvement(s) to make sure they are correct and fit within our documentation standards.

### Problems in the Hardware Design
All of our designs are open-source! Please help us make it better.

- Our board design files are contained in the `/Hardware` directories of the [SparkFun GNSS Flex System repository](https://github.com/sparkfun/SparkFun_GNSS_mosaic-T).

#### Does something not make sense? 🤔
If part of the design is confusing, please [open an issue](https://github.com/sparkfun/SparkFun_GNSS_mosaic-T/issues) and let us know.

#### Did we forget to include an important function of the board? 🤦
If part of the board's functionality is missing, please [open an issue](https://github.com/sparkfun/SparkFun_GNSS_mosaic-T/issues) and file a feature request.

!!! tip "Design Considerations"
	Please keep in mind that we may intentionally exclude certain functions of the board to meet our product design requirements.

	- *For example, our Qwiic Micro boards are intended to fit on a small board layout and only use I^2^C communication; therefore, we may not have the SPI and interrupt pins available for users.*

#### Do you wish to contribute directly to improving the board design?

1. With a GitHub account, [fork this repository](https://github.com/sparkfun/SparkFun_GNSS_mosaic-T/fork).
1. Add your design augmentation(s)
1. File a pull request with your changes, and enjoy making the ~~words~~ ~~worlds~~ world a better place.
	1. Once received, the engineer in charge of the original design will automatically be notified.
	1. We will review your suggested improvement(s) to verify that they are within our board design standards and meet our product design requirements.
	1. If approved, we will flag these changes for our next board revision. Congrats! 🍻

		!!! info
			Even if your suggestion is accepted, these changes may not be immediately available for purchase. We may have to cycle through our current product inventory first.

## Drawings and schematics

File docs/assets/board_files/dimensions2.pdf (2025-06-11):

# 0.45 in Connector Mating Connector Mating

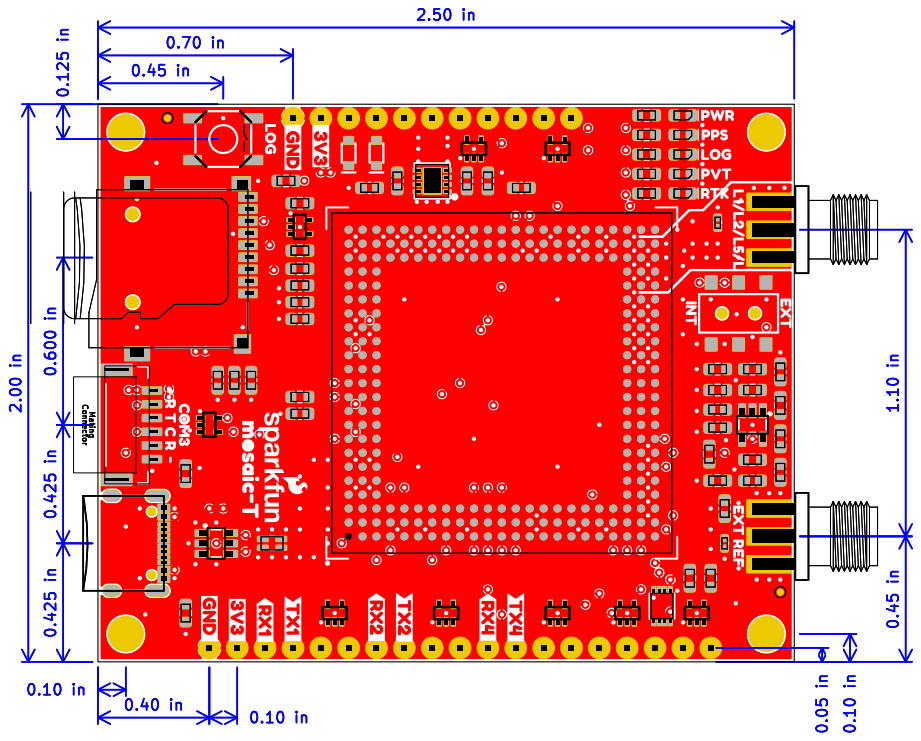
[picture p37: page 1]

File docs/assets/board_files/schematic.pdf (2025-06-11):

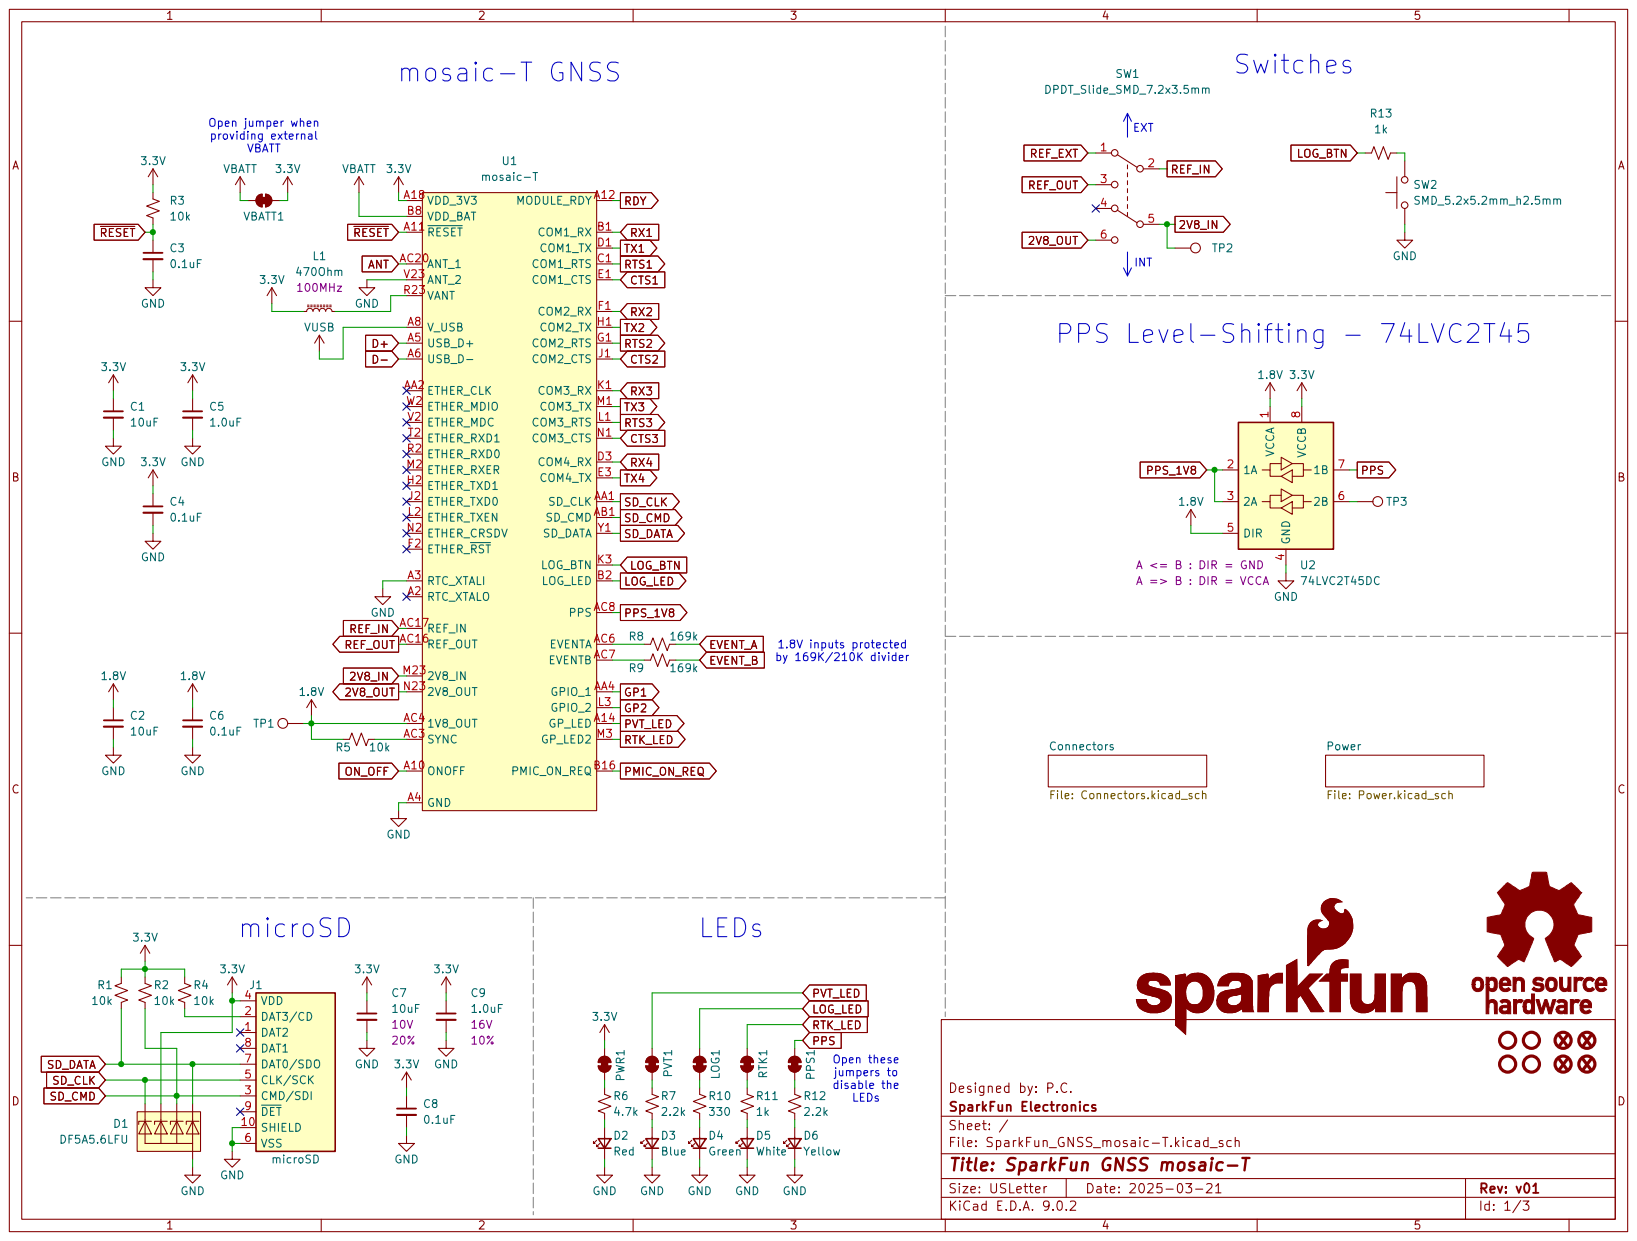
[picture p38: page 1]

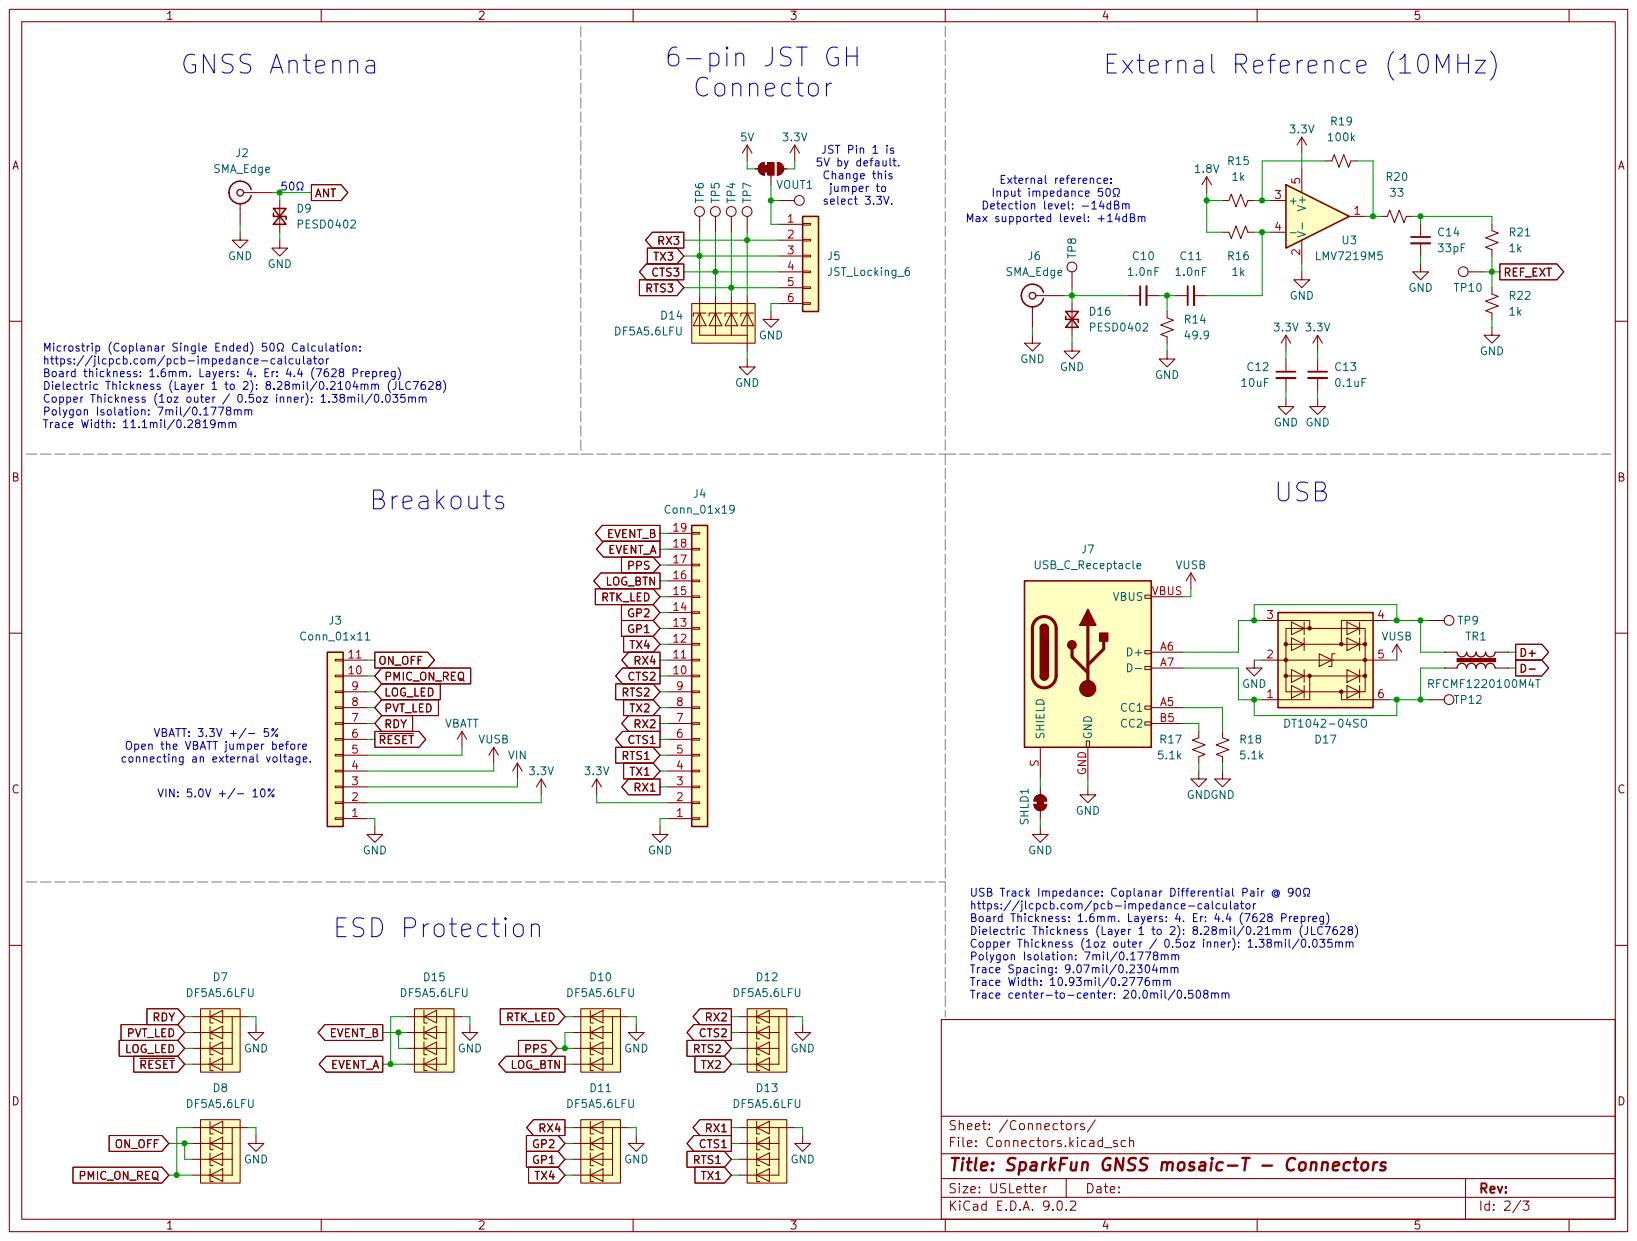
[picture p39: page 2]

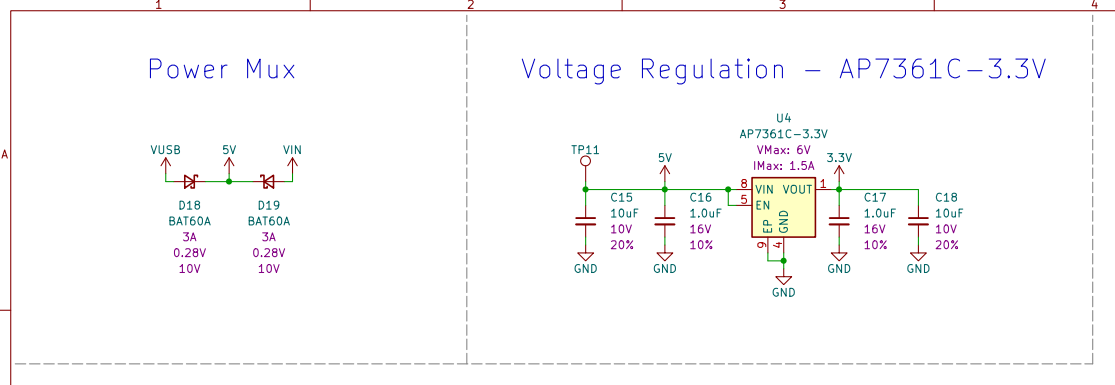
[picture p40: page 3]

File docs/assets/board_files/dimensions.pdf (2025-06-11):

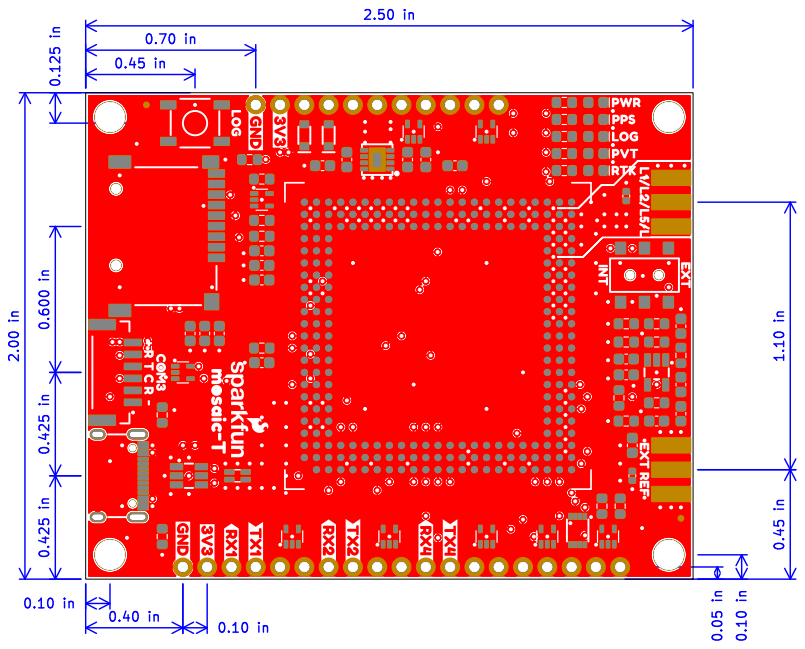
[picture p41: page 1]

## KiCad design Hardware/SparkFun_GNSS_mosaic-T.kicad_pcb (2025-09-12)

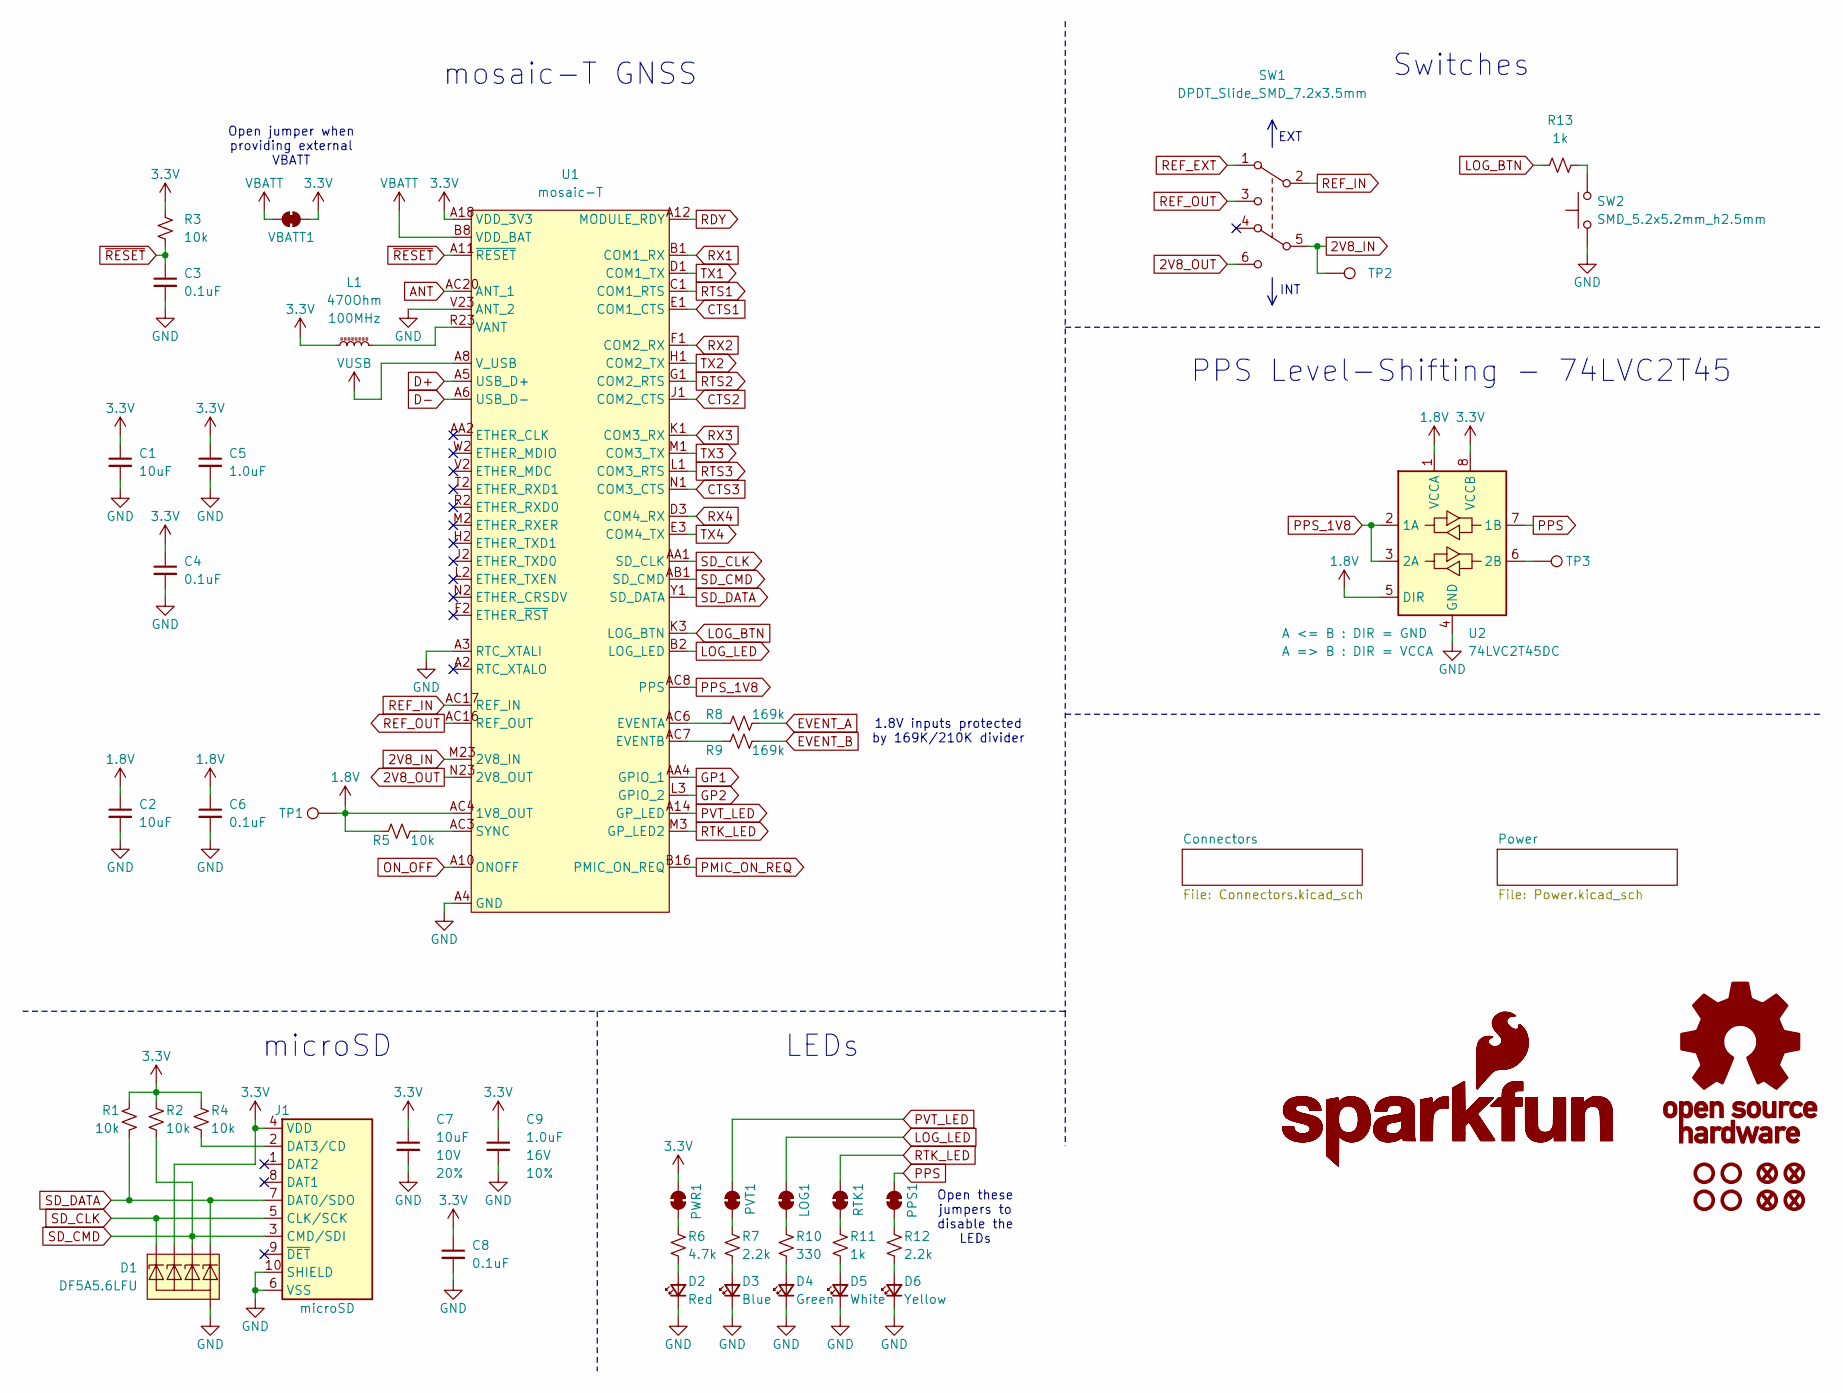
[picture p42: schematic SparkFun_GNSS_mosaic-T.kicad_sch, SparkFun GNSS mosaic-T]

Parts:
C1, C2, C7: 10uF; C_0603_1608Metric; Voltage 10V; Tolerance 20%
C3, C4, C6, C8: 0.1uF; C_0603_1608Metric; Voltage 25V; Tolerance 20%
C5, C9: 1.0uF; C_0603_1608Metric; Voltage 16V; Tolerance 10%
D1: DF5A5.6LFU; SOT-353
D2: Red; LED_0603_1608Metric_Red
D3: Blue; LED_0603_1608Metric_Blue
D4: Green; LED_0603_1608Metric_Green
D5: White; LED_0603_1608Metric_White
D6: Yellow; LED_0603_1608Metric_Yellow
FID1, FID2, FID3, FID4: Fiducial_0.5mm; Fiducial_0.5mm_Mask1mm
G1, G2: SparkFun_Logo
G3: OSHW_Logo; Creative_Commons_License
J1: microSD; microSD_External_Pin
L1: 470Ohm; C_0603_1608Metric
LOG1: Jumper_2_NC_Trace
PPS1: Jumper_2_NC_Trace
PVT1: Jumper_2_NC_Trace
PWR1: Jumper_2_NC_Trace
R1, R2, R3, R4, R5: 10k; R_0603_1608Metric
R6: 4.7k; R_0603_1608Metric
R7, R12: 2.2k; R_0603_1608Metric
R8, R9: 169k; R_0603_1608Metric
R10: 330; R_0603_1608Metric
R11, R13: 1k; R_0603_1608Metric
RTK1: Jumper_2_NC_Trace
ST1, ST2, ST3, ST4: Standoff
SW1: DPDT_Slide_SMD_7.2x3.5mm; Slide_DPDT_SMD_7.2x3.5mm; Mfg Part# ABC
SW2: SMD_5.2x5.2mm_h2.5mm; Push_SMD_5.2x5.2mm_h2.5mm
TP1, TP2, TP3: 1.25mm; TestPoint-1.25mm
U1: mosaic-T; MOSAIC_LGA
U2: 74LVC2T45DC; VSSOP8_SOT765-1
VBATT1: Jumper_2_NC_Trace

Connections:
1.8V: C2.1, C6.1, R5.1, TP1.1, U1.AC4 (1V8_OUT), U2.1 (VCCA), U2.5 (DIR); also elsewhere on the board
2V8_IN: SW1.5 (B), TP2.1, U1.M23 (2V8_IN)
2V8_OUT: SW1.6 (C), U1.N23 (2V8_OUT)
3.3V: C1.1, C4.1, C5.1, C7.1, C8.1, C9.1, D1.3 (K2), J1.4 (VDD), L1.1, PWR1.2 (B), R1.2, R2.2, R3.2, R4.2, U1.A18 (VDD_3V3), U1.A19 (VDD_3V3), U1.A20 (VDD_3V3), U1.B18 (VDD_3V3), U1.B19 (VDD_3V3), U1.B20 (VDD_3V3), U1.C18 (VDD_3V3), U1.C19 (VDD_3V3), U1.C20 (VDD_3V3), U2.8 (VCCB), VBATT1.1 (A); also elsewhere on the board
ANT: U1.AC20 (ANT_1); also elsewhere on the board
CTS1: U1.E1 (COM1_CTS); also elsewhere on the board
CTS2: U1.J1 (COM2_CTS); also elsewhere on the board
CTS3: U1.N1 (COM3_CTS); also elsewhere on the board
D+: U1.A5 (USB_D+); also elsewhere on the board
D-: U1.A6 (USB_D-); also elsewhere on the board
EVENT_A: R8.2; also elsewhere on the board
EVENT_B: R9.2; also elsewhere on the board
GND: C1.2, C2.2, C3.2, C4.2, C5.2, C6.2, C7.2, C8.2, C9.2, D1.2 (A), D2.1 (K), D3.1 (K), D4.1 (K), D5.1 (K), D6.1 (K), J1.6 (VSS), J1.10 (SHIELD), SW2.1, U1.A3 (RTC_XTALI), U1.A4 (GND), U1.A7 (GND), U1.A15 (GND), U1.A16 (GND), U1.A17 (GND), U1.A21 (GND), U1.A22 (GND), U1.A23 (GND), U1.AA13 (GND), U1.AA14 (GND), U1.AA15 (GND), U1.AA16 (GND), U1.AA17 (GND), U1.AA18 (GND), U1.AA19 (GND), U1.AA20 (GND), U1.AA21 (GND), U1.AA22 (GND), U1.AA23 (GND), U1.AB2 (GND), U1.AB3 (GND), U1.AB4 (GND), U1.AB5 (GND), U1.AB6 (GND), U1.AB7 (GND), U1.AB8 (GND), U1.AB13 (GND), U1.AB14 (GND), U1.AB15 (GND), U1.AB16 (GND), U1.AB17 (GND), U1.AB18 (GND), U1.AB19 (GND), U1.AB20 (GND), U1.AB21 (GND), U1.AB22 (GND), U1.AB23 (GND), U1.AC13 (GND), U1.AC15 (GND), U1.AC18 (GND), U1.AC19 (GND), U1.AC21 (GND), U1.AC22 (GND), U1.AC23 (GND), U1.B4 (GND), U1.B5 (GND), U1.B6 (GND), U1.B7 (GND), U1.B13 (GND), U1.B17 (GND), U1.B21 (GND), U1.C4 (GND), U1.C7 (GND), U1.C15 (GND), U1.C16 (GND), U1.C17 (GND), U1.C23 (GND), U1.D2 (GND), U1.D21 (GND), U1.D22 (GND), U1.D23 (GND), U1.E2 (GND), U1.E21 (GND), U1.E22 (GND), U1.E23 (GND), U1.F21 (GND), U1.F22 (GND), U1.F23 (GND), U1.G2 (GND), U1.G21 (GND), U1.G23 (GND), U1.H21 (GND), U1.H22 (GND), U1.H23 (GND), U1.J21 (GND), U1.J22 (GND), U1.J23 (GND), U1.K2 (GND), U1.K21 (GND), U1.K22 (GND), U1.K23 (GND), U1.L21 (GND), U1.L22 (GND), U1.L23 (GND), U1.M21 (GND), U1.M22 (GND), U1.N21 (GND), U1.N22 (GND), U1.P1 (GND), U1.P2 (GND), U1.P3 (GND), U1.P21 (GND), U1.P22 (GND), U1.R3 (GND), U1.R21 (GND), U1.R22 (GND), U1.T21 (GND), U1.T22 (GND), U1.T23 (GND), U1.U2 (GND), U1.U21 (GND), U1.U22 (GND), U1.U23 (GND), U1.V21 (GND), U1.V22 (GND), U1.V23 (ANT_2), U1.W21 (GND), U1.W22 (GND), U1.W23 (GND), U1.Y2 (GND), U1.Y21 (GND), U1.Y22 (GND), U1.Y23 (GND), U2.4 (GND); also elsewhere on the board
GP1: U1.AA4 (GPIO_1); also elsewhere on the board
GP2: U1.L3 (GPIO_2); also elsewhere on the board
LOG_BTN: R13.2, U1.K3 (LOG_BTN); also elsewhere on the board
LOG_LED: LOG1.2 (B), U1.B2 (LOG_LED); also elsewhere on the board
unnamed: D2.2 (A), R6.1
unnamed: D3.2 (A), R7.1
unnamed: D4.2 (A), R10.1
unnamed: D5.2 (A), R11.1
unnamed: D6.2 (A), R12.1
unnamed: J1.2 (DAT3/CD), R4.1
unnamed: LOG1.1 (A), R10.2
unnamed: PPS1.1 (A), R12.2
unnamed: PVT1.1 (A), R7.2
unnamed: PWR1.1 (A), R6.2
unnamed: R13.1, SW2.2
unnamed: R11.2, RTK1.1 (A)
unnamed: R8.1, U1.AC6 (EVENTA)
unnamed: R9.1, U1.AC7 (EVENTB)
unnamed: R5.2, U1.AC3 (SYNC)
unnamed: TP3.1, U2.6 (2B)
ON_OFF: U1.A10 (ONOFF); also elsewhere on the board
PMIC_ON_REQ: U1.B16 (PMIC_ON_REQ); also elsewhere on the board
PPS: PPS1.2 (B), U2.7 (1B); also elsewhere on the board
PPS_1V8: U1.AC8 (PPS), U2.2 (1A), U2.3 (2A)
PVT_LED: PVT1.2 (B), U1.A14 (GP_LED); also elsewhere on the board
RDY: U1.A12 (MODULE_RDY); also elsewhere on the board
REF_EXT: SW1.1 (A); also elsewhere on the board
REF_IN: SW1.2 (B), U1.AC17 (REF_IN)
REF_OUT: SW1.3 (C), U1.AC16 (REF_OUT)
RTK_LED: RTK1.2 (B), U1.M3 (GP_LED2); also elsewhere on the board
RTS1: U1.C1 (COM1_RTS); also elsewhere on the board
RTS2: U1.G1 (COM2_RTS); also elsewhere on the board
RTS3: U1.L1 (COM3_RTS); also elsewhere on the board
RX1: U1.B1 (COM1_RX); also elsewhere on the board
RX2: U1.F1 (COM2_RX); also elsewhere on the board
RX3: U1.K1 (COM3_RX); also elsewhere on the board
RX4: U1.D3 (COM4_RX); also elsewhere on the board
SD_CLK: D1.1 (K1), J1.5 (CLK/SCK), U1.AA1 (SD_CLK)
SD_CMD: D1.4 (K3), J1.3 (CMD/SDI), R2.1, U1.AB1 (SD_CMD)
SD_DATA: D1.5 (K4), J1.7 (DAT0/SDO), R1.1, U1.Y1 (SD_DATA)
TX1: U1.D1 (COM1_TX); also elsewhere on the board
TX2: U1.H1 (COM2_TX); also elsewhere on the board
TX3: U1.M1 (COM3_TX); also elsewhere on the board
TX4: U1.E3 (COM4_TX); also elsewhere on the board
VANT: L1.2, U1.P23 (VANT), U1.R23 (VANT)
VBATT: U1.B8 (VDD_BAT), VBATT1.2 (B); also elsewhere on the board
VUSB: U1.A8 (V_USB); also elsewhere on the board
~RESET: C3.1, R3.1, U1.A11 (~RESET); also elsewhere on the board

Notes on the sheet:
LEDs
PPS Level-Shifting - 74LVC2T45
Open jumper when providing external VBATT
mosaic-T GNSS
Switches
Open these jumpers to disable the LEDs
microSD
EXT
1.8V inputs protected by 169K/210K divider
INT

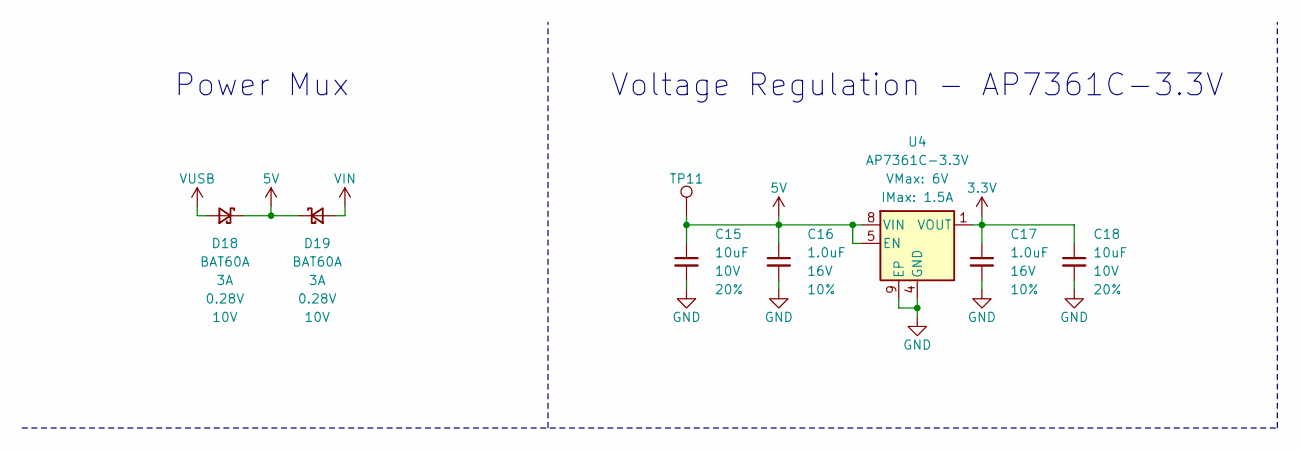
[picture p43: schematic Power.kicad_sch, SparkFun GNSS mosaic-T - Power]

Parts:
C15, C18: 10uF; C_0603_1608Metric; Voltage 10V; Tolerance 20%
C16, C17: 1.0uF; C_0603_1608Metric; Voltage 16V; Tolerance 10%
D18, D19: BAT60A; SOD-323
TP11: 1.25mm; TestPoint-1.25mm
U4: AP7361C-3.3V; UDFN-8

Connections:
3.3V: C17.1, C18.1, U4.1 (VOUT); also elsewhere on the board
5V: C15.1, C16.1, D18.1 (K), D19.1 (K), TP11.1, U4.5 (EN), U4.8 (VIN); also elsewhere on the board
GND: C15.2, C16.2, C17.2, C18.2, U4.4 (GND), U4.9 (EP); also elsewhere on the board
VIN: D19.2 (A); also elsewhere on the board
VUSB: D18.2 (A); also elsewhere on the board

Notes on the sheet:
Power Mux
Voltage Regulation - AP7361C-3.3V

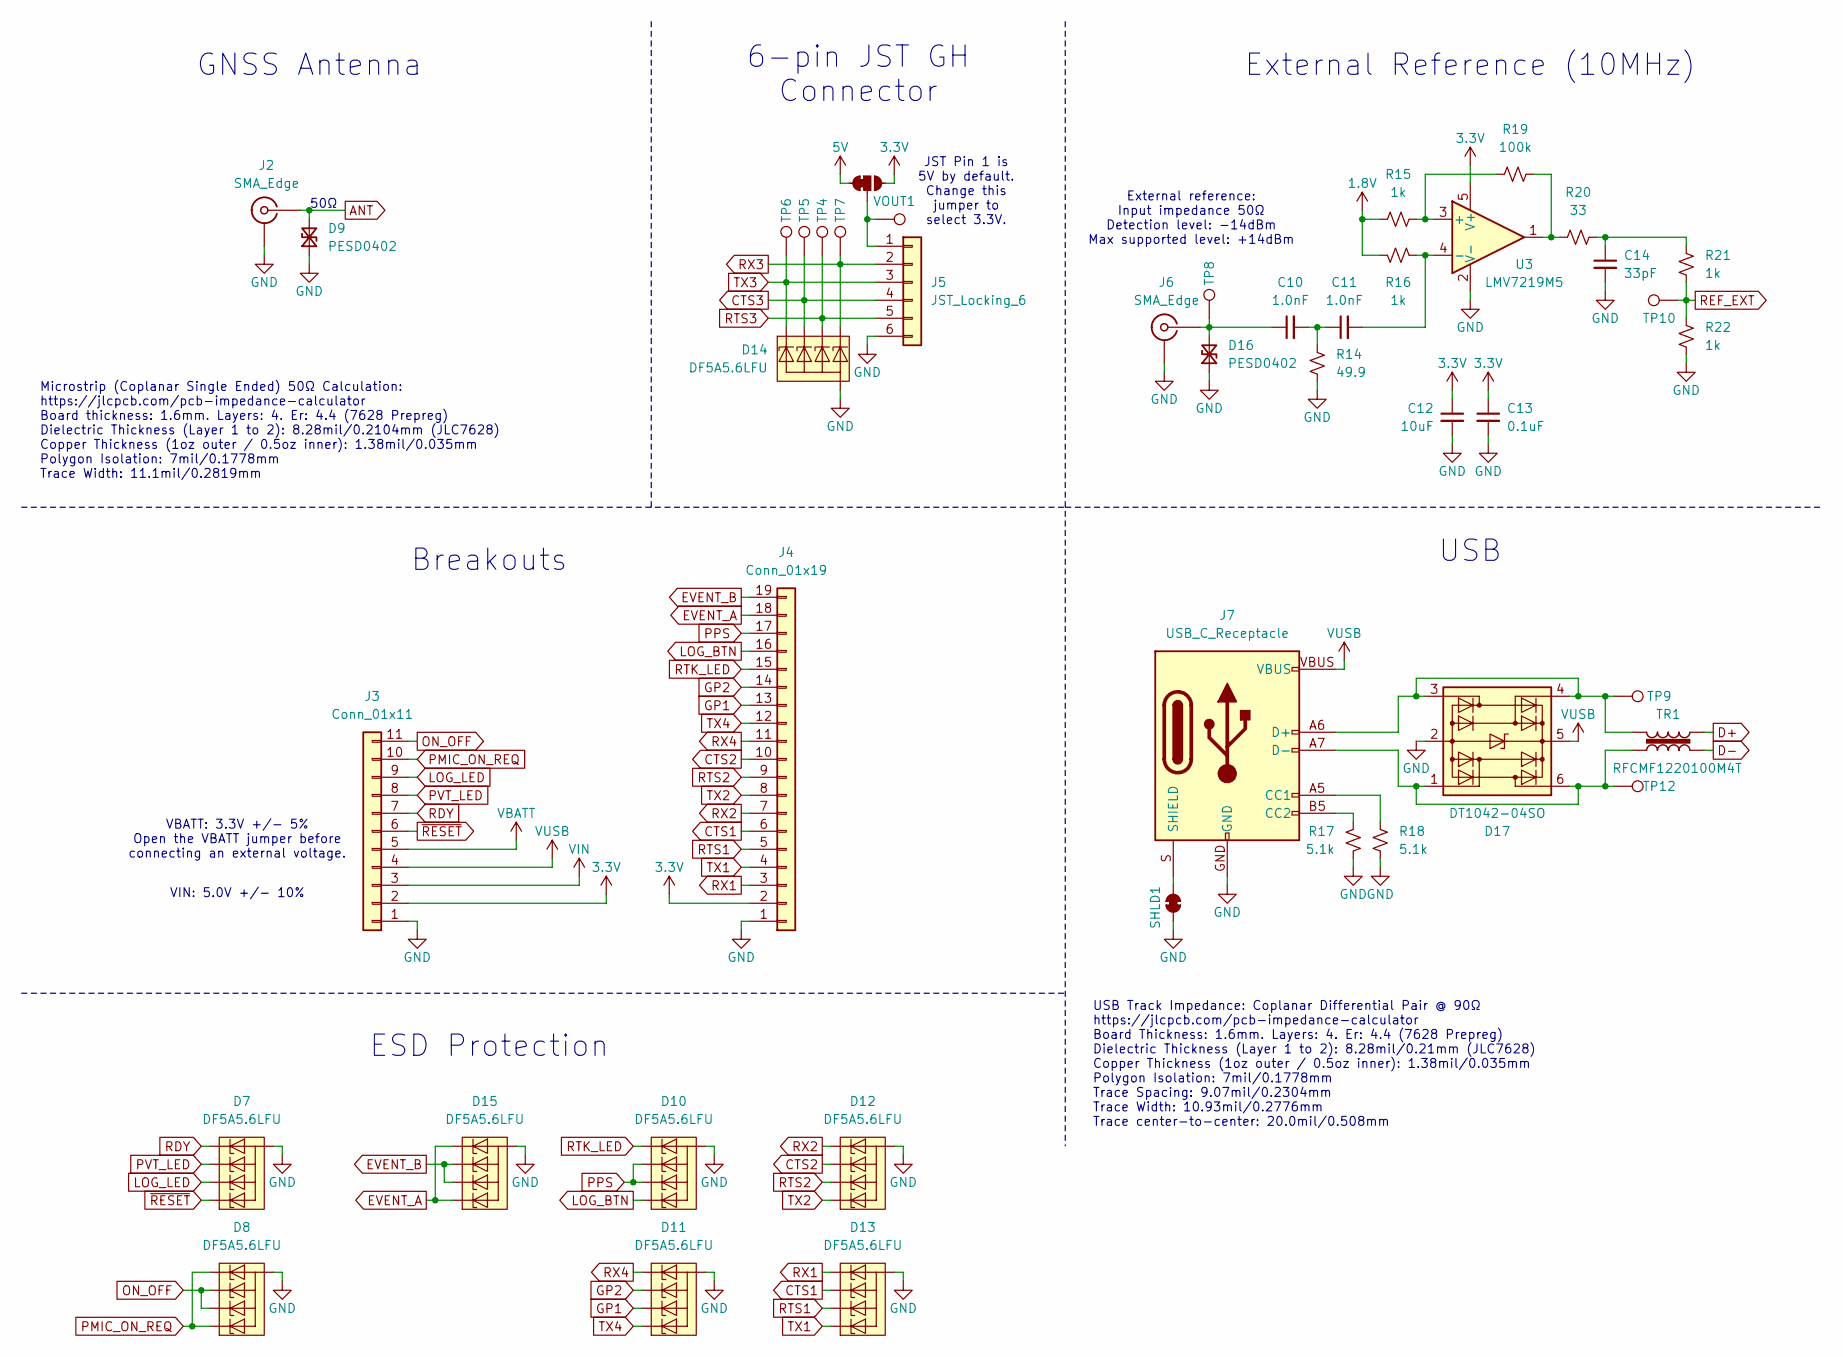
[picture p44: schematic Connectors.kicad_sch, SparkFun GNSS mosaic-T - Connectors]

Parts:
C10, C11: 1.0nF; C_0603_1608Metric; Voltage 50V; Tolerance 10%
C12: 10uF; C_0603_1608Metric; Voltage 10V; Tolerance 20%
C13: 0.1uF; C_0603_1608Metric; Voltage 25V; Tolerance 20%
C14: 33pF; C_0603_1608Metric; Voltage 50V; Tolerance 5%
D7, D8, D10, D11, D12, D13, D14, D15: DF5A5.6LFU; SOT-353
D9, D16: PESD0402; C_0402_1005Metric
D17: DT1042-04SO; SOT23-6
J2, J6: SMA_Edge
J3: Conn_01x11; 1x11
J4: Conn_01x19; 1x19
J5: JST_Locking_6; JST_SMD_1.25mm-6_Locking
J7: USB_C_Receptacle; USB-C_16
R14: 49.9; R_0603_1608Metric; Tolerance 1%
R15, R16, R21, R22: 1k; R_0603_1608Metric
R17, R18: 5.1k; R_0603_1608Metric
R19: 100k; R_0603_1608Metric
R20: 33; R_0603_1608Metric
SHLD1: Jumper_2_NC_Trace
TP4, TP5, TP6, TP7, TP8, TP9, TP10, TP12, TP13: 1.25mm; TestPoint-1.25mm
TR1: RFCMF1220100M4T
U3: LMV7219M5; SOT23-5
VOUT1: Jumper_3_NC-1_Trace

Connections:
1.8V: R15.2, R16.2; also elsewhere on the board
3.3V: C12.1, C13.1, J3.2, J4.2, U3.5 (V+), VOUT1.3 (C); also elsewhere on the board
5V: VOUT1.1 (A); also elsewhere on the board
ANT: D9.2 (A2), J2.1 (In); also elsewhere on the board
CTS1: D13.4 (K3), J4.6; also elsewhere on the board
CTS2: D12.4 (K3), J4.10; also elsewhere on the board
CTS3: D14.3 (K2), J5.4, TP5.1; also elsewhere on the board
D+: TR1.4; also elsewhere on the board
D-: TR1.2; also elsewhere on the board
EVENT_A: D15.1 (K1), D15.5 (K4), J4.18; also elsewhere on the board
EVENT_B: D15.3 (K2), D15.4 (K3), J4.19; also elsewhere on the board
GND: C12.2, C13.2, C14.2, D7.2 (A), D8.2 (A), D9.1 (A1), D10.2 (A), D11.2 (A), D12.2 (A), D13.2 (A), D14.2 (A), D15.2 (A), D16.1 (A1), D17.2 (GND), J2.2 (Ext), J3.1, J4.1, J5.6, J6.2 (Ext), J7.GND, R14.1, R17.1, R18.1, R22.2, SHLD1.1 (A), U3.2 (V-); also elsewhere on the board
GP1: D11.3 (K2), J4.13; also elsewhere on the board
GP2: D11.4 (K3), J4.14; also elsewhere on the board
LOG_BTN: D10.1 (K1), J4.16; also elsewhere on the board
LOG_LED: D7.3 (K2), J3.9; also elsewhere on the board
unnamed: C10.2, C11.1, R14.2
unnamed: C14.1, R20.2, R21.1
unnamed: C10.1, D16.2 (A2), J6.1 (In), TP8.1
unnamed: D17.1 (I/O1), D17.6 (I/O4), J7.A7 (D-), J7.B7 (D-), TP12.1, TR1.1
unnamed: D17.3 (I/O2), D17.4 (I/O3), J7.A6 (D+), J7.B6 (D+), TP9.1, TR1.3
unnamed: J5.1, TP13.1, VOUT1.2 (B)
unnamed: J7.A5 (CC1), R18.2
unnamed: J7.B5 (CC2), R17.2
unnamed: J7.S (SHIELD), SHLD1.2 (B)
unnamed: R19.2, R20.1, U3.1
unnamed: R15.1, R19.1, U3.3 (+)
unnamed: C11.2, R16.1, U3.4 (-)
ON_OFF: D8.3 (K2), D8.4 (K3), J3.11; also elsewhere on the board
PMIC_ON_REQ: D8.1 (K1), D8.5 (K4), J3.10; also elsewhere on the board
PPS: D10.3 (K2), D10.4 (K3), J4.17; also elsewhere on the board
PVT_LED: D7.4 (K3), J3.8; also elsewhere on the board
RDY: D7.5 (K4), J3.7; also elsewhere on the board
REF_EXT: R21.2, R22.1, TP10.1; also elsewhere on the board
RTK_LED: D10.5 (K4), J4.15; also elsewhere on the board
RTS1: D13.3 (K2), J4.5; also elsewhere on the board
RTS2: D12.3 (K2), J4.9; also elsewhere on the board
RTS3: D14.4 (K3), J5.5, TP4.1; also elsewhere on the board
RX1: D13.5 (K4), J4.3; also elsewhere on the board
RX2: D12.5 (K4), J4.7; also elsewhere on the board
RX3: D14.5 (K4), J5.2, TP7.1; also elsewhere on the board
RX4: D11.5 (K4), J4.11; also elsewhere on the board
TX1: D13.1 (K1), J4.4; also elsewhere on the board
TX2: D12.1 (K1), J4.8; also elsewhere on the board
TX3: D14.1 (K1), J5.3, TP6.1; also elsewhere on the board
TX4: D11.1 (K1), J4.12; also elsewhere on the board
VBATT: J3.5; also elsewhere on the board
VIN: J3.3; also elsewhere on the board
VUSB: D17.5 (VCC), J3.4, J7.VBUS; also elsewhere on the board
~RESET: D7.1 (K1), J3.6; also elsewhere on the board

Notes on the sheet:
Breakouts
USB Track Impedance: Coplanar Differential Pair @ 90Ω https://jlcpcb.com/pcb-impedance-calculator Board Thickness: 1.6mm. Layers: 4. Er: 4.4 (7628 Prepreg) Dielectric Thickness (Layer 1 to 2): 8.28mil/0.21mm (JLC7628) Copper Thickness (1oz outer / 0.5oz inner): 1.38mil/0.035mm Polygon Isolation: 7m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
50Ω
GNSS Antenna
JST Pin 1 is 5V by default. Change this jumper to select 3.3V.
USB
External Reference (10MHz)
Microstrip (Coplanar Single Ended) 50Ω Calculation: https://jlcpcb.com/pcb-impedance-calculator Board thickness: 1.6mm. Layers: 4. Er: 4.4 (7628 Prepreg) Dielectric Thickness (Layer 1 to 2): 8.28mil/0.2104mm (JLC7628) Copper Thickness (1oz outer / 0.5oz inner): 1.38mil/0.035mm Polygon Isolation: 7m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
6-pin JST GH Connector
ESD Protection
VBATT: 3.3V +/- 5% Open the VBATT jumper before connecting an external voltage.
VIN: 5.0V +/- 10%
External reference: Input impedance 50Ω Detection level: -14dBm Max supported level: +14dBm

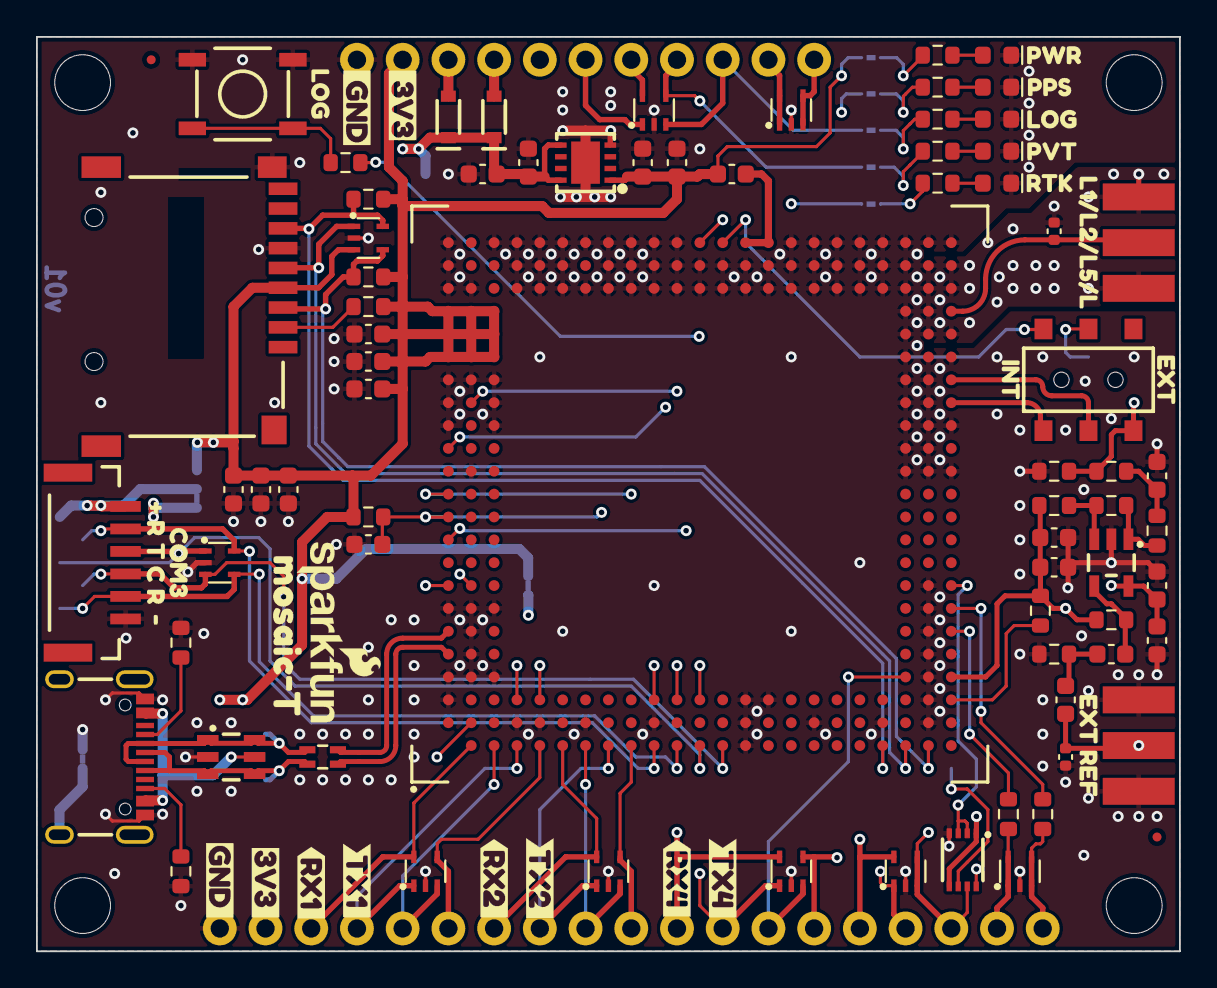
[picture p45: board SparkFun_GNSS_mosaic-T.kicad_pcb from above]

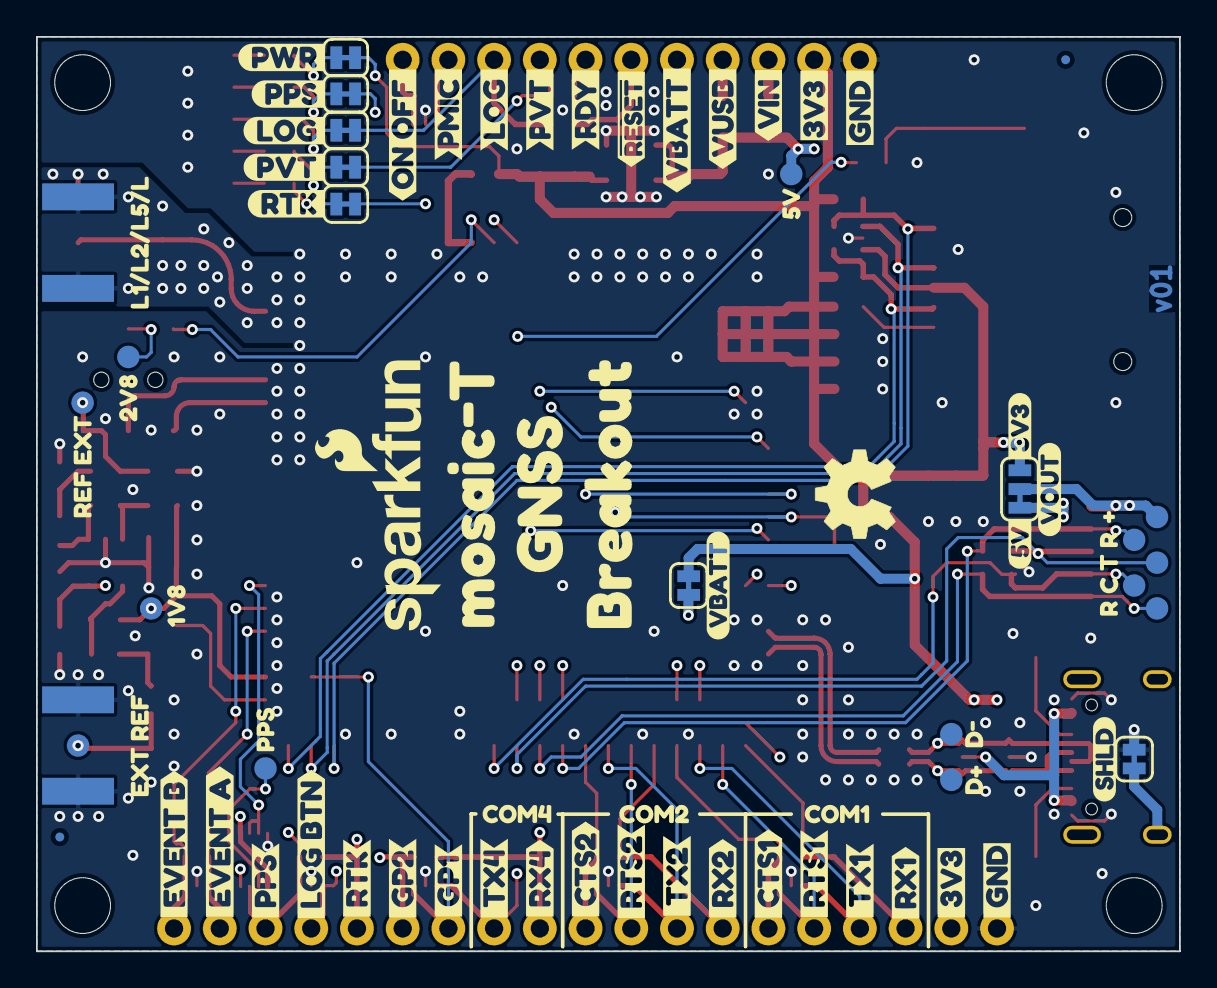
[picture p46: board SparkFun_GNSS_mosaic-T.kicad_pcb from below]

Board: 4 copper layers, 63.5 x 50.8 mm, 193 parts (84 on the bottom side), 75 nets.

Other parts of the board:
Ref**: Val**; OSHW_Logo_5mm
kibuzzard-67D03C98, kibuzzard-67D03C98#2: G***; kibuzzard-67D03C98
kibuzzard-67D03CC5, kibuzzard-67D03CC5#2: G***; kibuzzard-67D03CC5
kibuzzard-67D04A61: G***; kibuzzard-67D04A61
kibuzzard-67D04A72: G***; kibuzzard-67D04A72
kibuzzard-67D04A80: G***; kibuzzard-67D04A80
kibuzzard-67D04A91: G***; kibuzzard-67D04A91
kibuzzard-67D04AA3: G***; kibuzzard-67D04AA3
kibuzzard-67D04B0C: G***; kibuzzard-67D04B0C
kibuzzard-67D04B28: G***; kibuzzard-67D04B28
kibuzzard-67D04B58: G***; kibuzzard-67D04B58
kibuzzard-67D04B80: G***; kibuzzard-67D04B80
kibuzzard-67D04D07: G***; kibuzzard-67D04D07
kibuzzard-67D04D20: G***; kibuzzard-67D04D20
kibuzzard-67D04D30: G***; kibuzzard-67D04D30
kibuzzard-67D04D50: G***; kibuzzard-67D04D50
kibuzzard-67D04D99: G***; kibuzzard-67D04D99
kibuzzard-67D04E6C: G***; kibuzzard-67D04E6C
kibuzzard-67D04E18: G***; kibuzzard-67D04E18
kibuzzard-67D04E88: G***; kibuzzard-67D04E88
kibuzzard-67D04E93: G***; kibuzzard-67D04E93
kibuzzard-67D04EAA: G***; kibuzzard-67D04EAA
kibuzzard-67D04FB5: G***; kibuzzard-67D04FB5
kibuzzard-67D022A2: G***; kibuzzard-67D022A2
kibuzzard-67D022AC: G***; kibuzzard-67D022AC
kibuzzard-67D035E7: G***; kibuzzard-67D035E7
kibuzzard-67D035FF: G***; kibuzzard-67D035FF
kibuzzard-67D044A8: G***; kibuzzard-67D044A8
kibuzzard-67D044BC: G***; kibuzzard-67D044BC
kibuzzard-67D044ED: G***; kibuzzard-67D044ED
kibuzzard-67D045AD: G***; kibuzzard-67D045AD
kibuzzard-67D045C9: G***; kibuzzard-67D045C9
kibuzzard-67D045EC: G***; kibuzzard-67D045EC
kibuzzard-67D046A8: G***; kibuzzard-67D046A8
kibuzzard-67D046B5: G***; kibuzzard-67D046B5
kibuzzard-67D046BD: G***; kibuzzard-67D046BD
kibuzzard-67D046CC: G***; kibuzzard-67D046CC
kibuzzard-67D046F7: G***; kibuzzard-67D046F7
kibuzzard-67D046FF: G***; kibuzzard-67D046FF
kibuzzard-67D047AD: G***; kibuzzard-67D047AD
kibuzzard-67D047C3: G***; kibuzzard-67D047C3
kibuzzard-67D047D9: G***; kibuzzard-67D047D9
kibuzzard-67D047EC: G***; kibuzzard-67D047EC
kibuzzard-67D049A2, kibuzzard-67D049A2#2: G***; kibuzzard-67D049A2
kibuzzard-67D049B0, kibuzzard-67D049B0#2: G***; kibuzzard-67D049B0
kibuzzard-67D171AB: G***; kibuzzard-67D171AB
kibuzzard-67D171E5: G***; kibuzzard-67D171E5
kibuzzard-67D0352E: G***; kibuzzard-67D0352E
kibuzzard-67D0356E: G***; kibuzzard-67D0356E
kibuzzard-67D0451A: G***; kibuzzard-67D0451A
kibuzzard-67D0454D: G***; kibuzzard-67D0454D
kibuzzard-67D0455C: G***; kibuzzard-67D0455C
kibuzzard-67D0474E: G***; kibuzzard-67D0474E
kibuzzard-67D1674C: G***; kibuzzard-67D1674C
kibuzzard-67D02274: G***; kibuzzard-67D02274
kibuzzard-67D02289: G***; kibuzzard-67D02289
kibuzzard-67D02298, kibuzzard-67D02298#2: G***; kibuzzard-67D02298
kibuzzard-67D03557: G***; kibuzzard-67D03557
kibuzzard-67D03584: G***; kibuzzard-67D03584
kibuzzard-67D04501: G***; kibuzzard-67D04501
kibuzzard-67D04530: G***; kibuzzard-67D04530
kibuzzard-67D04570: G***; kibuzzard-67D04570
kibuzzard-67D04579: G***; kibuzzard-67D04579
kibuzzard-67D04612: G***; kibuzzard-67D04612
kibuzzard-67D04639: G***; kibuzzard-67D04639
kibuzzard-67D04669: G***; kibuzzard-67D04669
kibuzzard-67D04726: G***; kibuzzard-67D04726
kibuzzard-67D04771: G***; kibuzzard-67D04771
kibuzzard-67D04943: G***; kibuzzard-67D04943
kibuzzard-67D04998, kibuzzard-67D04998#2, kibuzzard-67D04998#3, kibuzzard-67D04998#4: G***; kibuzzard-67D04998
kibuzzard-67D05112: G***; kibuzzard-67D05112
kibuzzard-67D05125: G***; kibuzzard-67D05125
kibuzzard-67D16721: G***; kibuzzard-67D16721
kibuzzard-67D16775: G***; kibuzzard-67D16775
kibuzzard-67DABC7B: G***; kibuzzard-67DABC7B
kibuzzard-67DABC71: G***; kibuzzard-67DABC71
kibuzzard-67DABC87: G***; kibuzzard-67DABC87
kibuzzard-67DABED8: G***; kibuzzard-67DABED8
kibuzzard-67DAC0B5: G***; kibuzzard-67DAC0B5
kibuzzard-67DAC0E0: G***; kibuzzard-67DAC0E0
kibuzzard-67DAC106: G***; kibuzzard-67DAC106

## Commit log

2025-03-10 Schematic WIP
    [Connectors.kicad_sch, Power.kicad_sch, SparkFun_GNSS_mosaic-T.kicad_pcb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]
2025-03-11 Ready for airwire review
    [Connectors.kicad_sch, Power.kicad_sch, SparkFun_GNSS_mosaic-T.kicad_pcb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]
2025-03-12 Routing - WIP
    [Connectors.kicad_sch, SparkFun_GNSS_mosaic-T.kicad_pcb, SparkFun_GNSS_mosaic-T.kicad_sch]
2025-03-13 Re-panelized and CAMmed
    [SparkFun_GNSS_mosaic-T_panelized.GBL, SparkFun_GNSS_mosaic-T_panelized.GBO, SparkFun_GNSS_mosaic-T_panelized.GBP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]
2025-03-13 Re-panelize and CAM using released versions
    [SparkFun_GNSS_mosaic-T_panelized.GBL, SparkFun_GNSS_mosaic-T_panelized.GBO, SparkFun_GNSS_mosaic-T_panelized.GBP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]
2025-03-19 Schematic updates after proto review
    [Connectors.kicad_sch, Power.kicad_sch, SparkFun_GNSS_mosaic-T.kicad_sch]
2025-03-19 More updates, post proto review
    [Connectors.kicad_sch, SparkFun_GNSS_mosaic-T.kicad_pcb, SparkFun_GNSS_mosaic-T.kicad_sch]
2025-03-19 Re-panelized after proto review
    [SparkFun_GNSS_mosaic-T.kicad_pcb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]
2025-03-19 Remove alternate "PowerPins"
    [SparkFun_GNSS_mosaic-T.kicad_pcb, SparkFun_GNSS_mosaic-T.kicad_sch]
2025-06-12 Disciplined Oscillator
    Add instructions for creating disciplined oscillator
    Add missing image for assembly
2025-06-14 Swap the SMA cable images
2025-09-12 Update footprint
    Fixes file path and position for the 3D model
    [SparkFun_GNSS_mosaic-T.kicad_pcb]

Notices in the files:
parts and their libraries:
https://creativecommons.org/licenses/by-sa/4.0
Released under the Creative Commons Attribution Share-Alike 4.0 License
